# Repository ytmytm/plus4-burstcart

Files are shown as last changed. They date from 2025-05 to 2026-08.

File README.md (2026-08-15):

# BurstCart - Fast serial cartridge for C16/116/Plus4

This Plus/4 cartridge implements both fast serial burst for 1570/1571/1581 drives and a parallel connection for the 1541 drive, enabling high-speed data transfers.

<a href="https://www.youtube.com/watch?v=kfF7x9RVxz8" target="_blank">
 BurstCart and Parobek fastloaders demo
 <p><small>Click for video</small></p>
</a>

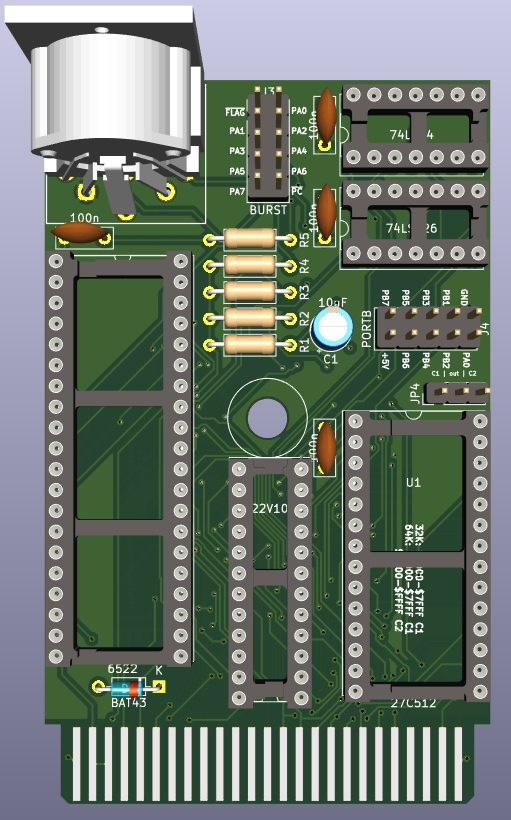
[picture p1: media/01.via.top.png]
BurstCart VIA Version

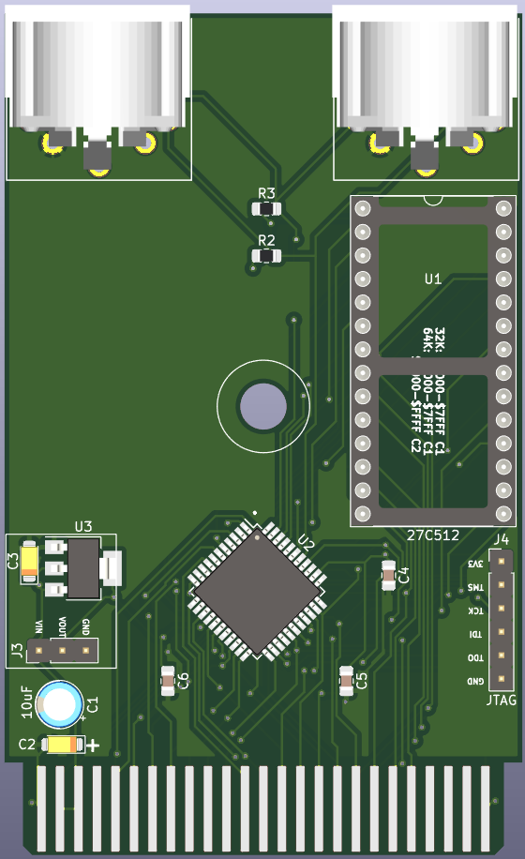
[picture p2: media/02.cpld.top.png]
BurstCart CPLD Version


## About

The project started as a response to a question from **[Plus/4 World Forum](https://plus4world.powweb.com/forum.php?postid=52378)**.

In order to use the Burst (fast serial) protocol as implemented on the C128, we need a bidirectional hardware serial port.

The published version uses VIA 6522 chips, which are still relatively easy to obtain. The additional logic addresses a VIA hardware bug that can lead to framing errors and lost bits when the serial port is externally clocked, as is the case with the fast serial burst protocol.

The single IEC port should be connected to the pass-through serial port on the last disk drive in the chain, looping back to the computer.

VIA Port A and lines CA1/CA2 are also used as a parallel connection for 1541 parallel burst with hardware handshake. The order of signals on the J3 connector for a ribbon cable is compatible with parallel cables known from the C64, particularly DolphinDOS.

VIA Port B is not used, except for bit 0, which controls the direction of the serial port.

Other attempts included in the repository are:

### CPLD

This is an attempt to drop legacy chips altogether.

Due to the limited number of gates, it only implements small parts of the CIA, such as timer A with a fixed rate, the hardware serial port, and the status register. The implementation does only what it necessary to make burst protocol work: to be able to send a byte via burst to enable burst protocol and to receive bytes on serial port with external clock.

### CIA (6526) - abandoned

This seemed obvious as CBM themselves added CIA just for this purpose to 1571. However, the timing differences made it impossible to use the CIA reliably with the screen on.

These chips are also hard to obtain.

The PCB had enough space for two IEC ports as a passthrough.

## Hardware

### VIA

KiCad 6.0 project files are available in the [`burstcart-via/kicad/`](burstcart-via/kicad/) directory.

Schematic is available as [`burstcart-via.pdf`](burstcart-via/kicad/plots/burstcart-via.pdf) in the `burstcart-via/kicad/plots/` directory.

Gerber files for manufacturing are available from [`burstcart-via/kicad/plots/`](burstcart-via/kicad/plots/) directory.

### CPLD

KiCad 6.0 project files are available in the [`burstcart-cpld/kicad/`](burstcart-cpld/kicad/) directory.

Schematic is available as [`burstcart-cpld.pdf`](burstcart-cpld/kicad/plots/burstcart-cpld-44.pdf) in the `burstcart-cpld/kicad/plots/` directory.

Gerber files for manufacturing are available from [`burstcart-cpld/kicad/plots/`](burstcart-cpld/kicad/plots/) directory.

## Firmware 

### VIA

The firmware for the GAL22V10 programmable logic device is provided as a compiled JEDEC file [`BURSTCART-VIA.jed`](burstcart-via/gal/BURSTCART-VIA.jed).

The source code for the GAL logic is written in CUPL and available as [`burstcart-via.pld`](burstcart-via/gal/burstcart-via.pld). This file contains the logic equations that implement the address decoding and serial port direction control.

The GAL firmware fixes VIA's address at `$FDA0-$FDAF` range.

### CPLD

The CPLD firmware is also provided as a compiled JEDEC file [`CIA.jed`](burstcart-cpld/hdl/ciasdr-hdl/cia.jed).

The source code is written in Verilog for XILINX ISE. All the project files are provided in [`ciasdr-hdl`](burstcart-cpld/hdl/ciasdr-hdl).

The firmware fixes CPLD address at `$FD90-$FD9F` range.

## Software

### EPROM

The GAL chip on the VIA version does not have enough space to support 64K ROMs as C1/C2 cartridges, so only 32K is visible to the computer at any given time as C1.

You can use 32K chips; for the 64K version, the 32K banks can be selected using a switch connected to JP4.

The CPLD version can address both C1 and C2 cartridges, so all 64K is available.

The **[Parobek](https://github.com/ytmytm/plus4-parobek)** project provides a ROM that supports various fastloaders for BurstCart:

- autodetected fast serial burst for 1570/1571/1581
- parallel cable loader for 1541
- even faster parallel cable loader for 1541 with [1541-RAMBOard](https://github.com/ytmytm/1541-RAMBOardII) patched ROM
- [tcbm2sd fastloader](https://github.com/ytmytm/plus4-tcbm2sd) for both device numbers
- 1551 fastloader for both device numbers
- DOS wedge
- embedded Directory Browser

Be sure to choose correct ROM version - for VIA or CPLD.

## VIA PCB jumpers

There are three jumpers on the VIA PCB:

- JP1 determines how the `/IRQ` line is connected to the VIA. For W65C22S, it should go through a diode; for all other 6522 versions, it can be connected directly, and `D1` can be omitted.
- JP2 chooses the clock for VIA - `phi0` or `phi2` (default)
- JP3 chooses the clock for GAL - `phi0` (default) or `phi2`
- JP4 controls line A15 for the EPROM and chooses which 32K half of a 64K ROM will appear as cartridge C1

## Theory of operation

### Fast serial

The burst mode protocol were originally developed by Commodore for the C128 and 1571/1581 drives. It uses the hardware serial port available on VIA and CIA chips. The data is transmitted over the IEC data line, with the hardware clock controlled by the sender and routed through the (otherwise unused) SRQ line. Changes in the IEC clock line are used as a handshake signal.

This was not available on the 1541 due to a hardware bug in the 6522 chips.

This project fixes the bug with a 74LS74 latch. Another 74LS126 chip is needed to buffer the input/output and provide the necessary open collector outputs on the external side for both the clock and data lines. The direction of the bus is controlled by port B bit 0 (PB0) pulled high to make it input as a default after reset.

The single IEC port on the VIA cartridge has only the hardware data and clock lines connected, as well as a common GND.

The CPLD cartridge has dual daisy-chained IEC ports, so you can connect the computer's serial port to cartridge and continue from the second port to all other IEC devices.

### Parallel cable

The 1541 drive's VIA#1 port A is unused. On the C64, this is connected to the User Port, along with two hardware handshake lines, providing the fastest possible connection between the VIA and CIA.

Here we connect it to port A as well. Note that on the BurstCart side, the handshake lines are connected to CA1/CA2 corresponding to port A, but to CA2/CB1 on the 1541 side. This is not symmetrical because on the 1541, CA1 from VIA#1 was already used for another purpose.

## Additional Resources

All files necessary for manufacturing, including Gerbers, schematic, GAL firmware, and ROM, can be found in the [GitHub releases section](https://github.com/ytmytm/plus4-burstcart/releases).

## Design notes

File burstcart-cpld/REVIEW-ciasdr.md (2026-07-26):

# Dlaczego burstcart-cpld-44 gubi bajty i przesuwa bity

Analiza z 2026-07-26. Hipoteza z `PROMPT.txt` była trafna w jednym punkcie
(problem jest w firmware CPLD), ale **nietrafna w założeniu, że układ KiCad
odpowiada temu, co robi wersja VIA** — płytki różnią się elektrycznie i to jest
sedno sprawy.

---

## 1. Fakty ustalone z dokumentacji i ROMu (nie domysły)

### Co robi stacja 1581

Z ROMu 1581 (`1581-rom/AAY1581.TXT`), inicjacja w `$AF3A`:

```
AF3A: A9 00     LDA #$00         Timer A fuer FSM auf $0006 stellen
AF3C: 8D 05 40  STA $4005
AF3F: A9 06     LDA #$06
AF41: 8D 04 40  STA $4004
```

Timer A = 6 przy 2 MHz → underflow co 3,5 µs, CNT przełącza się na każdym
underflow, więc:

| parametr | wartość |
|---|---|
| okres bitu | **7 µs** |
| faza CNT wysoka / niska | 3,5 µs / 3,5 µs (50 % duty) |
| bajt (8 bitów) | 56 µs |
| turnaround stacji (ack → pierwszy bit) | ~27 µs |
| kolejność bitów | MSB first |

Nadajnik to sprzętowy SDR w CIA, nigdzie nie ma bit-bangingu SRQ. Blok
fastload (`$B977`) wysyła bajty przez `$01FC → $BA40`, a handshake to
**porównanie poziomu**, nie zbocze: `EOR $76 / AND #$04` — więc ack hosta
może przyjść w dowolnym momencie i nie zginie.

### Które zbocze i gdzie są dane

Datasheet 6526 (`docs/mos_6526_cia_preliminary_nov_1981.pdf`, s. 7), dosłownie:

> „In input mode, data on the SP pin is shifted into the shift register **on the
> rising edge** of the signal applied to the CNT pin."
>
> „Data shifted out becomes valid **on the falling edge of CNT** and remains
> valid until the next falling edge."

To samo u Ojali (`docs/c=hacking19.txt`): *„A bit is valid between clock falling
edges, the data is sampled during rising edges."*

Czyli: dane zmieniają się na zboczu **opadającym**, a zbocze **narastające**
leży dokładnie w środku bitu, z 3,5 µs marginesu z każdej strony. `posedge CNT`
w `ciasdr.v` jest więc semantycznie **poprawne** — i nie ma żadnej inwersji na
ścieżce (SP/CNT są open-drain i idą wprost na magistralę IEC, potwierdzone i w
datasheecie, i w schematach obu płytek). Polaryzacja **nie jest** problemem.

### Czym różni się pracująca płytka VIA — to jest klucz

Ze schematów (`*.kicad_sch` + netlisty z `.kicad_pcb`):

| ścieżka | burstcart-via (działa) | burstcart-cpld-44 (nie działa) |
|---|---|---|
| SRQ → zegar SR | `IEC_SRQ` → **74LS74 (U2A), D=SRQ, CLK=/VIACLK (Phi2)** → 74LS126 (U5B) → CB1 (pin 18) | `IEC_SRQ` → **wprost na pin 43 CPLD** |
| DATA → dane SR | `IEC_DATA` → 74LS126 (U5C) → CB2 (pin 19) | `IEC_DATA` → wprost na pin 38 |
| pull-up | R3/R2 3k3 → VCC | R3/R2 3k3 → VCC (identyczne) |
| inwersje | 0 | 0 |
| złącza IEC | jedno (J1) | **dwa (J1+J2, przelotka)** |

Na płytce VIA jest **przerzutnik 74LS74, który resynchronizuje SRQ do zegara
systemowego, zanim trafi na CB1**. To nie przypadek — `docs/via.txt` mówi
wprost:

> „To remedy it, put the external clock signal into the D input of a 74HC74
> flip-flop, run the flip-flop's Q output to the 6522's CB1 pin, and clock the
> flip-flop with phase 0 or phase 2."

A sam 6522 dodatkowo próbkuje synchronicznie. Datasheet W65C22 §2.12.4 (tryb
011, ten używany w `burst-via.asm`: `lda #%00001100 / sta via_acr`):

> „Note that data is shifted **during the first PHI2 clock cycle following the
> positive going edge of the CB1 shift pulse**. For this reason, data must be
> held stable during the first full cycle following CB1 going high."

I druga, równie ważne zdanie z tego samego akapitu:

> „**Reading or writing the SR resets IFR2 and initializes the counter to count
> another eight pulses.**"

---

## 2. Trzy usterki w `ciasdr.v`

### Usterka 1 (główna): surowa linia IEC SRQ użyta jako zegar sprzętowy

```verilog
always @(posedge CNT or negedge sp_in_reset_n) begin
    ...
    shift_in <= {shift_in[6:0], SP};
```

`CNT` to pin 43, zmapowany przez fitter na **globalną sieć zegarową GCK1**
(`cia.rpt:29`). Czyli rejestr przesuwny jest taktowany bezpośrednio linią
magistrali IEC, która:

* jest open-drain z pull-upem 3k3 do +5 V, obciążonym kablem i **dwoma**
  złączami IEC → zbocze narastające to wolna rampa RC rzędu 0,5–1 µs;
* wchodzi na wejście zegarowe **XC9572XL, które nie ma histerezy** (a to część
  3,3 V, więc próg jest jeszcze niżej względem 5 V rampy).

Każde zakłócenie na tej rampie przekracza próg po raz drugi i **taktuje rejestr
przesuwny ponownie**. Jeden dodatkowy impuls = jeden fantomowy bit = bajt
obrócony, flaga „bajt gotowy" wypada o zbocze za wcześnie, i od tego momentu
cały strumień jest przesunięty. Dokładnie objaw z `PROMPT.txt`.

Żaden z prawdziwych układów tego nie robi: 6522 próbkuje w rytmie PHI2, a
płytka VIA dodaje jeszcze 74LS74. Prawdziwe CIA to NMOS na tej właśnie
magistrali. CPLD z propagacją ~5 ns na rampie 1 µs — nie.

### Usterka 2: licznik bitów nigdy się nie resynchronizuje

Stary licznik `shift_in_counter` był zerowany **tylko** przez RESET albo przez
przełączenie portu na wyjście (`sp_in_reset_n = RESET_n && !sp_output`). W
trakcie całej transmisji software nie pisze do `cpldbase+1`, więc licznik biegnie
swobodnie modulo 8. Pojedyncze zgubione albo dodatkowe zbocze przesuwa **na
zawsze** wszystkie kolejne bajty — nie ma bitu startu, jedynym framingiem jest
ten licznik.

Że to realne ryzyko, wie sam ROM 1581 (`AAY1581.TXT`, blok patchy
„FSM: Schieberegister initialisieren"):

> „Wenn erst der Computer und dann die 1581 eingeschaltet wird, kann es
> vorkommen, dass im Computer irrtuemlich ein paar Bits ‚empfangen' werden.
> **Bei einer Datenuebertragung wuerde der Computer anschliessend alle Bits
> verschoben empfangen.**"

Dlatego stacja przed **każdą** transmisją przełącza kierunek SDR 0→1→0
(`$DBC7`/`$DBE0`), żeby wyzerować swój własny licznik. Dodatkowo stacja wysyła
przed transferem bajt-budzik `$00` (`$AC9D`) i owija bajty statusu w kolejne
przełączenia kierunku — na drucie jest więc więcej ruchu, niż widzi pętla
loadera.

6522 jest odporny, bo zeruje licznik przy każdym czytaniu SR — i to jest powód,
dla którego wersja VIA sama się leczy.

### Usterka 3: flaga statusu próbkowała magistralę na złym zboczu

```verilog
always @(posedge E_CLK or negedge RESET_n) begin        // <-- posedge
    ...
    else if (seladdr && RW && A[0] == REG_SDR)
        shift_complete_latched <= 1'b0;
```

Na Plus/4 przy narastającym zboczu PHI0 magistrala adresowa **jeszcze nie
trzyma adresu CPU**. Wszystkie zapisy rejestrów w tym samym pliku używają
`negedge E_CLK` — i one działają (potwierdzone: rejestry dają się zapisywać, a
Twoje notatki w `docs/burstc64.txt` zapisują regułę Plus/4:
*„drivedatain: adres+<WRITE>+negedge pla[6] (zapis do rejestru)"*). Czyli
„skasuj flagę przy odczycie rejestru danych" wypadało w złym momencie albo
wcale.

To jest **regresja wprowadzona później**: w raporcie fittera z 2026-03-07
(`cia.rpt`) ten sam przerzutnik jest jeszcze na `NOT E_CLK`, czyli na zboczu
opadającym. Ta sama wersja miała też dwustopniowy synchronizator
`req_sync1`/`req_sync2` na przejściu domen, którego w obecnym `ciasdr.v` już nie
ma.

### Uwaga na marginesie: plik JED nie odpowiada żadnemu źródłu

```
cia.jed             Date Extracted: Thu May 29 23:38:38 2025
cia — kopia.jed     Date Extracted: Thu May 29 00:23:47 2025
cia.jed-20250608    Date Extracted: Thu May 29 23:38:38 2025
```

Wszystkie trzy pliki programujące są z **28–29 maja 2025**, mimo że mtime
`cia.jed` to 2026-03-07. Raport fittera i `cia.vm6` są z 2026-03-07 12:55 i
zawierają `req_sync1`/`req_sync2`, których nie ma w żadnym `.v` na dysku, a samo
`ciasdr.v` było edytowane jeszcze później (22:16). Czyli **układ na płytce
zawiera logikę z 29 maja 2025, nie tę, którą debugujemy.** Warto to
uporządkować, zanim wyciągnie się wnioski z kolejnego testu na sprzęcie.

---

## 3. Symulacja

`sim/burstsim.py` i `sim/verify_new.py` modelują nadajnik 1581 (7 µs/bit, dane
na zboczu opadającym, handshake per bajt), pętlę `GetByte`/`GetAndStore` z
`parobek/burst-cpld.asm` z prawdziwymi liczbami cykli 6502, oraz trzy odbiorniki:
stary `ciasdr.v`, nowy `ciasdr.v` i układ z płytki VIA (74LS74 + 6522 tryb 011).

`verify_new.py` to model **cyklicznie dokładny** — po przepisaniu całego
projektu na jedną domenę (`negedge E_CLK`) jedna ewaluacja na okres PHI0
odtwarza RTL dokładnie.

```
PHI0 = 0.887 MHz (1128 ns), 1581 bit period 7.0 us (3.10 PHI0 cycles per CNT phase)

1. wake-up handshake (CRA=$40, SDR=$08, poll bit 3): flag raised after 30 PHI0
   cycles, 8 CNT pulses generated

2. clean 1581 stream
   new ciasdr.v          recv=24/24 correct=24 wrong_at=[]                 -> PASS
   old ciasdr.v          recv=24/24 correct=24 wrong_at=[]                 -> PASS

3. 200 ns threshold re-crossing on every SRQ rising edge
   new ciasdr.v          recv=24/24 correct=24 wrong_at=[]                 -> PASS
   old ciasdr.v          recv=24/24 correct= 0 wrong_at=[0,1,2,3,4,5]      -> FAIL

4. one stray SRQ pulse after byte 5 (recovery behaviour)
   new ciasdr.v          recv=24/24 correct=24 wrong_at=[]                 -> PASS
   old ciasdr.v          recv=24/24 correct= 6 wrong_at=[6,7,8,9,10,11]    -> FAIL
```

Test 3 to usterka 1: **jedno przekroczenie progu o szerokości 200 ns na każdym
zboczu narastającym psuje wszystkie bajty**, a dla wersji synchronicznej jest
całkowicie niewidoczne. Test 4 to usterka 2: jeden zabłąkany impuls psuje stary
projekt **od tego bajtu do końca**, nowy odzyskuje synchronizację natychmiast.

Zamiatanie szerokości zakłócenia (`burstsim.py`, sekcja sweep) pokazuje granice:

```
  glitch      PHI0 |   cpld_old          cpld_new           via_ref
    50ns  0.887MHz |       PASS              PASS              PASS
   100ns  0.887MHz |       FAIL              PASS              PASS
   200ns  0.887MHz |       FAIL              PASS              PASS
   400ns  0.887MHz |       FAIL              FAIL              FAIL
```

Nowa wersja ma **dokładnie taką samą odporność jak płytka, która działa** —
i to był cel, nie „lepiej niż VIA". Przy zakłóceniach ≳1/3 okresu PHI0 obie
padają jednakowo; to obszar, w którym pomoże już tylko sprzęt.

Osobny test w `burstsim.py` (przypadek E) pokazuje usterkę 3 w izolacji: przy
czystym sygnale, ale próbkowaniu magistrali w złym momencie, stary projekt
odbiera **0 bajtów** — czyli zawisa, tak jak w notatce z 20250530.

---

## 4. Co zostało zmienione w `ciasdr.v`

Cały projekt jest teraz w **jednej domenie zegarowej: `negedge E_CLK` (PHI0)**.

1. `CNT` i `SP` są synchronizowane do PHI0 (`cnt_s1/s2/s3`, `sp_s1/s2`) i zbocze
   narastające jest detekowane w tej domenie. `sp_s2` jest próbkowane w tym samym
   cyklu, w którym `cnt_s2` pierwszy raz zobaczył CNT wysoko — czyli w granicach
   1,2 µs od zbocza, przy 3,5 µs ważności danych z każdej strony.
   Budżet: faza CNT = 3,5 µs = **3,10 cyklu PHI0** przy 0,886 MHz i 6,2 przy
   1,77 MHz — sprawdzone symulacją na obu prędkościach (ekran włączony/wyłączony).
2. `shift_in_counter` jest zerowany przy **każdym dostępie do rejestru danych**
   (`acc_sdr`), czyli framing resynchronizuje się raz na bajt — zachowanie 6522.
   Nadal zerowany też przy przełączeniu na wyjście (zachowanie prawdziwego CIA,
   na którym opiera się ROM 1581).
3. `shift_complete_latched` jest na `negedge E_CLK`, tak samo jak zapisy
   rejestrów, które działają.
4. Efekt uboczny: `CNT` przestaje być zegarem, więc zwalnia globalną sieć GCK1.
   Ścieżka nadawania straciła niepotrzebny bufor drugiego bajtu
   (`sdr_out_new_data`) — software wysyła tylko jeden bajt-budzik, którego
   zawartość nie ma znaczenia. Liczba przerzutników bez zmian (47), liczba
   termów iloczynowych spada, więc powinno zmieścić się swobodniej niż
   poprzednie 66/72 makrokomórek.

Poprzednia wersja jest w `ciasdr-orig-backup.v`.

## 5. Czego nie sprawdziłem / co zrobić dalej

* **Nie przesyntetyzowałem projektu** — na tej maszynie nie ma ISE. Trzeba
  przepuścić przez XST + cpldfit i sprawdzić, czy mieści się w 72 makrokomórkach
  (przewiduję tak, ale FB1/FB2/FB4 były wyczerpane przy 18/18).
* **Zaprogramować świeży JED** — obecny jest z maja 2025 i nie odpowiada
  żadnemu źródłu w projekcie.
* Jeśli po tym nadal będą błędy: dodać na płytce to, co ma wersja VIA, czyli
  przerzutnik resynchronizujący SRQ (74HC74 taktowany PHI0) albo bufor z
  histerezą (74HCT14 / 74LVC1G17) na SRQ i DATA przed CPLD. Firmware tego już
  nie potrzebuje, ale przy zakłóceniach >400 ns nic innego nie pomoże.
* Rozważyć dołożenie `!MUX` do dekodera zapisu i kasowania flagi. **Nie zrobiłem
  tego celowo** — zapisy rejestrów bez `!MUX` demonstracyjnie działają, więc
  dokładanie tam warunku to ryzyko regresji. Warto spróbować tylko jeśli po
  powyższych zmianach zostaną sporadyczne błędy.

---

## 6. Zgodność z `parobek/burst-cpld.asm` — kod 6502 bez zmian

Mapa rejestrów, semantyka flagi i bitu kierunku są nietknięte:

| adres | R | W |
|---|---|---|
| `$FD90` (`cpldbase`) | dane odebrane (`sdr_in`); kasuje flagę **i resynchronizuje licznik bitów** | dane do wysłania, start nadawania |
| `$FD91` (`cpldbase+1`) | bit 6 = kierunek, bit 3 = shift complete; **nie** kasuje flagi | bit 6 = kierunek; kasuje flagę |

Jedyna zmiana widoczna dla software'u to zerowanie licznika bitów przy dostępie
do `$FD90` — a to jest dokładnie to, co loader i tak robi raz na bajt
(`ldy cpldbase` w `GetByte`), więc wychodzi „za darmo". Dodatkowo `lda cpldbase`
przed `jsr ToggleClk` na starcie transferu ustawia framing tuż przed pierwszym
bajtem.

`sim/test_init.py` odtwarza dosłownie sekwencję `InitBurst` + detekcję CPLD z
`burst-cpld.asm` (z prawdziwymi liczbami cykli) na modelu nowego RTL:

```
InitBurst:
   [ok ] sta $FD91,#$00  -> sp_output = 0 (serial IN)
   [ok ]                 -> flag cleared
LoadBurst, CPLD presence detection:
   [ok ] lda $FD91 / cmp $FD91  -> $00 == $00 (branch not taken)
   [ok ] sta $FD91,#$40 / cmp $FD91 -> $40 == $40
   [ok ] sta $FD90,#$08 -> transmit started
   [ok ] wait loop  -> flag raised at Y=5 (timeout is Y=128)
   [ok ] sta $FD91,#$00 -> back to serial IN
   [ok ]                -> flag cleared, ready to receive
   [ok ]                -> receive bit counter aligned at 0

RESULT: burst-cpld.asm needs NO change
```

Czyli: **wystarczy nowy JED.** Zmiana ROMu parobka nie jest potrzebna.

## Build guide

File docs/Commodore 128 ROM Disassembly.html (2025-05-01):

# Commodore 128 ROM Disassembly

done for The IDE64 Project by Soci/Singular (Kajtár Zsolt)
Version 4 (Jan 2002) Still preview!
Modified and with extended comments by Johann Klasek

Used firmware:

$4000-$7FFF: 318018-04

$8000-$BFFF: 318019-04

$C000-$FFFF: 318077-01

Send bugreports for the original version to <soci at c64.rulez.org>
Send bugreports to this version to <j+c64 at klasek DOT at>

See also C128 zero page (german) (https://www.c64-wiki.de/wiki/C128-Zeropagebelegung)

               * = $4000

; Cold Entry

4000: 4C 23 40	JMP $4023	; Basic Cold Start

; Warm Entry

4003: 4C 09 40	JMP $4009	; Basic Restart

; IRQ Entry

4006: 4C 4D A8	JMP $A84D	; IRQ Work

; Basic Restart

4009: 20 CC FF	JSR $FFCC	; (iclrch)      Restore I/O Vector [F226]
400C: 20 7A 41	JSR $417A	; Set Preconfig Registers
400F: 20 8D 41	JSR $418D	; Init Sprite Movement Tabs
4012: 20 12 41	JSR $4112	; Chime
4015: 20 38 52	JSR $5238	; Clear Stack & Work Area
4018: A9 00	LDA #$00
401A: 85 15	STA $15 	; Current I/O prompt flag

401C: 58	CLI
401D: 4C 37 4D	JMP $4D37	; Error or Ready

; Unused

4020: 00 FF FF               	; '{0}..'

; Basic Cold Start

4023: 20 7A 41	JSR $417A	; Set Preconfig Registers
4026: 20 51 42	JSR $4251	; Set Basic Links
4029: 20 45 40	JSR $4045	; Set-Up Basic Constants
402C: 20 9B 41	JSR $419B	; Print Startup Message
402F: AD 04 0A	LDA $0A04
4032: 09 01	ORA #$01
4034: 8D 04 0A	STA $0A04
4037: A2 03	LDX #$03
4039: 8E 00 0A	STX $0A00	; Restart System (BASIC Warm) [4000]
403C: A2 FB	LDX #$FB
403E: 9A	TXS
403F: 20 56 FF	JSR $FF56	; foenix
4042: 4C 1C 40	JMP $401C

; Set-Up Basic Constants

4045: A9 4C	LDA #$4C
4047: 85 56	STA $56
4049: 8D 18 12	STA $1218	; USR Program Jump [7D28]
404C: A9 28	LDA #$28
404E: A0 7D	LDY #$7D
4050: 8D 19 12	STA $1219
4053: 8C 1A 12	STY $121A
4056: A9 9F	LDA #$9F
4058: A0 84	LDY #$84
405A: 8D 7A 11	STA $117A	; Float-fixed Vector [849F]
405D: 8C 7B 11	STY $117B
4060: A9 3C	LDA #$3C
4062: A0 79	LDY #$79
4064: 8D 7C 11	STA $117C	; Fixed-float Vector [793C]
4067: 8C 7D 11	STY $117D
406A: A2 55	LDX #$55

406C: BD 78 42	LDA $4278,X
406F: 9D 7F 03	STA $037F,X
4072: CA	DEX
4073: D0 F7	BNE $406C
4075: 8E DF 03	STX $03DF	; FAC#1 Overflow
4078: 86 15	STX $15 	; Current I/O prompt flag
407A: 86 1A	STX $1A
407C: 8E 6F 11	STX $116F	; Trace Mode: FF = on
407F: 8E 00 1C	STX $1C00
4082: 86 76	STX $76 	; Graphics flag: FF = Graphics allocated
4084: 86 74	STX $74 	; Auto line number increment
4086: 86 75	STX $75
4088: 8E 6B 11	STX $116B	; Double Width Flag
408B: 8E 6A 11	STX $116A	; SCALE Mode Flag
408E: 8E 6C 11	STX $116C	; Box Fill Flag
4091: 8E 1B 12	STX $121B
4094: 8E 1C 01	STX $011C
4097: 8E 76 12	STX $1276	; Collision IRQ Task Table
409A: 8E 77 12	STX $1277
409D: 8E 78 12	STX $1278
40A0: 8E 7F 12	STX $127F	; Collision Mask
40A3: A0 58	LDY #$58

40A5: 99 7E 11	STA $117E,Y	; Sprite Motion Tables (8 x 11 bytes)
40A8: 88	DEY
40A9: 10 FA	BPL $40A5
40AB: E8	INX
40AC: 8E FD 01	STX $01FD
40AF: 8E FC 01	STX $01FC
40B2: A2 0F	LDX #$0F
40B4: 8E D5 03	STX $03D5	; Current Bank For SYS, POKE, PEEK
40B7: A2 0D	LDX #$0D
40B9: 86 86	STX $86 	; Graphic foreground color (13)
40BB: A2 01	LDX #$01
40BD: 86 84	STX $84 	; Multicolor 1 (1)
40BF: A2 02	LDX #$02
40C1: 86 85	STX $85 	; Multicolor 2 (2)
40C3: 20 5C 6A	JSR $6A5C	; Log Current Colors
40C6: A2 1B	LDX #$1B
40C8: 86 18	STX $18
40CA: A2 01	LDX #$01
40CC: A0 1C	LDY #$1C
40CE: 86 2D	STX $2D 	; Pointer: Start-of-BASIC (bank 0)
40D0: 84 2E	STY $2E
40D2: A9 00	LDA #$00
40D4: A0 04	LDY #$04
40D6: 85 2F	STA $2F 	; Pointer: Start-of-variables (bank 1)
40D8: 84 30	STY $30
40DA: A9 00	LDA #$00
40DC: A0 FF	LDY #$FF
40DE: 8D 12 12	STA $1212	; Basic Program Limit [FF00]
40E1: 8C 13 12	STY $1213
40E4: A9 00	LDA #$00
40E6: A0 FF	LDY #$FF
40E8: 85 39	STA $39 	; Pointer: Limit-of-memory (bank 1)
40EA: 84 3A	STY $3A
40EC: A2 3F	LDX #$3F
40EE: A0 07	LDY #$07

40F0: 8A	TXA
40F1: 99 F8 07	STA $07F8,Y
40F4: CA	DEX
40F5: 88	DEY
40F6: 10 F8	BPL $40F0
40F8: A9 00	LDA #$00
40FA: A2 6C	LDX #$6C

40FC: 9D 7E 11	STA $117E,X	; Sprite Motion Tables (8 x 11 bytes)
40FF: CA	DEX
4100: 10 FA	BPL $40FC
4102: 20 12 41	JSR $4112	; Chime
4105: A9 D0	LDA #$D0
4107: 8D EC 11	STA $11EC	; CHRGEN ROM Page, Graphics Mode [D0]
410A: A9 D8	LDA #$D8
410C: 8D EB 11	STA $11EB	; CHRGEN ROM Page, Text Mode [D8]
410F: 4C D9 51	JMP $51D9

; Chime

4112: A9 20	LDA #$20
4114: A0 01	LDY #$01
4116: 8D 29 12	STA $1229
4119: 8C 2A 12	STY $122A
411C: A9 04	LDA #$04
411E: 8D 2B 12	STA $122B
4121: A9 10	LDA #$10
4123: 8D 22 12	STA $1222
4126: A9 00	LDA #$00
4128: 8D 04 D4	STA $D404
412B: 8D 0B D4	STA $D40B
412E: 8D 12 D4	STA $D412
4131: 8D FD 12	STA $12FD
4134: A9 0F	LDA #$0F
4136: 8D 74 12	STA $1274
4139: 8D 75 12	STA $1275
413C: 8D 18 D4	STA $D418
413F: A0 1D	LDY #$1D

4141: B9 11 70	LDA $7011,Y	; Envelope A/D Patterns
4144: 99 3F 12	STA $123F,Y
4147: 88	DEY
4148: 10 F7	BPL $4141
414A: A2 09	LDX #$09

414C: BD 2F 70	LDA $702F,X	; Chime Seq
414F: 9D 67 12	STA $1267,X
4152: CA	DEX
4153: 10 F7	BPL $414C
4155: 8E 85 12	STX $1285
4158: 8E 86 12	STX $1286
415B: 8E 87 12	STX $1287
415E: 8E 24 12	STX $1224
4161: 8E 26 12	STX $1226
4164: 8E 28 12	STX $1228
4167: A0 02	LDY #$02
4169: 8C 2F 12	STY $122F

416C: A2 00	LDX #$00
416E: 20 B2 6E	JSR $6EB2	; Set SID Sound
4171: CE 2F 12	DEC $122F
4174: 10 F6	BPL $416C
4176: EE 2F 12	INC $122F
4179: 60	RTS

; Set Preconfig Registers

417A: 20 45 A8	JSR $A845	; Set Bank 15
417D: A2 03	LDX #$03

417F: BD 89 41	LDA $4189,X	; Registers For $D501
4182: 9D 01 D5	STA $D501,X
4185: CA	DEX
4186: 10 F7	BPL $417F
4188: 60	RTS

; Registers For $D501

4189: 3F 7F 01 41            	; '?..a'

; Init Sprite Movement Tabs

418D: A9 00	LDA #$00
418F: A0 07	LDY #$07

4191: BE D9 6D	LDX $6DD9,Y	; Sprite Motion Table Offsets
4194: 9D 7E 11	STA $117E,X	; Sprite Motion Tables (8 x 11 bytes)
4197: 88	DEY
4198: 10 F7	BPL $4191
419A: 60	RTS

; Print Startup Message

419B: A0 00	LDY #$00

419D: B9 BB 41	LDA $41BB,Y	; Startup Message
41A0: C9 40	CMP #$40
41A2: D0 0E	BNE $41B2
41A4: 24 D7	BIT $D7 	; 40 / 80 columns:  0 = 40, 128 = 80
41A6: 10 0D	BPL $41B5
41A8: A2 13	LDX #$13

41AA: A9 20	LDA #$20
41AC: 20 69 92	JSR $9269	; Call 'chrout'
41AF: CA	DEX
41B0: D0 F8	BNE $41AA

41B2: 20 69 92	JSR $9269	; Call 'chrout'

41B5: C8	INY
41B6: C0 96	CPY #$96
41B8: D0 E3	BNE $419D
41BA: 60	RTS

; Startup Message

41BB: 93 0D 40 20 43 4F 4D 4D	; '{CLR}{CR}@ comm'
41C3: 4F 44 4F 52 45 20 42 41	; 'odore ba'
41CB: 53 49 43 20 56 37 2E 30	; 'sic v7.0'
41D3: 20 31 32 32 33 36 35 20	; ' 122365 '
41DB: 42 59 54 45 53 20 46 52	; 'bytes fr'
41E3: 45 45 0D 40 20 20 20 28	; 'ee{CR}@   ('
41EB: 43 29 31 39 38 36 20 43	; 'c)1986 c'
41F3: 4F 4D 4D 4F 44 4F 52 45	; 'ommodore'
41FB: 20 45 4C 45 43 54 52 4F	; ' electro'
4203: 4E 49 43 53 2C 20 4C 54	; 'nics, lt'
420B: 44 2E 0D 40 20 20 20 20	; 'd.{CR}@    '
4213: 20 20 20 20 20 28 43 29	; '     (c)'
421B: 31 39 37 37 20 4D 49 43	; '1977 mic'
4223: 52 4F 53 4F 46 54 20 43	; 'rosoft c'
422B: 4F 52 50 2E 0D 40 20 20	; 'orp.{CR}@  '
4233: 20 20 20 20 20 20 20 20	; '        '
423B: 20 41 4C 4C 20 52 49 47	; ' all rig'
4243: 48 54 53 20 52 45 53 45	; 'hts rese'
424B: 52 56 45 44 0D 00      	; 'rved{CR}{0}'

; Set Basic Links

4251: A2 11	LDX #$11

4253: BD 67 42	LDA $4267,X	; Basic Links for $0300
4256: 9D 00 03	STA $0300,X	; Error Message Link [4D3F]
4259: CA	DEX
425A: 10 F7	BPL $4253
425C: A9 78	LDA #$78
425E: 8D FC 02	STA $02FC	; Function Execute Hook [4C78]
4261: A9 4C	LDA #$4C
4263: 8D FD 02	STA $02FD
4266: 60	RTS

; Basic Links for $0300

4267: 3F 4D	.WORD $4D3F	; Error Message
4269: C6 4D	.WORD $4DC6	; BASIC Warm Start
426B: 0D 43	.WORD $430D	; Crunch BASIC Tokens
426D: 51 51	.WORD $5151	; Print Tokens
426F: A2 4A	.WORD $4AA2	; Start New BASIC Code
4271: DA 78	.WORD $78DA	; Get Arithmetic Element
4273: 21 43	.WORD $4321	; Crunch FE
4275: CD 51	.WORD $51CD	; List FE
4277: A9 4B	.WORD $4BA9	; Execute FE

; Chrget for $0380

4279: E6 3D	INC $3D 	; Textpointer: BASIC work point (chrget)
427B: D0 02	BNE $427F
427D: E6 3E	INC $3E

427F: 8D 01 FF	STA $FF01
4282: A0 00	LDY #$00
4284: B1 3D	LDA ($3D),Y	; Textpointer: BASIC work point (chrget)
4286: 8D 03 FF	STA $FF03
4289: C9 3A	CMP #$3A
428B: B0 0A	BCS $4297
428D: C9 20	CMP #$20
428F: F0 E8	BEQ $4279	; Chrget for $0380
4291: 38	SEC
4292: E9 30	SBC #$30
4294: 38	SEC
4295: E9 D0	SBC #$D0

4297: 60	RTS

; Fetch From RAM Bank 0 for $039F

4298: 8D A6 03	STA $03A6
429B: 8D 01 FF	STA $FF01
429E: B1 00	LDA ($00),Y
42A0: 8D 03 FF	STA $FF03
42A3: 60	RTS

; Fetch From RAM Bank 1 for $03AB

42A4: 8D B2 03	STA $03B2
42A7: 8D 02 FF	STA $FF02
42AA: B1 00	LDA ($00),Y
42AC: 8D 04 FF	STA $FF04
42AF: 60	RTS

; Index1 Indirect Fetch From RAM Bank 1 for $03B7

42B0: 8D 02 FF	STA $FF02
42B3: B1 24	LDA ($24),Y
42B5: 8D 04 FF	STA $FF04
42B8: 60	RTS

; Index2 Indirect Fetch From RAM Bank 0 for $03C0

42B9: 8D 01 FF	STA $FF01
42BC: B1 26	LDA ($26),Y
42BE: 8D 03 FF	STA $FF03
42C1: 60	RTS

; Txtptr Fetch From RAM Bank 0 for $03C9

42C2: 8D 01 FF	STA $FF01
42C5: B1 3D	LDA ($3D),Y	; Textpointer: BASIC work point (chrget)
42C7: 8D 03 FF	STA $FF03
42CA: 60	RTS

; Fills $03D2-$03D4 with $00 (Numeric Constant For BASIC?)

42CB: 00 00 00               	; '{0}{0}{0}'

; Get From ($50) Bank1

42CE: A9 50	LDA #$50
42D0: 4C AB 03	JMP $03AB	; Fetch From RAM Bank 1

; Get From ($3f) Bank1

42D3: A9 3F	LDA #$3F
42D5: 4C AB 03	JMP $03AB	; Fetch From RAM Bank 1

; Get From ($52) Bank1

42D8: A9 52	LDA #$52
42DA: 4C AB 03	JMP $03AB	; Fetch From RAM Bank 1

; Get From ($5c) Bank0

42DD: A9 5C	LDA #$5C
42DF: 4C 9F 03	JMP $039F	; Fetch From RAM Bank 0

; Get From ($5c) Bank1

42E2: A9 5C	LDA #$5C
42E4: 4C AB 03	JMP $03AB	; Fetch From RAM Bank 1

; Get From ($66) Bank1

42E7: A9 66	LDA #$66
42E9: 4C AB 03	JMP $03AB	; Fetch From RAM Bank 1

; Get From ($61) Bank0

42EC: A9 61	LDA #$61
42EE: 4C 9F 03	JMP $039F	; Fetch From RAM Bank 0

; Get From ($70) Bank0

42F1: A9 70	LDA #$70
42F3: 4C 9F 03	JMP $039F	; Fetch From RAM Bank 0

; Get From ($70) Bank1

42F6: A9 70	LDA #$70
42F8: 4C AB 03	JMP $03AB	; Fetch From RAM Bank 1

; Get From ($50) Bank1

42FB: A9 50	LDA #$50
42FD: 4C AB 03	JMP $03AB	; Fetch From RAM Bank 1

; Get From ($61) Bank1

4300: A9 61	LDA #$61
4302: 4C AB 03	JMP $03AB	; Fetch From RAM Bank 1

; Get From ($24) Bank0

4305: A9 24	LDA #$24
4307: 4C 9F 03	JMP $039F	; Fetch From RAM Bank 0

; Crunch Tokens

430A: 6C 04 03	JMP ($0304)	; Crunch BASIC Tokens Link [430D]

; Crunch BASIC Tokens

430D: A5 3D	LDA $3D 	; Textpointer: BASIC work point (chrget)
430F: 48	PHA
4310: A5 3E	LDA $3E
4312: 48	PHA

4313: 20 86 03	JSR $0386	; CHRGOT entry
4316: 4C 1C 43	JMP $431C

4319: 20 80 03	JSR $0380	; CHRGET

431C: 90 FB	BCC $4319
431E: 6C 0C 03	JMP ($030C)	; Crunch FE Hook [4321]

; Crunch FE

4321: B0 03	BCS $4326
4323: 4C B2 43	JMP $43B2

4326: C9 00	CMP #$00
4328: F0 77	BEQ $43A1
432A: C9 3A	CMP #$3A
432C: F0 EB	BEQ $4319
432E: C9 3F	CMP #$3F
4330: D0 04	BNE $4336
4332: A9 99	LDA #$99
4334: D0 50	BNE $4386

4336: C9 80	CMP #$80
4338: 90 0B	BCC $4345
433A: C9 FF	CMP #$FF
433C: F0 DB	BEQ $4319
433E: A0 01	LDY #$01
4340: 20 CC 43	JSR $43CC	; Move Down Input Buffer
4343: F0 CE	BEQ $4313

4345: C9 22	CMP #$22
4347: D0 0D	BNE $4356

4349: 20 80 03	JSR $0380	; CHRGET
434C: C9 00	CMP #$00
434E: F0 51	BEQ $43A1
4350: C9 22	CMP #$22
4352: F0 C5	BEQ $4319
4354: D0 F3	BNE $4349

4356: A9 46	LDA #$46
4358: A0 09	LDY #$09
435A: 20 E2 43	JSR $43E2	; Check Keyword Match
435D: 90 06	BCC $4365
435F: A9 81	LDA #$81
4361: A2 00	LDX #$00
4363: F0 4B	BEQ $43B0

4365: A9 46	LDA #$46
4367: A0 C9	LDY #$C9
4369: 20 E2 43	JSR $43E2	; Check Keyword Match
436C: 90 06	BCC $4374
436E: A9 81	LDA #$81
4370: A2 FF	LDX #$FF
4372: D0 3C	BNE $43B0

4374: A9 44	LDA #$44
4376: A0 17	LDY #$17
4378: 20 E2 43	JSR $43E2	; Check Keyword Match
437B: 90 9C	BCC $4319
437D: C0 00	CPY #$00
437F: F0 03	BEQ $4384
4381: 20 CC 43	JSR $43CC	; Move Down Input Buffer

4384: A5 0D	LDA $0D

4386: A0 00	LDY #$00
4388: 91 3D	STA ($3D),Y	; Textpointer: BASIC work point (chrget)
438A: C9 8F	CMP #$8F
438C: F0 0D	BEQ $439B
438E: C9 83	CMP #$83
4390: D0 87	BNE $4319
4392: 20 80 03	JSR $0380	; CHRGET
4395: 20 8F 52	JSR $528F	; Perform [data/bend]
4398: 4C 13 43	JMP $4313

439B: 20 80 03	JSR $0380	; CHRGET
439E: 20 9D 52	JSR $529D	; Perform [rem]

43A1: A6 3D	LDX $3D 	; Textpointer: BASIC work point (chrget)
43A3: 68	PLA
43A4: 85 3E	STA $3E
43A6: 68	PLA
43A7: 85 3D	STA $3D 	; Textpointer: BASIC work point (chrget)
43A9: 38	SEC
43AA: 8A	TXA
43AB: E5 3D	SBC $3D 	; Textpointer: BASIC work point (chrget)
43AD: A8	TAY
43AE: C8	INY
43AF: 60	RTS

43B0: 65 0D	ADC $0D

43B2: 48	PHA
43B3: 88	DEY
43B4: 20 CC 43	JSR $43CC	; Move Down Input Buffer
43B7: A9 FE	LDA #$FE
43B9: E8	INX
43BA: D0 02	BNE $43BE
43BC: A9 CE	LDA #$CE

43BE: A0 00	LDY #$00
43C0: 91 3D	STA ($3D),Y	; Textpointer: BASIC work point (chrget)
43C2: C8	INY
43C3: 68	PLA
43C4: 91 3D	STA ($3D),Y	; Textpointer: BASIC work point (chrget)
43C6: 20 80 03	JSR $0380	; CHRGET
43C9: 4C 19 43	JMP $4319

; Move Down Input Buffer

43CC: 18	CLC
43CD: 98	TYA
43CE: 65 3D	ADC $3D 	; Textpointer: BASIC work point (chrget)
43D0: 85 24	STA $24
43D2: A5 3E	LDA $3E
43D4: 69 00	ADC #$00
43D6: 85 25	STA $25
43D8: A0 FF	LDY #$FF

43DA: C8	INY
43DB: B1 24	LDA ($24),Y
43DD: 91 3D	STA ($3D),Y	; Textpointer: BASIC work point (chrget)
43DF: D0 F9	BNE $43DA
43E1: 60	RTS

; Check Keyword Match

43E2: 85 25	STA $25
43E4: 84 24	STY $24
43E6: A0 00	LDY #$00
43E8: 84 0D	STY $0D
43EA: 88	DEY

43EB: C8	INY

43EC: B1 3D	LDA ($3D),Y	; Textpointer: BASIC work point (chrget)
43EE: 38	SEC
43EF: F1 24	SBC ($24),Y
43F1: F0 F8	BEQ $43EB
43F3: C9 80	CMP #$80
43F5: F0 1B	BEQ $4412

43F7: B1 24	LDA ($24),Y
43F9: 30 03	BMI $43FE
43FB: C8	INY
43FC: D0 F9	BNE $43F7

43FE: C8	INY
43FF: E6 0D	INC $0D
4401: 18	CLC
4402: 98	TYA
4403: 65 24	ADC $24
4405: 85 24	STA $24
4407: 90 02	BCC $440B
4409: E6 25	INC $25

440B: 18	CLC
440C: A0 00	LDY #$00
440E: B1 24	LDA ($24),Y
4410: D0 DA	BNE $43EC

4412: 05 0D	ORA $0D
4414: 85 0D	STA $0D
4416: 60	RTS

; Keywords - Non prefixed

4417: 45 4E C4 46 4F D2 4E 45	; 'enDfoRne'
441F: 58 D4 44 41 54 C1 49 4E	; 'xTdatAin'
4427: 50 55 54 A3 49 4E 50 55	; 'put.inpu'
442F: D4 44 49 CD 52 45 41 C4	; 'TdiMreaD'
4437: 4C 45 D4 47 4F 54 CF 52	; 'leTgotOr'
443F: 55 CE 49 C6 52 45 53 54	; 'uNiFrest'
4447: 4F 52 C5 47 4F 53 55 C2	; 'orEgosuB'
444F: 52 45 54 55 52 CE 52 45	; 'returNre'
4457: CD 53 54 4F D0 4F CE 57	; 'MstoPoNw'
445F: 41 49 D4 4C 4F 41 C4 53	; 'aiTloaDs'
4467: 41 56 C5 56 45 52 49 46	; 'avEverif'
446F: D9 44 45 C6 50 4F 4B C5	; 'YdeFpokE'
4477: 50 52 49 4E 54 A3 50 52	; 'print.pr'
447F: 49 4E D4 43 4F 4E D4 4C	; 'inTconTl'
4487: 49 53 D4 43 4C D2 43 4D	; 'isTclRcm'
448F: C4 53 59 D3 4F 50 45 CE	; 'DsySopeN'
4497: 43 4C 4F 53 C5 47 45 D4	; 'closEgeT'
449F: 4E 45 D7 54 41 42 A8 54	; 'neWtab.t'
44A7: CF 46 CE 53 50 43 A8 54	; 'OfNspc.t'
44AF: 48 45 CE 4E 4F D4 53 54	; 'heNnoTst'
44B7: 45 D0 AB AD AA AF DE 41	; 'eP.....a'
44BF: 4E C4 4F D2 BE BD BC 53	; 'nDoR...s'
44C7: 47 CE 49 4E D4 41 42 D3	; 'gNinTabS'
44CF: 55 53 D2 46 52 C5 50 4F	; 'usRfrEpo'
44D7: D3 53 51 D2 52 4E C4 4C	; 'SsqRrnDl'
44DF: 4F C7 45 58 D0 43 4F D3	; 'oGexPcoS'
44E7: 53 49 CE 54 41 CE 41 54	; 'siNtaNat'
44EF: CE 50 45 45 CB 4C 45 CE	; 'NpeeKleN'
44F7: 53 54 52 A4 56 41 CC 41	; 'str.vaLa'
44FF: 53 C3 43 48 52 A4 4C 45	; 'sCchr.le'
4507: 46 54 A4 52 49 47 48 54	; 'ft.right'
450F: A4 4D 49 44 A4 47 CF 52	; '.mid.gOr'
4517: 47 D2 52 43 4C D2 80 4A	; 'gRrclR.j'
451F: 4F D9 52 44 4F D4 44 45	; 'oYrdoTde'
4527: C3 48 45 58 A4 45 52 52	; 'Chex.err'
452F: A4 49 4E 53 54 D2 45 4C	; '.instRel'
4537: 53 C5 52 45 53 55 4D C5	; 'sEresumE'
453F: 54 52 41 D0 54 52 4F CE	; 'traPtroN'
4547: 54 52 4F 46 C6 53 4F 55	; 'trofFsou'
454F: 4E C4 56 4F CC 41 55 54	; 'nDvoLaut'
4557: CF 50 55 44 45 C6 47 52	; 'OpudeFgr'
455F: 41 50 48 49 C3 50 41 49	; 'aphiCpai'
4567: 4E D4 43 48 41 D2 42 4F	; 'nTchaRbo'
456F: D8 43 49 52 43 4C C5 47	; 'XcirclEg'
4577: 53 48 41 50 C5 53 53 48	; 'shapEssh'
457F: 41 50 C5 44 52 41 D7 4C	; 'apEdraWl'
4587: 4F 43 41 54 C5 43 4F 4C	; 'ocatEcol'
458F: 4F D2 53 43 4E 43 4C D2	; 'oRscnclR'
4597: 53 43 41 4C C5 48 45 4C	; 'scalEhel'
459F: D0 44 CF 4C 4F 4F D0 45	; 'PdOlooPe'
45A7: 58 49 D4 44 49 52 45 43	; 'xiTdirec'
45AF: 54 4F 52 D9 44 53 41 56	; 'torYdsav'
45B7: C5 44 4C 4F 41 C4 48 45	; 'EdloaDhe'
45BF: 41 44 45 D2 53 43 52 41	; 'adeRscra'
45C7: 54 43 C8 43 4F 4C 4C 45	; 'tcHcolle'
45CF: 43 D4 43 4F 50 D9 52 45	; 'cTcopYre'
45D7: 4E 41 4D C5 42 41 43 4B	; 'namEback'
45DF: 55 D0 44 45 4C 45 54 C5	; 'uPdeletE'
45E7: 52 45 4E 55 4D 42 45 D2	; 'renumbeR'
45EF: 4B 45 D9 4D 4F 4E 49 54	; 'keYmonit'
45F7: 4F D2 55 53 49 4E C7 55	; 'oRusinGu'
45FF: 4E 54 49 CC 57 48 49 4C	; 'ntiLwhil'
4607: C5 00                  	; 'E{0}'

; Keywords - Prefix FE

4609: 42 41 4E CB 46 49 4C 54	; 'banKfilt'
4611: 45 D2 50 4C 41 D9 54 45	; 'eRplaYte'
4619: 4D 50 CF 4D 4F 56 53 50	; 'mpOmovsp'
4621: D2 53 50 52 49 54 C5 53	; 'RspritEs'
4629: 50 52 43 4F 4C 4F D2 52	; 'prcoloRr'
4631: 52 45 C7 45 4E 56 45 4C	; 'reGenvel'
4639: 4F 50 C5 53 4C 45 45 D0	; 'opEsleeP'
4641: 43 41 54 41 4C 4F C7 44	; 'cataloGd'
4649: 4F 50 45 CE 41 50 50 45	; 'opeNappe'
4651: 4E C4 44 43 4C 4F 53 C5	; 'nDdclosE'
4659: 42 53 41 56 C5 42 4C 4F	; 'bsavEblo'
4661: 41 C4 52 45 43 4F 52 C4	; 'aDrecorD'
4669: 43 4F 4E 43 41 D4 44 56	; 'concaTdv'
4671: 45 52 49 46 D9 44 43 4C	; 'erifYdcl'
4679: 45 41 D2 53 50 52 53 41	; 'eaRsprsa'
4681: D6 43 4F 4C 4C 49 53 49	; 'Vcollisi'
4689: 4F CE 42 45 47 49 CE 42	; 'oNbegiNb'
4691: 45 4E C4 57 49 4E 44 4F	; 'enDwindo'
4699: D7 42 4F 4F D4 57 49 44	; 'WbooTwid'
46A1: 54 C8 53 50 52 44 45 C6	; 'tHsprdeF'
46A9: 51 55 49 D4 53 54 41 53	; 'quiTstas'
46B1: C8 A0 46 45 54 43 C8 A0	; 'H.fetcH.'
46B9: 53 57 41 D0 4F 46 C6 46	; 'swaPofFf'
46C1: 41 53 D4 53 4C 4F D7 00	; 'asTsloW{0}'

; Keywords - Prefix CE

46C9: 50 4F D4 42 55 4D D0 50	; 'poTbumPp'
46D1: 45 CE 52 53 50 50 4F D3	; 'eNrsppoS'
46D9: 52 53 50 52 49 54 C5 52	; 'rspritEr'
46E1: 53 50 43 4F 4C 4F D2 58	; 'spcoloRx'
46E9: 4F D2 52 57 49 4E 44 4F	; 'oRrwindo'
46F1: D7 50 4F 49 4E 54 45 D2	; 'WpointeR'
46F9: 00                     	; '{0}'

; Unused

46FA: 00 00                  	; '{0}{0}'

; Action Vectors

46FC: CC 4B	.WORD $4BCD-1	; Perform [end]
46FE: F8 5D	.WORD $5DF9-1	; Perform [for]
4700: F3 57	.WORD $57F4-1	; Perform [next]
4702: 8E 52	.WORD $528F-1	; Perform [data/bend]
4704: 47 56	.WORD $5648-1	; Perform [input#]
4706: 61 56	.WORD $5662-1	; Perform [input]
4708: 7A 58	.WORD $587B-1	; Perform [dim]
470A: A8 56	.WORD $56A9-1	; Perform [read]
470C: C5 53	.WORD $53C6-1	; Perform [let]
470E: DA 59	.WORD $59DB-1	; Perform [goto]
4710: 9A 5A	.WORD $5A9B-1	; Perform [run]
4712: C4 52	.WORD $52C5-1	; Perform [if]
4714: C9 5A	.WORD $5ACA-1	; Perform [restore]
4716: CE 59	.WORD $59CF-1	; Perform [gosub]
4718: 61 52	.WORD $5262-1	; Perform [return]
471A: 9C 52	.WORD $529D-1	; Perform [rem]
471C: CA 4B	.WORD $4BCB-1	; Perform [stop]
471E: A2 53	.WORD $53A3-1	; Perform [on]
4720: 2C 6C	.WORD $6C2D-1	; Perform [wait]
4722: 2B 91	.WORD $912C-1	; Perform [load]
4724: 11 91	.WORD $9112-1	; Perform [save]
4726: 28 91	.WORD $9129-1	; Perform [verify]
4728: F9 84	.WORD $84FA-1	; Perform [def]
472A: E4 80	.WORD $80E5-1	; Perform [poke]
472C: 39 55	.WORD $553A-1	; Perform [print#]
472E: 59 55	.WORD $555A-1	; Perform [print]
4730: 5F 5A	.WORD $5A60-1	; Perform [cont]
4732: E1 50	.WORD $50E2-1	; Perform [list]
4734: F7 51	.WORD $51F8-1	; Perform [clr]
4736: 3F 55	.WORD $5540-1	; Perform [cmd]
4738: 84 58	.WORD $5885-1	; Perform [sys]
473A: 8C 91	.WORD $918D-1	; Perform [open]
473C: 99 91	.WORD $919A-1	; Perform [close]
473E: 11 56	.WORD $5612-1	; Perform [get]
4740: D5 51	.WORD $51D6-1	; Perform [new]
4742: 90 53	.WORD $5391-1	; Perform [else]
4744: 61 5F	.WORD $5F62-1	; Perform [resume]
4746: 4C 5F	.WORD $5F4D-1	; Perform [trap]
4748: B3 58	.WORD $58B4-1	; Perform [tron]
474A: B6 58	.WORD $58B7-1	; Perform [troff]
474C: EB 71	.WORD $71EC-1	; Perform [sound]
474E: C4 71	.WORD $71C5-1	; Perform [vol]
4750: 74 59	.WORD $5975-1	; Perform [auto]
4752: 33 5F	.WORD $5F34-1	; Perform [pudef]
4754: 59 6B	.WORD $6B5A-1	; Perform [graphic]
4756: A7 61	.WORD $61A8-1	; Perform [paint]
4758: D6 67	.WORD $67D7-1	; Perform [char]
475A: B6 62	.WORD $62B7-1	; Perform [box]
475C: 8D 66	.WORD $668E-1	; Perform [circle]
475E: 8C 65	.WORD $658D-1	; Perform [gshape]
4760: 2A 64	.WORD $642B-1	; Perform [sshape]
4762: 96 67	.WORD $6797-1	; Perform [draw]
4764: 54 69	.WORD $6955-1	; Perform [locate]
4766: E1 69	.WORD $69E2-1	; Perform [color]
4768: 78 6A	.WORD $6A79-1	; Perform [scnclr]
476A: 5F 69	.WORD $6960-1	; Perform [scale]
476C: 85 59	.WORD $5986-1	; Perform [help]
476E: DF 5F	.WORD $5FE0-1	; Perform [do]
4770: 89 60	.WORD $608A-1	; Perform [loop]
4772: 38 60	.WORD $6039-1	; Perform [exit]
4774: 7D A0	.WORD $A07E-1	; Perform [catalog/directory]
4776: 8B A1	.WORD $A18C-1	; Perform [dsave]
4778: A6 A1	.WORD $A1A7-1	; Perform [dload]
477A: 66 A2	.WORD $A267-1	; Perform [header]
477C: A0 A2	.WORD $A2A1-1	; Perform [scratch]
477E: 2E A3	.WORD $A32F-1	; Perform [collect]
4780: 45 A3	.WORD $A346-1	; Perform [copy]
4782: 6D A3	.WORD $A36E-1	; Perform [rename]
4784: 7B A3	.WORD $A37C-1	; Perform [backup]
4786: 86 5E	.WORD $5E87-1	; Perform [delete]
4788: F7 5A	.WORD $5AF8-1	; Perform [renumber]
478A: 09 61	.WORD $610A-1	; Perform [key]
478C: FF AF	.WORD $B000-1	; Perform [monitor]
478E: C8 6B	.WORD $6BC9-1	; Perform [bank]
4790: 45 70	.WORD $7046-1	; Perform [filter]
4792: E0 6D	.WORD $6DE1-1	; Perform [play]
4794: D6 6F	.WORD $6FD7-1	; Perform [tempo]
4796: C5 6C	.WORD $6CC6-1	; Perform [movspr]
4798: 4E 6C	.WORD $6C4F-1	; Perform [sprite]
479A: 8F 71	.WORD $7190-1	; Perform [sprcolor]
479C: BC 58	.WORD $58BD-1	; Perform [rreg]
479E: C0 70	.WORD $70C1-1	; Perform [envelope]
47A0: D6 6B	.WORD $6BD7-1	; Perform [sleep]
47A2: 7D A0	.WORD $A07E-1	; Perform [catalog/directory]
47A4: 1C A1	.WORD $A11D-1	; Perform [dopen]
47A6: 33 A1	.WORD $A134-1	; Perform [append]
47A8: 6E A1	.WORD $A16F-1	; Perform [dclose]
47AA: C7 A1	.WORD $A1C8-1	; Perform [bsave]
47AC: 17 A2	.WORD $A218-1	; Perform [bload]
47AE: D6 A2	.WORD $A2D7-1	; Perform [record]
47B0: 61 A3	.WORD $A362-1	; Perform [concat]
47B2: A3 A1	.WORD $A1A4-1	; Perform [dverify]
47B4: 21 A3	.WORD $A322-1	; Perform [dclear]
47B6: EB 76	.WORD $76EC-1	; Perform [sprsav]
47B8: 63 71	.WORD $7164-1	; Perform [collision]
47BA: 6B 79	.WORD $796C-1	; Syntax Error
47BC: 8E 52	.WORD $528F-1	; Perform [data/bend]
47BE: CB 72	.WORD $72CC-1	; Perform [window]
47C0: 34 73	.WORD $7335-1	; Perform [boot]
47C2: B5 71	.WORD $71B6-1	; Perform [width]
47C4: 71 73	.WORD $7372-1	; Perform [sprdef]
47C6: 45 48	.WORD $4846-1	; Unimplemented Commands
47C8: 1E AA	.WORD $AA1F-1	; Perform [stash]
47CA: 00 00	.WORD $0000	; Unused
47CC: 23 AA	.WORD $AA24-1	; Perform [fetch]
47CE: 00 00	.WORD $0000	; Unused
47D0: 28 AA	.WORD $AA29-1	; Perform [swap]
47D2: 45 48	.WORD $4846-1	; Unimplemented Commands
47D4: B2 77	.WORD $77B3-1	; Perform [fast]
47D6: C3 77	.WORD $77C4-1	; Perform [slow]

; Function Vectors

47D8: 65 8C	.WORD $8C65	; Evaluate <sgn>
47DA: FB 8C	.WORD $8CFB	; Evaluate <int>
47DC: 84 8C	.WORD $8C84	; Evaluate <abs>
47DE: 18 12	.WORD $1218	; USR Program Jump [7D28]
47E0: 00 80	.WORD $8000	; Evaluate <fre>
47E2: D0 84	.WORD $84D0	; Evaluate <pos>
47E4: B7 8F	.WORD $8FB7	; Evaluate <sqr>
47E6: 34 84	.WORD $8434	; Evaluate <rnd>
47E8: CA 89	.WORD $89CA	; Evaluate <log>
47EA: 33 90	.WORD $9033	; Evaluate <exp>
47EC: 09 94	.WORD $9409	; Evaluate <cos>
47EE: 10 94	.WORD $9410	; Evaluate <sin>
47F0: 59 94	.WORD $9459	; Evaluate <tan>
47F2: B3 94	.WORD $94B3	; Evaluate <atn>
47F4: C5 80	.WORD $80C5	; Evaluate <peek>
47F6: 68 86	.WORD $8668	; Evaluate <len>
47F8: AE 85	.WORD $85AE	; Evaluate <str$>
47FA: 4A 80	.WORD $804A	; Evaluate <val>
47FC: 77 86	.WORD $8677	; Evaluate <asc>
47FE: BF 85	.WORD $85BF	; Evaluate <chr$>
4800: D6 85	.WORD $85D6	; Evaluate <left$>
4802: 0A 86	.WORD $860A	; Evaluate <right$>
4804: 1C 86	.WORD $861C	; Evaluate <mid$>
4806: 82 81	.WORD $8182	; Evaluate <rgr>
4808: 9B 81	.WORD $819B	; Evaluate <rclr>
480A: 00 00	.WORD $0000	; $CE prefix
480C: 03 82	.WORD $8203	; Evaluate <joy>
480E: 0C 9B	.WORD $9B0C	; Evaluate <rdot>
4810: 76 80	.WORD $8076	; Evaluate <dec>
4812: 42 81	.WORD $8142	; Evaluate <hex$>
4814: F6 80	.WORD $80F6	; Evaluate <err$>
4816: 4D 82	.WORD $824D	; Evaluate <pot>
4818: 7C 83	.WORD $837C	; Evaluate <bump>
481A: AE 82	.WORD $82AE	; Evaluate <pen>
481C: 97 83	.WORD $8397	; Evaluate <rspos>
481E: 1E 83	.WORD $831E	; Evaluate <rsprite>
4820: 61 83	.WORD $8361	; Evaluate <rspcolor>
4822: E1 83	.WORD $83E1	; Evaluate <xor>
4824: 07 84	.WORD $8407	; Evaluate <rwindow>
4826: FA 82	.WORD $82FA	; Evaluate <pointer>

; Defunct Vectors

4828: 79 47 88	.BYTE $79,<($8848-1),>($8848-1)	; Evaluate <add>
482B: 79 30 88	.BYTE $79,<($8831-1),>($8831-1)	; Evaluate <subtract>
482E: 7B 26 8A	.BYTE $7B,<($8A27-1),>($8A27-1)	; Evaluate <multiply>
4831: 7B 4B 8B	.BYTE $7B,<($8B4C-1),>($8B4C-1)	; Evaluate <divide>
4834: 7F C0 8F	.BYTE $7F,<($8FC1-1),>($8FC1-1)	; Evaluate <power>
4837: 50 88 4C	.BYTE $50,<($4C89-1),>($4C89-1)	; Evaluate <and>
483A: 46 85 4C	.BYTE $46,<($4C86-1),>($4C86-1)	; Evaluate <or>
483D: 7D F9 8F	.BYTE $7D,<($8FFA-1),>($8FFA-1)	; Evaluate <negate>
4840: 5A 2F 79	.BYTE $5A,<($7930-1),>($7930-1)	; Evaluate <equal>
4843: 64 B5 4C	.BYTE $64,<($4CB6-1),>($4CB6-1)	; Evaluate <compare>

; Unimplemented Commands

4846: A2 28	LDX #$28
4848: 4C 3C 4D	JMP $4D3C	; Error

; Error Messages

484B: 54 4F 4F 20 4D 41 4E 59	; 'too many'	; 0: too many files
4853: 20 46 49 4C 45 D3 46 49	; ' fileSfi'	; 1: file open
485B: 4C 45 20 4F 50 45 CE 46	; 'le opeNf'	; 2: file not open
4863: 49 4C 45 20 4E 4F 54 20	; 'ile not '
486B: 4F 50 45 CE 46 49 4C 45	; 'opeNfile'	; 3: file not found
4873: 20 4E 4F 54 20 46 4F 55	; ' not fou'
487B: 4E C4 44 45 56 49 43 45	; 'nDdevice'	; 4: device not present
4883: 20 4E 4F 54 20 50 52 45	; ' not pre'
488B: 53 45 4E D4 4E 4F 54 20	; 'senTnot '	; 5: not input file
4893: 49 4E 50 55 54 20 46 49	; 'input fi'
489B: 4C C5 4E 4F 54 20 4F 55	; 'lEnot ou'	; 6: not output file
48A3: 54 50 55 54 20 46 49 4C	; 'tput fil'
48AB: C5 4D 49 53 53 49 4E 47	; 'Emissing'	; 7: missing filename
48B3: 20 46 49 4C 45 20 4E 41	; ' file na'
48BB: 4D C5 49 4C 4C 45 47 41	; 'mEillega'	; 8: illegal device
48C3: 4C 20 44 45 56 49 43 45	; 'l device'
48CB: 20 4E 55 4D 42 45 D2 4E	; ' numbeRn'	; 9: next without for
48D3: 45 58 54 20 57 49 54 48	; 'ext with'
48DB: 4F 55 54 20 46 4F D2 53	; 'out foRs'	; 0A: syntax
48E3: 59 4E 54 41 D8 52 45 54	; 'yntaXret'	; 0B: return without gosub
48EB: 55 52 4E 20 57 49 54 48	; 'urn with'
48F3: 4F 55 54 20 47 4F 53 55	; 'out gosu'
48FB: C2 4F 55 54 20 4F 46 20	; 'Bout of '	; 0C: out of data
4903: 44 41 54 C1 49 4C 4C 45	; 'datAille'	; 0D: illegal quantity
490B: 47 41 4C 20 51 55 41 4E	; 'gal quan'
4913: 54 49 54 D9 4F 56 45 52	; 'titYover'	; 0E overflow
491B: 46 4C 4F D7 4F 55 54 20	; 'floWout '	; 0F out of memory
4923: 4F 46 20 4D 45 4D 4F 52	; 'of memor'
492B: D9 55 4E 44 45 46 27 44	; 'Yundef'd'	; 10 undef'd statement
4933: 20 53 54 41 54 45 4D 45	; ' stateme'
493B: 4E D4 42 41 44 20 53 55	; 'nTbad su'	; 11 bad subscript
4943: 42 53 43 52 49 50 D4 52	; 'bscripTr'	; 12 redim'd array
494B: 45 44 49 4D 27 44 20 41	; 'edim'd a'
4953: 52 52 41 D9 44 49 56 49	; 'rraYdivi'	; 13 division by zero
495B: 53 49 4F 4E 20 42 59 20	; 'sion by '
4963: 5A 45 52 CF 49 4C 4C 45	; 'zerOille'	; 14 illegal direct
496B: 47 41 4C 20 44 49 52 45	; 'gal dire'
4973: 43 D4 54 59 50 45 20 4D	; 'cTtype m'	; 15 type mismatch
497B: 49 53 4D 41 54 43 C8 53	; 'ismatcHs'	; 16  string to long
4983: 54 52 49 4E 47 20 54 4F	; 'tring to'
498B: 4F 20 4C 4F 4E C7 46 49	; 'o lonGfi'	; 17 file data
4993: 4C 45 20 44 41 54 C1 46	; 'le datAf'	; 18 formula to complex
499B: 4F 52 4D 55 4C 41 20 54	; 'ormula t'
49A3: 4F 4F 20 43 4F 4D 50 4C	; 'oo compl'
49AB: 45 D8 43 41 4E 27 54 20	; 'eXcan't '	; 1A can't continue
49B3: 43 4F 4E 54 49 4E 55 C5	; 'continuE'
49BB: 55 4E 44 45 46 27 44 20	; 'undef'd '	; 1B undef'd function
49C3: 46 55 4E 43 54 49 4F CE	; 'functioN'
49CB: 56 45 52 49 46 D9 4C 4F	; 'verifYlo'	; 1C verify
49D3: 41 C4 42 52 45 41 4B 00	; 'aDbreak{0}'	; 1D load
49DB: A0 43 41 4E 27 54 20 52	; '.can't r'	; 1E break
49E3: 45 53 55 4D C5 4C 4F 4F	; 'esumEloo'	; 1F cant't resume
49EB: 50 20 4E 4F 54 20 46 4F	; 'p not fo'	; 20 loop not found
49F3: 55 4E C4 4C 4F 4F 50 20	; 'unDloop '	; 21 loop without do
49FB: 57 49 54 48 4F 55 54 20	; 'without '
4A03: 44 CF 44 49 52 45 43 54	; 'dOdirect'	; 22 direct mode only
4A0B: 20 4D 4F 44 45 20 4F 4E	; ' mode on'
4A13: 4C D9 4E 4F 20 47 52 41	; 'lYno gra'	; 23 no graphics area
4A1B: 50 48 49 43 53 20 41 52	; 'phics ar'
4A23: 45 C1 42 41 44 20 44 49	; 'eAbad di'	; 24 bad disk
4A2B: 53 CB 42 45 4E 44 20 4E	; 'sKbend n'	; 25 bend not found
4A33: 4F 54 20 46 4F 55 4E C4	; 'ot founD'
4A3B: 4C 49 4E 45 20 4E 55 4D	; 'line num'	; 26 line number too large
4A43: 42 45 52 20 54 4F 4F 20	; 'ber too '
4A4B: 4C 41 52 47 C5 55 4E 52	; 'largEunr'	; 27 unresolved reference
4A53: 45 53 4F 4C 56 45 44 20	; 'esolved '
4A5B: 52 45 46 45 52 45 4E 43	; 'referenc'
4A63: C5 55 4E 49 4D 50 4C 45	; 'Eunimple'	; 28 unimplemented command
4A6B: 4D 45 4E 54 45 44 20 43	; 'mented c'
4A73: 4F 4D 4D 41 4E C4 46 49	; 'ommanDfi'	; 29 file read
4A7B: 4C 45 20 52 45 41 C4   	; 'le reaD'

; Find Message

4A82: AA	TAX
4A83: A0 00	LDY #$00
4A85: A9 4B	LDA #$4B
4A87: 85 26	STA $26
4A89: A9 48	LDA #$48
4A8B: 85 27	STA $27

4A8D: CA	DEX
4A8E: 30 0E	BMI $4A9E

4A90: B1 26	LDA ($26),Y
4A92: 48	PHA
4A93: E6 26	INC $26
4A95: D0 02	BNE $4A99
4A97: E6 27	INC $27

4A99: 68	PLA
4A9A: 10 F4	BPL $4A90
4A9C: 30 EF	BMI $4A8D

4A9E: 60	RTS

; Start New Basic Code

4A9F: 6C 08 03	JMP ($0308)	; Start New BASIC Code Link [4AA2]

; Start New BASIC Code

4AA2: 24 7F	BIT $7F
4AA4: 10 4A	BPL $4AF0
4AA6: AD 7F 12	LDA $127F	; Collision Mask
4AA9: 30 45	BMI $4AF0
4AAB: A2 02	LDX #$02

4AAD: BD 76 12	LDA $1276,X	; Collision IRQ Task Table
4AB0: F0 3B	BEQ $4AED
4AB2: A9 00	LDA #$00
4AB4: 9D 76 12	STA $1276,X	; Collision IRQ Task Table
4AB7: BD 79 12	LDA $1279,X	; Collision IRQ Address Tables
4ABA: 85 16	STA $16
4ABC: BD 7C 12	LDA $127C,X
4ABF: 85 17	STA $17
4AC1: 8A	TXA
4AC2: 48	PHA
4AC3: A5 3D	LDA $3D 	; Textpointer: BASIC work point (chrget)
4AC5: 48	PHA
4AC6: A5 3E	LDA $3E
4AC8: 48	PHA
4AC9: AD 7F 12	LDA $127F	; Collision Mask
4ACC: 09 80	ORA #$80
4ACE: 8D 7F 12	STA $127F	; Collision Mask
4AD1: 20 80 03	JSR $0380	; CHRGET
4AD4: 20 1D 5A	JSR $5A1D	; Put Sub To B-Stack
4AD7: 20 E2 59	JSR $59E2
4ADA: 20 F6 4A	JSR $4AF6
4ADD: AD 7F 12	LDA $127F	; Collision Mask
4AE0: 29 7F	AND #$7F
4AE2: 8D 7F 12	STA $127F	; Collision Mask
4AE5: 68	PLA
4AE6: 85 3E	STA $3E
4AE8: 68	PLA
4AE9: 85 3D	STA $3D 	; Textpointer: BASIC work point (chrget)
4AEB: 68	PLA
4AEC: AA	TAX

4AED: CA	DEX
4AEE: 10 BD	BPL $4AAD

4AF0: 20 80 03	JSR $0380	; CHRGET

4AF3: 20 3F 4B	JSR $4B3F	; Execute/Trace Statement

4AF6: 20 B5 4B	JSR $4BB5	; ?
4AF9: 24 7F	BIT $7F
4AFB: 10 06	BPL $4B03
4AFD: 20 34 4B	JSR $4B34	; Update Continue Pointer
4B00: BA	TSX
4B01: 86 82	STX $82

4B03: A0 00	LDY #$00
4B05: 20 C9 03	JSR $03C9	; Txtptr Fetch From RAM Bank 0
4B08: F0 03	BEQ $4B0D
4B0A: 4C AE 4B	JMP $4BAE

4B0D: 24 7F	BIT $7F
4B0F: 10 20	BPL $4B31
4B11: A0 02	LDY #$02
4B13: 20 C9 03	JSR $03C9	; Txtptr Fetch From RAM Bank 0
4B16: F0 19	BEQ $4B31
4B18: C8	INY
4B19: 20 C9 03	JSR $03C9	; Txtptr Fetch From RAM Bank 0
4B1C: 85 3B	STA $3B
4B1E: C8	INY
4B1F: 20 C9 03	JSR $03C9	; Txtptr Fetch From RAM Bank 0
4B22: 85 3C	STA $3C
4B24: 98	TYA
4B25: 18	CLC
4B26: 65 3D	ADC $3D 	; Textpointer: BASIC work point (chrget)
4B28: 85 3D	STA $3D 	; Textpointer: BASIC work point (chrget)
4B2A: 90 02	BCC $4B2E
4B2C: E6 3E	INC $3E

4B2E: 4C 9F 4A	JMP $4A9F	; Start New Basic Code

4B31: 4C 37 4D	JMP $4D37	; Error or Ready

; Update Continue Pointer

4B34: A5 3D	LDA $3D 	; Textpointer: BASIC work point (chrget)
4B36: A4 3E	LDY $3E
4B38: 8D 02 12	STA $1202
4B3B: 8C 03 12	STY $1203

4B3E: 60	RTS

; Execute/Trace Statement

4B3F: F0 FD	BEQ $4B3E
4B41: 2C 6F 11	BIT $116F	; Trace Mode: FF = on
4B44: 10 13	BPL $4B59
4B46: 24 7F	BIT $7F
4B48: 10 0F	BPL $4B59
4B4A: 48	PHA
4B4B: A9 5B	LDA #$5B
4B4D: 20 0C 56	JSR $560C
4B50: 20 2E 8E	JSR $8E2E
4B53: A9 5D	LDA #$5D
4B55: 20 0C 56	JSR $560C
4B58: 68	PLA

4B59: C9 FE	CMP #$FE
4B5B: F0 37	BEQ $4B94
4B5D: C9 CB	CMP #$CB
4B5F: D0 03	BNE $4B64
4B61: 4C 3D 5A	JMP $5A3D	; Perform [go]

4B64: C9 CA	CMP #$CA
4B66: F0 23	BEQ $4B8B
4B68: C9 FB	CMP #$FB
4B6A: B0 3F	BCS $4BAB
4B6C: C9 A3	CMP #$A3
4B6E: 90 06	BCC $4B76
4B70: C9 D5	CMP #$D5
4B72: 90 37	BCC $4BAB
4B74: E9 32	SBC #$32

4B76: 38	SEC
4B77: E9 80	SBC #$80
4B79: B0 03	BCS $4B7E
4B7B: 4C C6 53	JMP $53C6	; Perform [let]

4B7E: 0A	ASL A
4B7F: A8	TAY
4B80: B9 FD 46	LDA $46FD,Y
4B83: 48	PHA
4B84: B9 FC 46	LDA $46FC,Y	; Action Vectors
4B87: 48	PHA
4B88: 4C 80 03	JMP $0380	; CHRGET

4B8B: A9 59	LDA #$59
4B8D: 48	PHA
4B8E: A9 00	LDA #$00
4B90: 48	PHA

4B91: 4C 80 03	JMP $0380	; CHRGET

4B94: 20 80 03	JSR $0380	; CHRGET
4B97: F0 12	BEQ $4BAB
4B99: C9 02	CMP #$02
4B9B: 90 08	BCC $4BA5
4B9D: C9 27	CMP #$27
4B9F: B0 04	BCS $4BA5
4BA1: 69 47	ADC #$47
4BA3: D0 D9	BNE $4B7E

4BA5: 38	SEC
4BA6: 6C 10 03	JMP ($0310)	; Execute FE Hook [4BA9]

; Execute FE

4BA9: 90 E6	BCC $4B91

4BAB: 4C 6C 79	JMP $796C	; Syntax Error

4BAE: C9 3A	CMP #$3A
4BB0: D0 F9	BNE $4BAB
4BB2: 4C 9F 4A	JMP $4A9F	; Start New Basic Code

; ?

4BB5: 20 93 92	JSR $9293	; Call 'test stop'
4BB8: F0 01	BEQ $4BBB
4BBA: 60	RTS

4BBB: AC 0C 12	LDY $120C
4BBE: C8	INY
4BBF: F0 0F	BEQ $4BD0

4BC1: 20 93 92	JSR $9293	; Call 'test stop'
4BC4: F0 FB	BEQ $4BC1
4BC6: A2 1E	LDX #$1E
4BC8: 4C 3C 4D	JMP $4D3C	; Error

; Perform [stop]

4BCB: B0 01	BCS $4BCE

; Perform [end]

4BCD: 18	CLC

4BCE: D0 26	BNE $4BF6

4BD0: 24 7F	BIT $7F
4BD2: 10 0D	BPL $4BE1
4BD4: 20 34 4B	JSR $4B34	; Update Continue Pointer
4BD7: A5 3B	LDA $3B
4BD9: A4 3C	LDY $3C
4BDB: 8D 00 12	STA $1200
4BDE: 8C 01 12	STY $1201

4BE1: 68	PLA
4BE2: 68	PLA
4BE3: 90 0E	BCC $4BF3
4BE5: 20 81 92	JSR $9281	; Print Following Text
4BE8: 0D 0A 42 52 45 41 4B 00	; '{CR}{LF}break{0}'
4BF0: 4C AF 4D	JMP $4DAF	; Break Entry

4BF3: 4C 37 4D	JMP $4D37	; Error or Ready

4BF6: 60	RTS

; Setup FN Reference

4BF7: C9 CE	CMP #$CE
4BF9: F0 59	BEQ $4C54
4BFB: C9 D5	CMP #$D5
4BFD: B0 AC	BCS $4BAB
4BFF: C9 CB	CMP #$CB
4C01: 90 02	BCC $4C05
4C03: E9 01	SBC #$01

4C05: 48	PHA
4C06: AA	TAX
4C07: 20 80 03	JSR $0380	; CHRGET
4C0A: E0 D3	CPX #$D3
4C0C: F0 08	BEQ $4C16
4C0E: E0 CB	CPX #$CB
4C10: B0 29	BCS $4C3B
4C12: E0 C8	CPX #$C8
4C14: 90 25	BCC $4C3B

4C16: 20 59 79	JSR $7959	; -Check Left Parenthesis
4C19: 20 EF 77	JSR $77EF	; Evaluate Expression
4C1C: 20 5C 79	JSR $795C	; -Check Comma
4C1F: 20 DD 77	JSR $77DD	; Confirm String
4C22: 68	PLA
4C23: C9 D3	CMP #$D3
4C25: F0 59	BEQ $4C80
4C27: AA	TAX
4C28: A5 67	LDA $67
4C2A: 48	PHA
4C2B: A5 66	LDA $66
4C2D: 48	PHA
4C2E: 8A	TXA
4C2F: 48	PHA
4C30: 20 F4 87	JSR $87F4	; -Eval Byte Parameter
4C33: 68	PLA
4C34: A8	TAY
4C35: 8A	TXA
4C36: 48	PHA
4C37: 98	TYA
4C38: 4C 3F 4C	JMP $4C3F

4C3B: 20 50 79	JSR $7950	; Eval Within Parens
4C3E: 68	PLA

4C3F: 38	SEC
4C40: E9 B4	SBC #$B4
4C42: 0A	ASL A
4C43: A8	TAY
4C44: B9 D9 47	LDA $47D9,Y
4C47: 85 58	STA $58
4C49: B9 D8 47	LDA $47D8,Y	; Function Vectors
4C4C: 85 57	STA $57
4C4E: 20 56 00	JSR $56
4C51: 4C DA 77	JMP $77DA	; Confirm Numeric

4C54: 20 80 03	JSR $0380	; CHRGET
4C57: F0 2A	BEQ $4C83
4C59: C9 0A	CMP #$0A
4C5B: F0 0B	BEQ $4C68
4C5D: 48	PHA
4C5E: 20 80 03	JSR $0380	; CHRGET
4C61: 20 59 79	JSR $7959	; -Check Left Parenthesis
4C64: 20 EF 77	JSR $77EF	; Evaluate Expression
4C67: 68	PLA

4C68: C9 02	CMP #$02
4C6A: 90 08	BCC $4C74
4C6C: C9 0B	CMP #$0B
4C6E: B0 04	BCS $4C74
4C70: 69 D1	ADC #$D1
4C72: D0 CB	BNE $4C3F

4C74: 38	SEC
4C75: 20 7D 4C	JSR $4C7D

4C78: B0 09	BCS $4C83
4C7A: 4C DA 77	JMP $77DA	; Confirm Numeric

4C7D: 6C FC 02	JMP ($02FC)	; Function Execute Hook [4C78]

4C80: 4C C1 99	JMP $99C1	; Evaluate <instr>

4C83: 4C 6C 79	JMP $796C	; Syntax Error

; Evaluate <or>

4C86: A0 FF	LDY #$FF
4C88: 2C	.BYTE $2C

; Evaluate <and>

4C89: A0 00	LDY #$00
4C8B: 84 0D	STY $0D
4C8D: 20 B4 84	JSR $84B4
4C90: A5 66	LDA $66
4C92: 45 0D	EOR $0D
4C94: 85 09	STA $09 	; SYS and MLM register save (SP)
4C96: A5 67	LDA $67
4C98: 45 0D	EOR $0D
4C9A: 85 0A	STA $0A
4C9C: 20 28 8C	JSR $8C28	; FAC#2 to FAC#1
4C9F: 20 B4 84	JSR $84B4
4CA2: A5 67	LDA $67
4CA4: 45 0D	EOR $0D
4CA6: 25 0A	AND $0A
4CA8: 45 0D	EOR $0D
4CAA: A8	TAY
4CAB: A5 66	LDA $66
4CAD: 45 0D	EOR $0D
4CAF: 25 09	AND $09 	; SYS and MLM register save (SP)
4CB1: 45 0D	EOR $0D
4CB3: 4C 3C 79	JMP $793C	; Fixed-Float

; Evaluate <compare>

4CB6: 20 DE 77	JSR $77DE
4CB9: B0 13	BCS $4CCE
4CBB: A5 6F	LDA $6F
4CBD: 09 7F	ORA #$7F
4CBF: 25 6B	AND $6B
4CC1: 85 6B	STA $6B
4CC3: A9 6A	LDA #$6A
4CC5: A0 00	LDY #$00
4CC7: 20 87 8C	JSR $8C87	; Compare FAC#1 to Memory
4CCA: AA	TAX
4CCB: 4C 01 4D	JMP $4D01

4CCE: A9 00	LDA #$00
4CD0: 85 0F	STA $0F
4CD2: C6 4F	DEC $4F
4CD4: 20 81 87	JSR $8781
4CD7: 85 63	STA $63
4CD9: 86 64	STX $64
4CDB: 84 65	STY $65
4CDD: A5 6D	LDA $6D
4CDF: A4 6E	LDY $6E
4CE1: 20 85 87	JSR $8785
4CE4: 86 6D	STX $6D
4CE6: 84 6E	STY $6E
4CE8: AA	TAX
4CE9: 38	SEC
4CEA: E5 63	SBC $63
4CEC: F0 08	BEQ $4CF6
4CEE: A9 01	LDA #$01
4CF0: 90 04	BCC $4CF6
4CF2: A6 63	LDX $63
4CF4: A9 FF	LDA #$FF

4CF6: 85 68	STA $68
4CF8: A0 FF	LDY #$FF
4CFA: E8	INX

4CFB: C8	INY
4CFC: CA	DEX
4CFD: D0 07	BNE $4D06
4CFF: A6 68	LDX $68

4D01: 30 1B	BMI $4D1E
4D03: 18	CLC
4D04: 90 18	BCC $4D1E

4D06: A9 6D	LDA #$6D
4D08: 20 AB 03	JSR $03AB	; Fetch From RAM Bank 1
4D0B: 48	PHA
4D0C: A9 64	LDA #$64
4D0E: 20 AB 03	JSR $03AB	; Fetch From RAM Bank 1
4D11: 85 79	STA $79
4D13: 68	PLA
4D14: C5 79	CMP $79
4D16: F0 E3	BEQ $4CFB
4D18: A2 FF	LDX #$FF
4D1A: B0 02	BCS $4D1E
4D1C: A2 01	LDX #$01

4D1E: E8	INX
4D1F: 8A	TXA
4D20: 2A	ROL A
4D21: 25 14	AND $14
4D23: F0 02	BEQ $4D27
4D25: A9 FF	LDA #$FF

4D27: 4C 68 8C	JMP $8C68	; Byte Fixed-Float

; Print 'ready'

4D2A: 20 81 92	JSR $9281	; Print Following Text
4D2D: 0D 52 45 41 44 59 2E 0D	; '{CR}ready.{CR}'
4D35: 00 60                  	; '{0}`'

; Error or Ready

4D37: A2 80	LDX #$80
4D39: 2C	.BYTE $2C

; Print 'out of memory'

4D3A: A2 10	LDX #$10

; Error

4D3C: 6C 00 03	JMP ($0300)	; Error Message Link [4D3F]

; Error Message

4D3F: 8D 03 FF	STA $FF03
4D42: 8A	TXA
4D43: 30 72	BMI $4DB7
4D45: 8E 08 12	STX $1208
4D48: 24 7F	BIT $7F
4D4A: 10 30	BPL $4D7C
4D4C: A0 01	LDY #$01

4D4E: B9 3B 00	LDA $3B,Y
4D51: 99 09 12	STA $1209,Y
4D54: B9 02 12	LDA $1202,Y
4D57: 99 0E 12	STA $120E,Y
4D5A: 88	DEY
4D5B: 10 F1	BPL $4D4E
4D5D: AC 0C 12	LDY $120C
4D60: C8	INY
4D61: F0 19	BEQ $4D7C
4D63: 88	DEY
4D64: 84 17	STY $17
4D66: 8C 0D 12	STY $120D
4D69: AC 0B 12	LDY $120B
4D6C: 84 16	STY $16
4D6E: A2 FF	LDX #$FF
4D70: 20 D1 7E	JSR $7ED1	; String Stack patch for Error
4D73: A6 82	LDX $82
4D75: 9A	TXS
4D76: 20 FB 59	JSR $59FB
4D79: 4C F6 4A	JMP $4AF6

4D7C: CA	DEX
4D7D: 8A	TXA
4D7E: 20 82 4A	JSR $4A82	; Find Message
4D81: 20 6F 92	JSR $926F	; Call 'clrchn'
4D84: A9 00	LDA #$00
4D86: 85 15	STA $15 	; Current I/O prompt flag
4D88: 24 D7	BIT $D7 	; 40 / 80 columns:  0 = 40, 128 = 80
4D8A: 30 02	BMI $4D8E
4D8C: 85 D8	STA $D8 	; Graphics mode code (BIT765: 000=0, 001=1, 011=2, 101=3, 111=4)

4D8E: 20 98 55	JSR $5598
4D91: 20 0A 56	JSR $560A	; -print '?'-
4D94: A0 00	LDY #$00

4D96: B1 26	LDA ($26),Y
4D98: 48	PHA
4D99: 29 7F	AND #$7F
4D9B: 20 0C 56	JSR $560C
4D9E: C8	INY
4D9F: 68	PLA
4DA0: 10 F4	BPL $4D96
4DA2: 20 38 52	JSR $5238	; Clear Stack & Work Area
4DA5: 20 81 92	JSR $9281	; Print Following Text
4DA8: 20 45 52 52 4F 52 00   	; ' error{0}'

; Break Entry

4DAF: A4 3C	LDY $3C
4DB1: C8	INY
4DB2: F0 03	BEQ $4DB7
4DB4: 20 26 8E	JSR $8E26	; Print 'in...'

4DB7: 20 2A 4D	JSR $4D2A	; Print 'ready'
4DBA: A9 80	LDA #$80
4DBC: 20 90 FF	JSR $FF90	; setmsg        Control OS Messages
4DBF: A9 00	LDA #$00
4DC1: 85 7F	STA $7F

; Ready For Basic

4DC3: 6C 02 03	JMP ($0302)	; BASIC Warm Start Link [4DC6]

; BASIC Warm Start

4DC6: A2 FF	LDX #$FF
4DC8: 86 3C	STX $3C
4DCA: 20 93 4F	JSR $4F93	; Receive Input Line

4DCD: 86 3D	STX $3D 	; Textpointer: BASIC work point (chrget)
4DCF: 84 3E	STY $3E
4DD1: 20 80 03	JSR $0380	; CHRGET
4DD4: AA	TAX

4DD5: F0 EC	BEQ $4DC3	; Ready For Basic
4DD7: 90 09	BCC $4DE2	; Handle New Line
4DD9: 20 0A 43	JSR $430A	; Crunch Tokens
4DDC: 20 86 03	JSR $0386	; CHRGOT entry
4DDF: 4C F3 4A	JMP $4AF3

; Handle New Line

4DE2: 20 A0 50	JSR $50A0	; Get Fixed Pt Number
4DE5: 20 0A 43	JSR $430A	; Crunch Tokens
4DE8: 84 0D	STY $0D
4DEA: 20 64 50	JSR $5064	; Find Basic Line
4DED: 90 7B	BCC $4E6A
4DEF: A0 00	LDY #$00
4DF1: 20 EC 42	JSR $42EC	; Get From ($61) Bank0
4DF4: 38	SEC
4DF5: E5 61	SBC $61
4DF7: 38	SEC
4DF8: E9 04	SBC #$04
4DFA: E5 0D	SBC $0D
4DFC: B0 1C	BCS $4E1A
4DFE: 49 FF	EOR #$FF
4E00: 69 01	ADC #$01
4E02: AC 11 12	LDY $1211
4E05: 6D 10 12	ADC $1210	; End of Basic, Bank 0
4E08: 90 01	BCC $4E0B
4E0A: C8	INY

4E0B: CC 13 12	CPY $1213
4E0E: 90 0A	BCC $4E1A
4E10: D0 05	BNE $4E17
4E12: CD 12 12	CMP $1212	; Basic Program Limit [FF00]
4E15: 90 03	BCC $4E1A

4E17: 4C 3A 4D	JMP $4D3A	; Print 'out of memory'

4E1A: A0 01	LDY #$01
4E1C: 20 EC 42	JSR $42EC	; Get From ($61) Bank0
4E1F: 85 25	STA $25
4E21: AD 10 12	LDA $1210	; End of Basic, Bank 0
4E24: 85 24	STA $24
4E26: A5 62	LDA $62
4E28: 85 27	STA $27
4E2A: 88	DEY
4E2B: 20 EC 42	JSR $42EC	; Get From ($61) Bank0
4E2E: 18	CLC
4E2F: E5 61	SBC $61
4E31: 49 FF	EOR #$FF
4E33: 18	CLC
4E34: 6D 10 12	ADC $1210	; End of Basic, Bank 0
4E37: 8D 10 12	STA $1210	; End of Basic, Bank 0
4E3A: 85 26	STA $26
4E3C: AD 11 12	LDA $1211
4E3F: 69 FF	ADC #$FF
4E41: 8D 11 12	STA $1211
4E44: E5 62	SBC $62
4E46: AA	TAX
4E47: 38	SEC
4E48: A5 61	LDA $61
4E4A: ED 10 12	SBC $1210	; End of Basic, Bank 0
4E4D: A8	TAY
4E4E: B0 03	BCS $4E53
4E50: E8	INX
4E51: C6 27	DEC $27

4E53: 18	CLC
4E54: 65 24	ADC $24
4E56: 90 03	BCC $4E5B
4E58: C6 25	DEC $25
4E5A: 18	CLC

4E5B: 20 05 43	JSR $4305	; Get From ($24) Bank0
4E5E: 91 26	STA ($26),Y
4E60: C8	INY
4E61: D0 F8	BNE $4E5B
4E63: E6 25	INC $25
4E65: E6 27	INC $27
4E67: CA	DEX
4E68: D0 F1	BNE $4E5B

4E6A: 20 38 52	JSR $5238	; Clear Stack & Work Area
4E6D: 20 4F 4F	JSR $4F4F	; Rechain Lines
4E70: A0 00	LDY #$00
4E72: B1 3D	LDA ($3D),Y	; Textpointer: BASIC work point (chrget)
4E74: D0 03	BNE $4E79
4E76: 4C D5 4D	JMP $4DD5

4E79: 18	CLC
4E7A: AD 10 12	LDA $1210	; End of Basic, Bank 0
4E7D: AC 11 12	LDY $1211
4E80: 85 5C	STA $5C
4E82: 84 5D	STY $5D
4E84: 65 0D	ADC $0D
4E86: 90 01	BCC $4E89
4E88: C8	INY

4E89: 18	CLC
4E8A: 69 04	ADC #$04
4E8C: 90 01	BCC $4E8F
4E8E: C8	INY

4E8F: 85 5A	STA $5A
4E91: 84 5B	STY $5B
4E93: CC 13 12	CPY $1213
4E96: 90 0A	BCC $4EA2
4E98: D0 05	BNE $4E9F
4E9A: CD 12 12	CMP $1212	; Basic Program Limit [FF00]
4E9D: 90 03	BCC $4EA2

4E9F: 4C 3A 4D	JMP $4D3A	; Print 'out of memory'

4EA2: 8D 10 12	STA $1210	; End of Basic, Bank 0
4EA5: 8C 11 12	STY $1211
4EA8: 38	SEC
4EA9: A5 5C	LDA $5C
4EAB: E5 61	SBC $61
4EAD: 85 24	STA $24
4EAF: A8	TAY
4EB0: A5 5D	LDA $5D
4EB2: E5 62	SBC $62
4EB4: AA	TAX
4EB5: E8	INX
4EB6: 98	TYA
4EB7: F0 25	BEQ $4EDE
4EB9: A5 5C	LDA $5C
4EBB: 38	SEC
4EBC: E5 24	SBC $24
4EBE: 85 5C	STA $5C
4EC0: B0 03	BCS $4EC5
4EC2: C6 5D	DEC $5D
4EC4: 38	SEC

4EC5: A5 5A	LDA $5A
4EC7: E5 24	SBC $24
4EC9: 85 5A	STA $5A
4ECB: B0 09	BCS $4ED6
4ECD: C6 5B	DEC $5B
4ECF: 90 05	BCC $4ED6

4ED1: 20 DD 42	JSR $42DD	; Get From ($5c) Bank0
4ED4: 91 5A	STA ($5A),Y

4ED6: 88	DEY
4ED7: D0 F8	BNE $4ED1
4ED9: 20 DD 42	JSR $42DD	; Get From ($5c) Bank0
4EDC: 91 5A	STA ($5A),Y

4EDE: C6 5D	DEC $5D
4EE0: C6 5B	DEC $5B
4EE2: CA	DEX
4EE3: D0 F1	BNE $4ED6
4EE5: A0 00	LDY #$00
4EE7: A9 01	LDA #$01
4EE9: 91 61	STA ($61),Y
4EEB: C8	INY
4EEC: 91 61	STA ($61),Y
4EEE: C8	INY
4EEF: A5 16	LDA $16
4EF1: 91 61	STA ($61),Y
4EF3: A5 17	LDA $17
4EF5: C8	INY
4EF6: 91 61	STA ($61),Y
4EF8: 18	CLC
4EF9: A5 61	LDA $61
4EFB: 69 04	ADC #$04
4EFD: 85 61	STA $61
4EFF: 90 02	BCC $4F03
4F01: E6 62	INC $62

4F03: A4 0D	LDY $0D
4F05: 88	DEY

4F06: B1 3D	LDA ($3D),Y	; Textpointer: BASIC work point (chrget)
4F08: 91 61	STA ($61),Y
4F0A: 88	DEY
4F0B: C0 FF	CPY #$FF
4F0D: D0 F7	BNE $4F06
4F0F: 20 4F 4F	JSR $4F4F	; Rechain Lines
4F12: 20 54 52	JSR $5254	; Textptr to BASIC start minus 1
4F15: A5 74	LDA $74 	; Auto line number increment
4F17: 05 75	ORA $75
4F19: F0 31	BEQ $4F4C
4F1B: A5 16	LDA $16
4F1D: 18	CLC
4F1E: 65 74	ADC $74 	; Auto line number increment
4F20: 85 65	STA $65
4F22: A5 17	LDA $17
4F24: 65 75	ADC $75
4F26: B0 24	BCS $4F4C
4F28: C9 FA	CMP #$FA
4F2A: B0 20	BCS $4F4C
4F2C: 85 64	STA $64
4F2E: A2 90	LDX #$90
4F30: 38	SEC
4F31: 20 75 8C	JSR $8C75	; Fixed-Float
4F34: 20 42 8E	JSR $8E42	; Float to Ascii
4F37: A2 00	LDX #$00

4F39: BD 01 01	LDA $0101,X
4F3C: F0 06	BEQ $4F44
4F3E: 9D 4A 03	STA $034A,X	; IRQ Keyboard Buffer (10 Bytes)
4F41: E8	INX
4F42: D0 F5	BNE $4F39

4F44: A9 1D	LDA #$1D
4F46: 9D 4A 03	STA $034A,X	; IRQ Keyboard Buffer (10 Bytes)
4F49: E8	INX
4F4A: 86 D0	STX $D0 	; Number of characters in keyboard buffer

4F4C: 4C C3 4D	JMP $4DC3	; Ready For Basic

; Rechain Lines

4F4F: A5 2D	LDA $2D 	; Pointer: Start-of-BASIC (bank 0)
4F51: A4 2E	LDY $2E
4F53: 85 24	STA $24
4F55: 84 25	STY $25
4F57: 18	CLC

4F58: A0 00	LDY #$00
4F5A: 20 05 43	JSR $4305	; Get From ($24) Bank0
4F5D: D0 06	BNE $4F65
4F5F: C8	INY
4F60: 20 05 43	JSR $4305	; Get From ($24) Bank0
4F63: F0 2D	BEQ $4F92

4F65: A0 04	LDY #$04

4F67: C8	INY
4F68: 20 05 43	JSR $4305	; Get From ($24) Bank0
4F6B: D0 FA	BNE $4F67
4F6D: C8	INY
4F6E: 98	TYA
4F6F: 65 24	ADC $24
4F71: AA	TAX
4F72: A0 00	LDY #$00
4F74: 91 24	STA ($24),Y
4F76: 98	TYA
4F77: 65 25	ADC $25
4F79: C8	INY
4F7A: 91 24	STA ($24),Y
4F7C: 86 24	STX $24
4F7E: 85 25	STA $25
4F80: 90 D6	BCC $4F58

; Reset End-of-Basic

4F82: 18	CLC
4F83: A5 24	LDA $24
4F85: A4 25	LDY $25
4F87: 69 02	ADC #$02
4F89: 90 01	BCC $4F8C
4F8B: C8	INY

4F8C: 8D 10 12	STA $1210	; End of Basic, Bank 0
4F8F: 8C 11 12	STY $1211

4F92: 60	RTS

; Receive Input Line

4F93: A2 00	LDX #$00

4F95: 20 E5 90	JSR $90E5	; Basic 'input'
4F98: C9 0D	CMP #$0D
4F9A: D0 03	BNE $4F9F
4F9C: 4C 8B 55	JMP $558B

4F9F: 9D 00 02	STA $0200,X
4FA2: E8	INX
4FA3: E0 A1	CPX #$A1
4FA5: 90 EE	BCC $4F95
4FA7: 4C ED A5	JMP $A5ED	; Print 'string too long'

; Search B-Stack For Match

4FAA: 85 02	STA $02 	; Bank Number, Jump to SYS Address
4FAC: 20 47 50	JSR $5047	; Copy B-Stack Pointer

4FAF: A5 3F	LDA $3F
4FB1: C9 FF	CMP #$FF
4FB3: D0 06	BNE $4FBB
4FB5: A5 40	LDA $40
4FB7: C9 09	CMP #$09
4FB9: F0 40	BEQ $4FFB

4FBB: 8D 03 FF	STA $FF03
4FBE: A0 00	LDY #$00
4FC0: A5 02	LDA $02 	; Bank Number, Jump to SYS Address
4FC2: C9 81	CMP #$81
4FC4: D0 1B	BNE $4FE1
4FC6: D1 3F	CMP ($3F),Y
4FC8: D0 33	BNE $4FFD
4FCA: A0 02	LDY #$02
4FCC: A5 4C	LDA $4C
4FCE: C9 FF	CMP #$FF
4FD0: F0 2B	BEQ $4FFD
4FD2: D1 3F	CMP ($3F),Y
4FD4: D0 07	BNE $4FDD
4FD6: 88	DEY
4FD7: A5 4B	LDA $4B
4FD9: D1 3F	CMP ($3F),Y
4FDB: F0 20	BEQ $4FFD

4FDD: A2 12	LDX #$12
4FDF: D0 0E	BNE $4FEF

4FE1: B1 3F	LDA ($3F),Y
4FE3: C5 02	CMP $02 	; Bank Number, Jump to SYS Address
4FE5: F0 16	BEQ $4FFD
4FE7: A2 12	LDX #$12
4FE9: C9 81	CMP #$81
4FEB: F0 02	BEQ $4FEF
4FED: A2 05	LDX #$05

4FEF: 8A	TXA
4FF0: 18	CLC
4FF1: 65 3F	ADC $3F
4FF3: 85 3F	STA $3F
4FF5: 90 B8	BCC $4FAF
4FF7: E6 40	INC $40
4FF9: D0 B4	BNE $4FAF

4FFB: A0 01	LDY #$01

4FFD: 60	RTS

; Move B-Stack Down

4FFE: 49 FF	EOR #$FF
5000: 38	SEC
5001: 65 7D	ADC $7D
5003: 85 7D	STA $7D
5005: A4 7E	LDY $7E
5007: B0 01	BCS $500A
5009: 88	DEY

500A: 84 7E	STY $7E
500C: C0 08	CPY #$08
500E: 90 34	BCC $5044
5010: D0 04	BNE $5016
5012: C5 7D	CMP $7D
5014: 90 2E	BCC $5044

5016: 60	RTS

; Check Memory Space

5017: C4 36	CPY $36
5019: 90 28	BCC $5043
501B: D0 04	BNE $5021
501D: C5 35	CMP $35
501F: 90 22	BCC $5043

5021: 48	PHA
5022: A2 09	LDX #$09
5024: 98	TYA

5025: 48	PHA
5026: B5 59	LDA $59,X
5028: CA	DEX
5029: 10 FA	BPL $5025
502B: 20 EA 92	JSR $92EA	; Garbage Collection
502E: A2 F7	LDX #$F7

5030: 68	PLA
5031: 95 63	STA $63,X
5033: E8	INX
5034: 30 FA	BMI $5030
5036: 68	PLA
5037: A8	TAY
5038: 68	PLA
5039: C4 36	CPY $36
503B: 90 06	BCC $5043
503D: D0 05	BNE $5044
503F: C5 35	CMP $35
5041: B0 01	BCS $5044

5043: 60	RTS

5044: 4C 3A 4D	JMP $4D3A	; Print 'out of memory'

; Copy B-Stack Pointer

5047: A5 7D	LDA $7D
5049: 85 3F	STA $3F
504B: A5 7E	LDA $7E
504D: 85 40	STA $40
504F: 60	RTS

; Set B-Stack Pointer

5050: A5 3F	LDA $3F
5052: 85 7D	STA $7D
5054: A5 40	LDA $40
5056: 85 7E	STA $7E
5058: 60	RTS

; Move B-Stack Up

5059: 98	TYA
505A: 18	CLC
505B: 65 7D	ADC $7D
505D: 85 7D	STA $7D
505F: 90 02	BCC $5063
5061: E6 7E	INC $7E

5063: 60	RTS

; Find Basic Line

5064: A5 2D	LDA $2D 	; Pointer: Start-of-BASIC (bank 0)
5066: A6 2E	LDX $2E

5068: A0 01	LDY #$01
506A: 85 61	STA $61
506C: 86 62	STX $62
506E: 20 EC 42	JSR $42EC	; Get From ($61) Bank0
5071: F0 2B	BEQ $509E
5073: C8	INY
5074: C8	INY
5075: 20 EC 42	JSR $42EC	; Get From ($61) Bank0
5078: 85 79	STA $79
507A: A5 17	LDA $17
507C: C5 79	CMP $79
507E: 90 1F	BCC $509F
5080: F0 03	BEQ $5085
5082: 88	DEY
5083: D0 0E	BNE $5093

5085: 88	DEY
5086: 20 EC 42	JSR $42EC	; Get From ($61) Bank0
5089: 85 79	STA $79
508B: A5 16	LDA $16
508D: C5 79	CMP $79
508F: 90 0E	BCC $509F
5091: F0 0C	BEQ $509F

5093: 88	DEY
5094: 20 EC 42	JSR $42EC	; Get From ($61) Bank0
5097: AA	TAX
5098: 88	DEY
5099: 20 EC 42	JSR $42EC	; Get From ($61) Bank0
509C: B0 CA	BCS $5068

509E: 18	CLC

509F: 60	RTS

; Get Fixed Pt Number

50A0: A2 00	LDX #$00
50A2: 86 0A	STX $0A
50A4: 86 16	STX $16
50A6: 86 17	STX $17

50A8: B0 37	BCS $50E1
50AA: E6 0A	INC $0A
50AC: E9 2F	SBC #$2F
50AE: 85 09	STA $09 	; SYS and MLM register save (SP)
50B0: A5 17	LDA $17
50B2: 85 24	STA $24
50B4: C9 19	CMP #$19
50B6: 90 03	BCC $50BB
50B8: 4C 6C 79	JMP $796C	; Syntax Error

50BB: A5 16	LDA $16
50BD: 0A	ASL A
50BE: 26 24	ROL $24
50C0: 0A	ASL A
50C1: 26 24	ROL $24
50C3: 65 16	ADC $16
50C5: 85 16	STA $16
50C7: A5 24	LDA $24
50C9: 65 17	ADC $17
50CB: 85 17	STA $17
50CD: 06 16	ASL $16
50CF: 26 17	ROL $17
50D1: A5 16	LDA $16
50D3: 65 09	ADC $09 	; SYS and MLM register save (SP)
50D5: 85 16	STA $16
50D7: 90 02	BCC $50DB
50D9: E6 17	INC $17

50DB: 20 80 03	JSR $0380	; CHRGET
50DE: 4C A8 50	JMP $50A8

50E1: 60	RTS

; Perform [list]

50E2: 20 FB 5E	JSR $5EFB	; Get Line Number Range

50E5: A0 01	LDY #$01
50E7: 20 EC 42	JSR $42EC	; Get From ($61) Bank0
50EA: D0 06	BNE $50F2
50EC: 88	DEY
50ED: 20 EC 42	JSR $42EC	; Get From ($61) Bank0
50F0: F0 2E	BEQ $5120

50F2: 20 B5 4B	JSR $4BB5	; ?
50F5: 20 98 55	JSR $5598
50F8: A0 02	LDY #$02
50FA: 20 EC 42	JSR $42EC	; Get From ($61) Bank0
50FD: AA	TAX
50FE: C8	INY
50FF: 20 EC 42	JSR $42EC	; Get From ($61) Bank0
5102: C5 17	CMP $17
5104: D0 04	BNE $510A
5106: E4 16	CPX $16
5108: F0 02	BEQ $510C

510A: B0 14	BCS $5120

510C: 20 23 51	JSR $5123	; List Subroutine
510F: A0 00	LDY #$00
5111: 20 EC 42	JSR $42EC	; Get From ($61) Bank0
5114: AA	TAX
5115: C8	INY
5116: 20 EC 42	JSR $42EC	; Get From ($61) Bank0
5119: 86 61	STX $61
511B: 85 62	STA $62
511D: 4C E5 50	JMP $50E5

5120: 4C 98 55	JMP $5598

; List Subroutine

5123: A0 03	LDY #$03
5125: 84 4B	STY $4B
5127: 84 11	STY $11
5129: 20 32 8E	JSR $8E32	; Print Integer
512C: A9 20	LDA #$20

512E: A4 4B	LDY $4B
5130: 29 7F	AND #$7F

5132: 20 0C 56	JSR $560C
5135: C9 22	CMP #$22
5137: D0 06	BNE $513F
5139: A5 11	LDA $11
513B: 49 FF	EOR #$FF
513D: 85 11	STA $11

513F: C8	INY
5140: F0 DE	BEQ $5120
5142: 24 55	BIT $55
5144: 10 03	BPL $5149
5146: 20 AC 59	JSR $59AC	; Insert Help Marker

5149: 20 EC 42	JSR $42EC	; Get From ($61) Bank0
514C: F0 3D	BEQ $518B
514E: 6C 06 03	JMP ($0306)	; Print Tokens Link [5151]

; Print Tokens

5151: 10 DF	BPL $5132
5153: C9 FF	CMP #$FF
5155: F0 DB	BEQ $5132
5157: 24 11	BIT $11
5159: 30 D7	BMI $5132
515B: C9 FE	CMP #$FE
515D: F0 2D	BEQ $518C
515F: C9 CE	CMP #$CE
5161: F0 43	BEQ $51A6
5163: AA	TAX
5164: 84 4B	STY $4B
5166: A9 44	LDA #$44
5168: A0 17	LDY #$17

516A: 85 25	STA $25
516C: 84 24	STY $24
516E: A0 00	LDY #$00

5170: CA	DEX
5171: 10 0F	BPL $5182

5173: B1 24	LDA ($24),Y
5175: 48	PHA
5176: E6 24	INC $24
5178: D0 02	BNE $517C
517A: E6 25	INC $25

517C: 68	PLA
517D: 10 F4	BPL $5173
517F: 30 EF	BMI $5170

5181: C8	INY

5182: B1 24	LDA ($24),Y
5184: 30 A8	BMI $512E
5186: 20 0C 56	JSR $560C
5189: D0 F6	BNE $5181

518B: 60	RTS

518C: AA	TAX
518D: C8	INY
518E: 20 EC 42	JSR $42EC	; Get From ($61) Bank0
5191: F0 9F	BEQ $5132
5193: 84 4B	STY $4B
5195: C9 02	CMP #$02
5197: 90 27	BCC $51C0
5199: C9 27	CMP #$27
519B: B0 23	BCS $51C0
519D: 69 7E	ADC #$7E
519F: AA	TAX
51A0: A0 09	LDY #$09
51A2: A9 46	LDA #$46
51A4: D0 C4	BNE $516A

51A6: AA	TAX
51A7: C8	INY
51A8: 20 EC 42	JSR $42EC	; Get From ($61) Bank0
51AB: F0 85	BEQ $5132
51AD: 84 4B	STY $4B
51AF: C9 02	CMP #$02
51B1: 90 0D	BCC $51C0
51B3: C9 0B	CMP #$0B
51B5: B0 09	BCS $51C0
51B7: 69 7E	ADC #$7E
51B9: AA	TAX
51BA: A0 C9	LDY #$C9
51BC: A9 46	LDA #$46
51BE: D0 AA	BNE $516A

51C0: E0 FE	CPX #$FE
51C2: D0 03	BNE $51C7
51C4: A2 00	LDX #$00
51C6: 2C	.BYTE $2C

51C7: A2 FF	LDX #$FF
51C9: 38	SEC
51CA: 6C 0E 03	JMP ($030E)	; List FE Hook [51CD]

; List FE

51CD: B0 04	BCS $51D3
51CF: A0 00	LDY #$00
51D1: F0 AF	BEQ $5182

51D3: 4C 32 51	JMP $5132

; Perform [new]

51D6: F0 01	BEQ $51D9
51D8: 60	RTS

51D9: A9 00	LDA #$00
51DB: A8	TAY
51DC: 91 2D	STA ($2D),Y	; Pointer: Start-of-BASIC (bank 0)
51DE: C8	INY
51DF: 91 2D	STA ($2D),Y	; Pointer: Start-of-BASIC (bank 0)
51E1: 8D 6F 11	STA $116F	; Trace Mode: FF = on
51E4: A5 2D	LDA $2D 	; Pointer: Start-of-BASIC (bank 0)
51E6: 18	CLC
51E7: 69 02	ADC #$02
51E9: 8D 10 12	STA $1210	; End of Basic, Bank 0
51EC: A5 2E	LDA $2E
51EE: 69 00	ADC #$00
51F0: 8D 11 12	STA $1211

; Set Up Run

51F3: 20 54 52	JSR $5254	; Textptr to BASIC start minus 1
51F6: A9 00	LDA #$00

; Perform [clr]

51F8: D0 55	BNE $524F

51FA: 20 7B 92	JSR $927B	; Call 'clall'
51FD: A0 00	LDY #$00
51FF: 84 7A	STY $7A
5201: 88	DEY
5202: 8C 0C 12	STY $120C
5205: 8C 09 12	STY $1209
5208: 8C 0A 12	STY $120A
520B: 8C 08 12	STY $1208
520E: A5 39	LDA $39 	; Pointer: Limit-of-memory (bank 1)
5210: A4 3A	LDY $3A
5212: 85 35	STA $35
5214: 84 36	STY $36
5216: A9 FF	LDA #$FF
5218: A0 09	LDY #$09
521A: 85 7D	STA $7D
521C: 84 7E	STY $7E
521E: A5 2F	LDA $2F 	; Pointer: Start-of-variables (bank 1)
5220: A4 30	LDY $30
5222: 85 31	STA $31
5224: 84 32	STY $32
5226: 85 33	STA $33
5228: 84 34	STY $34
522A: A2 03	LDX #$03

522C: BD 50 52	LDA $5250,X	; Pudef Characters
522F: 9D 04 12	STA $1204,X
5232: CA	DEX
5233: 10 F7	BPL $522C

5235: 20 E1 5A	JSR $5AE1

; Clear Stack & Work Area

5238: A2 1B	LDX #$1B
523A: 86 18	STX $18
523C: 68	PLA
523D: A8	TAY
523E: 68	PLA
523F: A2 FA	LDX #$FA
5241: 9A	TXS
5242: 48	PHA
5243: 98	TYA
5244: 48	PHA
5245: A9 00	LDA #$00
5247: 8D 03 12	STA $1203
524A: 85 12	STA $12
524C: 8D DF 03	STA $03DF	; FAC#1 Overflow

524F: 60	RTS

; Pudef Characters

5250: 20 2C 2E 24            	; ' ,.$'

; Textptr to BASIC start minus 1

5254: 18	CLC
5255: A5 2D	LDA $2D 	; Pointer: Start-of-BASIC (bank 0)
5257: 69 FF	ADC #$FF
5259: 85 3D	STA $3D 	; Textpointer: BASIC work point (chrget)
525B: A5 2E	LDA $2E
525D: 69 FF	ADC #$FF
525F: 85 3E	STA $3E
5261: 60	RTS

; Perform [return]

5262: 68	PLA
5263: 68	PLA
5264: A9 8D	LDA #$8D
5266: 20 AA 4F	JSR $4FAA	; Search B-Stack For Match
5269: F0 05	BEQ $5270
526B: A2 0C	LDX #$0C
526D: 4C 3C 4D	JMP $4D3C	; Error

5270: 20 50 50	JSR $5050	; Set B-Stack Pointer
5273: A0 05	LDY #$05
5275: 20 59 50	JSR $5059	; Move B-Stack Up
5278: 88	DEY
5279: B1 3F	LDA ($3F),Y
527B: 85 3E	STA $3E
527D: 88	DEY
527E: B1 3F	LDA ($3F),Y
5280: 85 3D	STA $3D 	; Textpointer: BASIC work point (chrget)
5282: 88	DEY
5283: B1 3F	LDA ($3F),Y
5285: 20 3B A8	JSR $A83B	; ?
5288: B1 3F	LDA ($3F),Y
528A: 85 3B	STA $3B
528C: 4C 8F 52	JMP $528F	; Perform [data/bend]

; Perform [data/bend]

528F: 20 A2 52	JSR $52A2	; Scan To Next Statement

5292: 98	TYA
5293: 18	CLC
5294: 65 3D	ADC $3D 	; Textpointer: BASIC work point (chrget)
5296: 85 3D	STA $3D 	; Textpointer: BASIC work point (chrget)
5298: 90 02	BCC $529C
529A: E6 3E	INC $3E

529C: 60	RTS

; Perform [rem]

529D: 20 A5 52	JSR $52A5	; Scan To Next Line
52A0: F0 F0	BEQ $5292

; Scan To Next Statement

52A2: A2 3A	LDX #$3A
52A4: 2C	.BYTE $2C

; Scan To Next Line

52A5: A2 00	LDX #$00
52A7: 86 09	STX $09 	; SYS and MLM register save (SP)
52A9: A0 00	LDY #$00
52AB: 84 0A	STY $0A

52AD: A5 0A	LDA $0A
52AF: A6 09	LDX $09 	; SYS and MLM register save (SP)
52B1: 85 09	STA $09 	; SYS and MLM register save (SP)
52B3: 86 0A	STX $0A

52B5: 20 C9 03	JSR $03C9	; Txtptr Fetch From RAM Bank 0
52B8: F0 E2	BEQ $529C
52BA: C5 0A	CMP $0A
52BC: F0 DE	BEQ $529C
52BE: C8	INY
52BF: C9 22	CMP #$22
52C1: D0 F2	BNE $52B5
52C3: F0 E8	BEQ $52AD

; Perform [if]

52C5: 20 EF 77	JSR $77EF	; Evaluate Expression
52C8: 20 86 03	JSR $0386	; CHRGOT entry
52CB: C9 89	CMP #$89
52CD: F0 05	BEQ $52D4
52CF: A9 A7	LDA #$A7
52D1: 20 5E 79	JSR $795E

52D4: A5 63	LDA $63
52D6: D0 26	BNE $52FE
52D8: 20 86 03	JSR $0386	; CHRGOT entry
52DB: C9 FE	CMP #$FE
52DD: D0 0B	BNE $52EA
52DF: C8	INY
52E0: 20 C9 03	JSR $03C9	; Txtptr Fetch From RAM Bank 0
52E3: C9 18	CMP #$18
52E5: D0 03	BNE $52EA
52E7: 20 20 53	JSR $5320	; Search/Skip Begin/Bend

52EA: 20 8F 52	JSR $528F	; Perform [data/bend]
52ED: A0 00	LDY #$00
52EF: 20 C9 03	JSR $03C9	; Txtptr Fetch From RAM Bank 0
52F2: F0 A9	BEQ $529D	; Perform [rem]
52F4: 20 80 03	JSR $0380	; CHRGET
52F7: C9 D5	CMP #$D5
52F9: D0 EF	BNE $52EA
52FB: 20 80 03	JSR $0380	; CHRGET

52FE: 20 86 03	JSR $0386	; CHRGOT entry
5301: F0 17	BEQ $531A
5303: B0 03	BCS $5308
5305: 4C DB 59	JMP $59DB	; Perform [goto]

5308: C9 FE	CMP #$FE
530A: D0 0E	BNE $531A
530C: C8	INY
530D: 20 C9 03	JSR $03C9	; Txtptr Fetch From RAM Bank 0
5310: C9 18	CMP #$18
5312: D0 06	BNE $531A
5314: 20 80 03	JSR $0380	; CHRGET
5317: 20 80 03	JSR $0380	; CHRGET

531A: 20 86 03	JSR $0386	; CHRGOT entry
531D: 4C 3F 4B	JMP $4B3F	; Execute/Trace Statement

; Search/Skip Begin/Bend

5320: 20 80 03	JSR $0380	; CHRGET
5323: D0 27	BNE $534C

5325: C9 3A	CMP #$3A
5327: F0 F7	BEQ $5320	; Search/Skip Begin/Bend

5329: 24 7F	BIT $7F
532B: 10 4A	BPL $5377
532D: A0 02	LDY #$02
532F: 20 C9 03	JSR $03C9	; Txtptr Fetch From RAM Bank 0
5332: F0 43	BEQ $5377
5334: C8	INY
5335: 20 C9 03	JSR $03C9	; Txtptr Fetch From RAM Bank 0
5338: 85 3B	STA $3B
533A: C8	INY
533B: 20 C9 03	JSR $03C9	; Txtptr Fetch From RAM Bank 0
533E: 85 3C	STA $3C
5340: 98	TYA
5341: 18	CLC
5342: 65 3D	ADC $3D 	; Textpointer: BASIC work point (chrget)
5344: 85 3D	STA $3D 	; Textpointer: BASIC work point (chrget)
5346: 90 D8	BCC $5320	; Search/Skip Begin/Bend
5348: E6 3E	INC $3E
534A: D0 D4	BNE $5320	; Search/Skip Begin/Bend

534C: C9 22	CMP #$22
534E: D0 07	BNE $5357
5350: 20 7C 53	JSR $537C	; Skip String Constant
5353: F0 D0	BEQ $5325
5355: D0 C9	BNE $5320	; Search/Skip Begin/Bend

5357: C9 8F	CMP #$8F
5359: D0 06	BNE $5361
535B: 20 9D 52	JSR $529D	; Perform [rem]
535E: 4C 29 53	JMP $5329

5361: C9 FE	CMP #$FE
5363: D0 BB	BNE $5320	; Search/Skip Begin/Bend
5365: 20 80 03	JSR $0380	; CHRGET
5368: C9 19	CMP #$19
536A: F0 0A	BEQ $5376
536C: C9 18	CMP #$18
536E: D0 B0	BNE $5320	; Search/Skip Begin/Bend
5370: 20 20 53	JSR $5320	; Search/Skip Begin/Bend
5373: 4C 20 53	JMP $5320	; Search/Skip Begin/Bend

5376: 60	RTS

5377: A2 25	LDX #$25
5379: 4C 3C 4D	JMP $4D3C	; Error

; Skip String Constant

537C: A0 00	LDY #$00

537E: E6 3D	INC $3D 	; Textpointer: BASIC work point (chrget)
5380: D0 02	BNE $5384
5382: E6 3E	INC $3E

5384: 20 C9 03	JSR $03C9	; Txtptr Fetch From RAM Bank 0
5387: F0 07	BEQ $5390
5389: C9 22	CMP #$22
538B: D0 F1	BNE $537E
538D: 4C 80 03	JMP $0380	; CHRGET

5390: 60	RTS

; Perform [else]

5391: C9 FE	CMP #$FE
5393: D0 0B	BNE $53A0
5395: C8	INY
5396: 20 C9 03	JSR $03C9	; Txtptr Fetch From RAM Bank 0
5399: C9 18	CMP #$18
539B: D0 03	BNE $53A0
539D: 20 20 53	JSR $5320	; Search/Skip Begin/Bend

53A0: 4C 9D 52	JMP $529D	; Perform [rem]

; Perform [on]

53A3: 20 F4 87	JSR $87F4	; -Eval Byte Parameter
53A6: 48	PHA
53A7: C9 8D	CMP #$8D
53A9: F0 07	BEQ $53B2
53AB: C9 89	CMP #$89
53AD: F0 03	BEQ $53B2
53AF: 4C 6C 79	JMP $796C	; Syntax Error

53B2: C6 67	DEC $67
53B4: D0 04	BNE $53BA
53B6: 68	PLA
53B7: 4C 59 4B	JMP $4B59

53BA: 20 80 03	JSR $0380	; CHRGET
53BD: 20 A0 50	JSR $50A0	; Get Fixed Pt Number
53C0: C9 2C	CMP #$2C
53C2: F0 EE	BEQ $53B2
53C4: 68	PLA
53C5: 60	RTS

; Perform [let]

53C6: 20 AF 7A	JSR $7AAF	; Locate Variable
53C9: 85 4B	STA $4B
53CB: 84 4C	STY $4C
53CD: A9 B2	LDA #$B2
53CF: 20 5E 79	JSR $795E
53D2: A5 10	LDA $10
53D4: 48	PHA
53D5: A5 0F	LDA $0F
53D7: 48	PHA
53D8: 20 EF 77	JSR $77EF	; Evaluate Expression
53DB: 68	PLA
53DC: 2A	ROL A
53DD: 20 DE 77	JSR $77DE
53E0: D0 22	BNE $5404
53E2: 68	PLA

53E3: 10 15	BPL $53FA
53E5: 20 47 8C	JSR $8C47	; Round FAC#1
53E8: 20 B4 84	JSR $84B4
53EB: A0 00	LDY #$00
53ED: A5 66	LDA $66
53EF: 8D 04 FF	STA $FF04
53F2: 91 4B	STA ($4B),Y
53F4: C8	INY
53F5: A5 67	LDA $67
53F7: 91 4B	STA ($4B),Y
53F9: 60	RTS

53FA: A6 4B	LDX $4B
53FC: A4 4C	LDY $4C
53FE: 8D 04 FF	STA $FF04
5401: 4C 00 8C	JMP $8C00	; Pack FAC#1 to RAM1

5404: 68	PLA

5405: A4 4C	LDY $4C		; variable string descriptor address high byte
5407: C0 03	CPY #$03	; system descriptor?
5409: D0 72	BNE $547D	; assign to variable
540B: 20 81 87	JSR $8781	; get string, remove it from heap
540E: C9 06	CMP #$06	; length not 6 (time string)
5410: D0 3E	BNE $5450	; error "?ILLEGAL QUANTITITY"
5412: A0 00	LDY #$00
5414: 84 63	STY $63
5416: 84 68	STY $68

5418: 84 72	STY $72
541A: 20 48 54	JSR $5448	; get digit
541D: 20 17 8B	JSR $8B17	; Multiply By 10
5420: E6 72	INC $72
5422: A4 72	LDY $72
5424: 20 48 54	JSR $5448	; get digit
5427: 20 38 8C	JSR $8C38	; FAC#1 to FAC#2
542A: AA	TAX
542B: F0 05	BEQ $5432
542D: E8	INX
542E: 8A	TXA
542F: 20 22 8B	JSR $8B22

5432: A4 72	LDY $72
5434: C8	INY
5435: C0 06	CPY #$06
5437: D0 DF	BNE $5418
5439: 20 17 8B	JSR $8B17	; Multiply By 10
543C: 20 C7 8C	JSR $8CC7	; Float-Fixed
543F: A6 66	LDX $66
5441: A4 65	LDY $65
5443: A5 67	LDA $67
5445: 4C DB FF	JMP $FFDB	; settim        Set Real-Time Clock

5448: 20 B7 03	JSR $03B7	; Index1 Indirect Fetch From RAM Bank 1 ($24),Y
544B: 20 90 03	JSR $0390
544E: 90 03	BCC $5453

5450: 4C 28 7D	JMP $7D28	; Print 'illegal quantity'

5453: E9 2F	SBC #$2F
5455: 4C B0 8D	JMP $8DB0	; Get Ascii Digit

5458: 68	PLA
5459: C8	INY

545A: C5 36	CMP $36
545C: 90 18	BCC $5476
545E: D0 08	BNE $5468
5460: 88	DEY
5461: 20 E7 42	JSR $42E7	; Get From ($66) Bank1
5464: C5 35	CMP $35
5466: 90 0E	BCC $5476

5468: A4 67	LDY $67
546A: C4 30	CPY $30
546C: 90 08	BCC $5476
546E: D0 24	BNE $5494
5470: A5 66	LDA $66
5472: C5 2F	CMP $2F 	; Pointer: Start-of-variables (bank 1)
5474: B0 1E	BCS $5494

5476: A5 66	LDA $66
5478: A4 67	LDY $67
547A: 4C B2 54	JMP $54B2

547D: A0 02	LDY #$02
547F: 20 E7 42	JSR $42E7	; Get From ($66) Bank1
5482: C5 7C	CMP $7C
5484: D0 D4	BNE $545A
5486: 48	PHA
5487: 88	DEY
5488: 20 E7 42	JSR $42E7	; Get From ($66) Bank1
548B: C5 7B	CMP $7B
548D: D0 C9	BNE $5458
548F: A5 7A	LDA $7A
5491: F0 C5	BEQ $5458
5493: 68	PLA

5494: A0 00	LDY #$00
5496: 20 E7 42	JSR $42E7	; Get From ($66) Bank1
5499: 20 88 86	JSR $8688	; Calc String Vector
549C: A5 52	LDA $52
549E: A4 53	LDY $53
54A0: 85 70	STA $70
54A2: 84 71	STY $71
54A4: 20 4E 87	JSR $874E	; Build String to Memory
54A7: A5 70	LDA $70
54A9: A4 71	LDY $71
54AB: 20 E0 87	JSR $87E0	; Clean Descriptor Stack
54AE: A9 63	LDA #$63
54B0: A0 00	LDY #$00

54B2: 85 52	STA $52
54B4: 84 53	STY $53
54B6: 85 24	STA $24
54B8: 84 25	STY $25
54BA: 20 E0 87	JSR $87E0	; Clean Descriptor Stack
54BD: 20 F6 54	JSR $54F6	; Check String Location
54C0: 90 0E	BCC $54D0
54C2: A0 00	LDY #$00
54C4: A5 4B	LDA $4B
54C6: 8D 04 FF	STA $FF04
54C9: 91 24	STA ($24),Y
54CB: C8	INY
54CC: A5 4C	LDA $4C
54CE: 91 24	STA ($24),Y

54D0: A5 4B	LDA $4B
54D2: 85 24	STA $24
54D4: A5 4C	LDA $4C
54D6: 85 25	STA $25
54D8: 20 F6 54	JSR $54F6	; Check String Location
54DB: 90 0C	BCC $54E9
54DD: 88	DEY
54DE: A9 FF	LDA #$FF
54E0: 8D 04 FF	STA $FF04
54E3: 91 24	STA ($24),Y
54E5: 88	DEY
54E6: 8A	TXA
54E7: 91 24	STA ($24),Y

54E9: A0 02	LDY #$02

54EB: A9 52	LDA #$52
54ED: 20 AB 03	JSR $03AB	; Fetch From RAM Bank 1
54F0: 91 4B	STA ($4B),Y
54F2: 88	DEY
54F3: 10 F6	BPL $54EB
54F5: 60	RTS

; Check String Location

54F6: A0 00	LDY #$00
54F8: 20 B7 03	JSR $03B7	; Index1 Indirect Fetch From RAM Bank 1 ($24),Y
54FB: 48	PHA
54FC: F0 39	BEQ $5537
54FE: C8	INY
54FF: 20 B7 03	JSR $03B7	; Index1 Indirect Fetch From RAM Bank 1 ($24),Y
5502: AA	TAX
5503: C8	INY
5504: 20 B7 03	JSR $03B7	; Index1 Indirect Fetch From RAM Bank 1 ($24),Y
5507: C5 3A	CMP $3A
5509: 90 06	BCC $5511
550B: D0 2A	BNE $5537
550D: E4 39	CPX $39 	; Pointer: Limit-of-memory (bank 1)
550F: B0 26	BCS $5537

5511: 20 B7 03	JSR $03B7	; Index1 Indirect Fetch From RAM Bank 1 ($24),Y
5514: C5 36	CMP $36
5516: 90 1F	BCC $5537
5518: D0 04	BNE $551E
551A: E4 35	CPX $35
551C: 90 19	BCC $5537

551E: C5 7C	CMP $7C
5520: D0 04	BNE $5526
5522: E4 7B	CPX $7B
5524: F0 11	BEQ $5537

5526: 86 24	STX $24
5528: 85 25	STA $25
552A: 68	PLA
552B: AA	TAX
552C: 18	CLC
552D: 65 24	ADC $24
552F: 85 24	STA $24
5531: 90 02	BCC $5535
5533: E6 25	INC $25

5535: 38	SEC
5536: 60	RTS

5537: 68	PLA
5538: 18	CLC
5539: 60	RTS

; Perform [print#]

553A: 20 40 55	JSR $5540	; Perform [cmd]
553D: 4C 58 56	JMP $5658

; Perform [cmd]

5540: 20 F4 87	JSR $87F4	; -Eval Byte Parameter
5543: F0 05	BEQ $554A
5545: A9 2C	LDA #$2C
5547: 20 5E 79	JSR $795E

554A: 08	PHP
554B: 86 15	STX $15 	; Current I/O prompt flag
554D: 20 EB 90	JSR $90EB	; Redirect Output
5550: 28	PLP
5551: 4C 5A 55	JMP $555A	; Perform [print]

5554: 20 E5 55	JSR $55E5

5557: 20 86 03	JSR $0386	; CHRGOT entry

; Perform [print]

555A: F0 3C	BEQ $5598
555C: C9 FB	CMP #$FB
555E: D0 03	BNE $5563
5560: 4C 20 95	JMP $9520	; Print Using

5563: F0 43	BEQ $55A8
5565: C9 A3	CMP #$A3
5567: F0 50	BEQ $55B9
5569: C9 A6	CMP #$A6
556B: 18	CLC
556C: F0 4B	BEQ $55B9
556E: C9 2C	CMP #$2C
5570: F0 37	BEQ $55A9
5572: C9 3B	CMP #$3B
5574: F0 5E	BEQ $55D4
5576: 20 EF 77	JSR $77EF	; Evaluate Expression
5579: 24 0F	BIT $0F
557B: 30 D7	BMI $5554
557D: 20 42 8E	JSR $8E42	; Float to Ascii
5580: 20 9A 86	JSR $869A	; Set Up String
5583: 20 E5 55	JSR $55E5
5586: 20 00 56	JSR $5600	; Print Format Char
5589: D0 CC	BNE $5557

558B: A9 00	LDA #$00
558D: 9D 00 02	STA $0200,X
5590: A2 FF	LDX #$FF
5592: A0 01	LDY #$01
5594: A5 15	LDA $15 	; Current I/O prompt flag
5596: D0 10	BNE $55A8

5598: A9 0D	LDA #$0D
559A: 20 0C 56	JSR $560C
559D: 24 15	BIT $15 	; Current I/O prompt flag
559F: 10 05	BPL $55A6
55A1: A9 0A	LDA #$0A
55A3: 20 0C 56	JSR $560C

55A6: 49 FF	EOR #$FF

55A8: 60	RTS

55A9: 38	SEC
55AA: 20 8D 92	JSR $928D	; Call 'plot'
55AD: 98	TYA
55AE: 38	SEC

55AF: E9 0A	SBC #$0A
55B1: B0 FC	BCS $55AF
55B3: 49 FF	EOR #$FF
55B5: 69 01	ADC #$01
55B7: D0 16	BNE $55CF

55B9: 08	PHP
55BA: 38	SEC
55BB: 20 8D 92	JSR $928D	; Call 'plot'
55BE: 84 0B	STY $0B
55C0: 20 F1 87	JSR $87F1	; Input Byte Parameter
55C3: C9 29	CMP #$29
55C5: D0 13	BNE $55DA
55C7: 28	PLP
55C8: 90 06	BCC $55D0
55CA: 8A	TXA
55CB: E5 0B	SBC $0B
55CD: 90 05	BCC $55D4

55CF: AA	TAX

55D0: E8	INX

55D1: CA	DEX
55D2: D0 09	BNE $55DD

55D4: 20 80 03	JSR $0380	; CHRGET
55D7: 4C 63 55	JMP $5563

55DA: 4C 6C 79	JMP $796C	; Syntax Error

55DD: 20 00 56	JSR $5600	; Print Format Char
55E0: D0 EF	BNE $55D1

55E2: 20 9A 86	JSR $869A	; Set Up String

55E5: 20 81 87	JSR $8781
55E8: AA	TAX
55E9: A0 00	LDY #$00
55EB: E8	INX

55EC: CA	DEX
55ED: F0 B9	BEQ $55A8
55EF: 20 B7 03	JSR $03B7	; Index1 Indirect Fetch From RAM Bank 1 ($24),Y
55F2: 20 0C 56	JSR $560C
55F5: C8	INY
55F6: C9 0D	CMP #$0D
55F8: D0 F2	BNE $55EC
55FA: 20 A6 55	JSR $55A6
55FD: 4C EC 55	JMP $55EC

; Print Format Char

5600: A5 15	LDA $15 	; Current I/O prompt flag
5602: F0 03	BEQ $5607	; -print '<cursor right>'-

; -print space-

5604: A9 20	LDA #$20
5606: 2C	.BYTE $2C

; -print '<cursor right>'-

5607: A9 1D	LDA #$1D
5609: 2C	.BYTE $2C

; -print '?'-

560A: A9 3F	LDA #$3F

560C: 20 DF 90	JSR $90DF	; Basic 'chrout'
560F: 29 FF	AND #$FF
5611: 60	RTS

; Perform [get]

5612: 20 D9 84	JSR $84D9	; Check Direct
5615: 85 77	STA $77
5617: C9 23	CMP #$23
5619: F0 0A	BEQ $5625
561B: C9 F9	CMP #$F9
561D: D0 16	BNE $5635	; Getkey
561F: 20 80 03	JSR $0380	; CHRGET
5622: 4C 35 56	JMP $5635	; Getkey

5625: 20 80 03	JSR $0380	; CHRGET
5628: 20 F4 87	JSR $87F4	; -Eval Byte Parameter
562B: A9 2C	LDA #$2C
562D: 20 5E 79	JSR $795E
5630: 86 15	STX $15 	; Current I/O prompt flag
5632: 20 FD 90	JSR $90FD	; Redirect Input

; Getkey

5635: A2 01	LDX #$01
5637: A0 02	LDY #$02
5639: A9 00	LDA #$00
563B: 8D 01 02	STA $0201
563E: A9 40	LDA #$40
5640: 20 B2 56	JSR $56B2
5643: A6 15	LDX $15 	; Current I/O prompt flag
5645: D0 13	BNE $565A
5647: 60	RTS

; Perform [input#]

5648: 20 F4 87	JSR $87F4	; -Eval Byte Parameter
564B: A9 2C	LDA #$2C
564D: 20 5E 79	JSR $795E
5650: 86 15	STX $15 	; Current I/O prompt flag
5652: 20 FD 90	JSR $90FD	; Redirect Input
5655: 20 71 56	JSR $5671

5658: A5 15	LDA $15 	; Current I/O prompt flag

565A: 20 6F 92	JSR $926F	; Call 'clrchn'
565D: A2 00	LDX #$00
565F: 86 15	STX $15 	; Current I/O prompt flag
5661: 60	RTS

; Perform [input]

5662: C9 22	CMP #$22
5664: D0 0B	BNE $5671
5666: 20 13 79	JSR $7913
5669: A9 3B	LDA #$3B
566B: 20 5E 79	JSR $795E
566E: 20 E5 55	JSR $55E5

5671: 20 D9 84	JSR $84D9	; Check Direct
5674: A9 2C	LDA #$2C
5676: 8D FF 01	STA $01FF

5679: 20 9C 56	JSR $569C	; Prompt & Input
567C: A5 15	LDA $15 	; Current I/O prompt flag
567E: F0 0D	BEQ $568D
5680: 20 51 92	JSR $9251	; Call 'status'
5683: 29 02	AND #$02
5685: F0 06	BEQ $568D
5687: 20 58 56	JSR $5658
568A: 4C 8F 52	JMP $528F	; Perform [data/bend]

568D: AD 00 02	LDA $0200
5690: D0 1E	BNE $56B0
5692: A5 15	LDA $15 	; Current I/O prompt flag
5694: D0 E3	BNE $5679
5696: 20 A2 52	JSR $52A2	; Scan To Next Statement
5699: 4C 92 52	JMP $5292

; Prompt & Input

569C: A5 15	LDA $15 	; Current I/O prompt flag
569E: D0 06	BNE $56A6
56A0: 20 0A 56	JSR $560A	; -print '?'-
56A3: 20 04 56	JSR $5604	; -print space-

56A6: 4C 93 4F	JMP $4F93	; Receive Input Line

; Perform [read]

56A9: A6 43	LDX $43
56AB: A4 44	LDY $44
56AD: A9 98	LDA #$98
56AF: 2C	.BYTE $2C

56B0: A9 00	LDA #$00

56B2: 85 13	STA $13
56B4: 86 45	STX $45
56B6: 84 46	STY $46

56B8: 20 AF 7A	JSR $7AAF	; Locate Variable
56BB: 85 4B	STA $4B
56BD: 84 4C	STY $4C
56BF: A2 01	LDX #$01

56C1: B5 3D	LDA $3D,X	; Textpointer: BASIC work point (chrget)
56C3: 95 4D	STA $4D,X
56C5: B5 45	LDA $45,X
56C7: 95 3D	STA $3D,X	; Textpointer: BASIC work point (chrget)
56C9: CA	DEX
56CA: 10 F5	BPL $56C1
56CC: 20 86 03	JSR $0386	; CHRGOT entry
56CF: D0 31	BNE $5702
56D1: 24 13	BIT $13
56D3: 50 1A	BVC $56EF
56D5: A5 77	LDA $77
56D7: C9 F9	CMP #$F9
56D9: D0 08	BNE $56E3

56DB: 20 09 91	JSR $9109
56DE: AA	TAX
56DF: F0 FA	BEQ $56DB
56E1: D0 03	BNE $56E6

56E3: 20 09 91	JSR $9109

56E6: 8D 00 02	STA $0200
56E9: A2 FF	LDX #$FF
56EB: A0 01	LDY #$01
56ED: D0 0F	BNE $56FE

56EF: 10 03	BPL $56F4
56F1: 4C CA 57	JMP $57CA

56F4: A5 15	LDA $15 	; Current I/O prompt flag
56F6: D0 03	BNE $56FB
56F8: 20 0A 56	JSR $560A	; -print '?'-

56FB: 20 9C 56	JSR $569C	; Prompt & Input

56FE: 86 3D	STX $3D 	; Textpointer: BASIC work point (chrget)
5700: 84 3E	STY $3E

5702: 20 80 03	JSR $0380	; CHRGET
5705: 24 0F	BIT $0F
5707: 10 31	BPL $573A
5709: 24 13	BIT $13
570B: 50 09	BVC $5716
570D: E8	INX
570E: 86 3D	STX $3D 	; Textpointer: BASIC work point (chrget)
5710: A9 00	LDA #$00
5712: 85 09	STA $09 	; SYS and MLM register save (SP)
5714: F0 0C	BEQ $5722

5716: 85 09	STA $09 	; SYS and MLM register save (SP)
5718: C9 22	CMP #$22
571A: F0 07	BEQ $5723
571C: A9 3A	LDA #$3A
571E: 85 09	STA $09 	; SYS and MLM register save (SP)
5720: A9 2C	LDA #$2C

5722: 18	CLC

5723: 85 0A	STA $0A
5725: A5 3D	LDA $3D 	; Textpointer: BASIC work point (chrget)
5727: A4 3E	LDY $3E
5729: 69 00	ADC #$00
572B: 90 01	BCC $572E
572D: C8	INY

572E: 20 A0 86	JSR $86A0
5731: 20 1F 79	JSR $791F
5734: 20 05 54	JSR $5405
5737: 4C 44 57	JMP $5744

573A: A2 00	LDX #$00
573C: 20 22 8D	JSR $8D22	; String to FAC#1
573F: A5 10	LDA $10
5741: 20 E3 53	JSR $53E3

5744: 20 86 03	JSR $0386	; CHRGOT entry
5747: F0 3B	BEQ $5784
5749: C9 2C	CMP #$2C
574B: F0 37	BEQ $5784
574D: A5 13	LDA $13
574F: F0 0A	BEQ $575B
5751: 30 04	BMI $5757
5753: A6 15	LDX $15 	; Current I/O prompt flag
5755: D0 08	BNE $575F

5757: A2 16	LDX #$16
5759: D0 06	BNE $5761

575B: A5 15	LDA $15 	; Current I/O prompt flag
575D: F0 05	BEQ $5764

575F: A2 18	LDX #$18

5761: 4C 3C 4D	JMP $4D3C	; Error

5764: 20 81 92	JSR $9281	; Print Following Text
5767: 3F 52 45 44 4F 20 46 52	; '?redo fr'
576F: 4F 4D 20 53 54 41 52 54	; 'om start'
5777: 0D 00                  	; '{CR}{0}'
5779: AD 02 12	LDA $1202
577C: AC 03 12	LDY $1203
577F: 85 3D	STA $3D 	; Textpointer: BASIC work point (chrget)
5781: 84 3E	STY $3E
5783: 60	RTS

5784: A2 01	LDX #$01

5786: B5 3D	LDA $3D,X	; Textpointer: BASIC work point (chrget)
5788: 95 45	STA $45,X
578A: B5 4D	LDA $4D,X
578C: 95 3D	STA $3D,X	; Textpointer: BASIC work point (chrget)
578E: CA	DEX
578F: 10 F5	BPL $5786
5791: 20 86 03	JSR $0386	; CHRGOT entry
5794: F0 06	BEQ $579C
5796: 20 5C 79	JSR $795C	; -Check Comma
5799: 4C B8 56	JMP $56B8

579C: A5 45	LDA $45
579E: A4 46	LDY $46
57A0: A6 13	LDX $13
57A2: 10 05	BPL $57A9
57A4: 85 43	STA $43
57A6: 84 44	STY $44
57A8: 60	RTS

57A9: A0 00	LDY #$00
57AB: A9 45	LDA #$45
57AD: 20 9F 03	JSR $039F	; Fetch From RAM Bank 0
57B0: F0 17	BEQ $57C9
57B2: A5 15	LDA $15 	; Current I/O prompt flag
57B4: D0 13	BNE $57C9
57B6: 20 81 92	JSR $9281	; Print Following Text
57B9: 3F 45 58 54 52 41 20 49	; '?extra i'
57C1: 47 4E 4F 52 45 44 0D 00	; 'gnored{CR}{0}'

57C9: 60	RTS

57CA: 20 A2 52	JSR $52A2	; Scan To Next Statement
57CD: C8	INY
57CE: AA	TAX
57CF: D0 15	BNE $57E6
57D1: A2 0D	LDX #$0D
57D3: C8	INY
57D4: 20 C9 03	JSR $03C9	; Txtptr Fetch From RAM Bank 0
57D7: F0 40	BEQ $5819
57D9: C8	INY
57DA: 20 C9 03	JSR $03C9	; Txtptr Fetch From RAM Bank 0
57DD: 85 41	STA $41
57DF: C8	INY
57E0: 20 C9 03	JSR $03C9	; Txtptr Fetch From RAM Bank 0
57E3: C8	INY
57E4: 85 42	STA $42

57E6: 20 92 52	JSR $5292
57E9: 20 86 03	JSR $0386	; CHRGOT entry
57EC: AA	TAX
57ED: E0 83	CPX #$83
57EF: D0 D9	BNE $57CA
57F1: 4C 02 57	JMP $5702

; Perform [next]

57F4: D0 13	BNE $5809
57F6: A0 FF	LDY #$FF
57F8: D0 14	BNE $580E

57FA: A0 12	LDY #$12
57FC: 20 59 50	JSR $5059	; Move B-Stack Up
57FF: 20 86 03	JSR $0386	; CHRGOT entry
5802: C9 2C	CMP #$2C
5804: D0 71	BNE $5877
5806: 20 80 03	JSR $0380	; CHRGET

5809: 20 AF 7A	JSR $7AAF	; Locate Variable
580C: 85 4B	STA $4B

580E: 84 4C	STY $4C
5810: A9 81	LDA #$81
5812: 20 AA 4F	JSR $4FAA	; Search B-Stack For Match
5815: F0 05	BEQ $581C
5817: A2 0A	LDX #$0A

5819: 4C 3C 4D	JMP $4D3C	; Error

581C: 20 50 50	JSR $5050	; Set B-Stack Pointer
581F: A5 3F	LDA $3F
5821: 18	CLC
5822: 69 03	ADC #$03
5824: A4 40	LDY $40
5826: 90 01	BCC $5829
5828: C8	INY

5829: 20 D4 8B	JSR $8BD4	; Unpack ROM to FAC#1
582C: A0 08	LDY #$08
582E: B1 3F	LDA ($3F),Y
5830: 85 68	STA $68
5832: A0 01	LDY #$01
5834: B1 3F	LDA ($3F),Y
5836: 48	PHA
5837: AA	TAX
5838: C8	INY
5839: B1 3F	LDA ($3F),Y
583B: 48	PHA
583C: A8	TAY
583D: 8A	TXA
583E: 20 45 88	JSR $8845	; Add Memory
5841: 68	PLA
5842: A8	TAY
5843: 68	PLA
5844: AA	TAX
5845: 8D 04 FF	STA $FF04
5848: 20 00 8C	JSR $8C00	; Pack FAC#1 to RAM1
584B: A5 3F	LDA $3F
584D: 18	CLC
584E: 69 09	ADC #$09
5850: A4 40	LDY $40
5852: 90 01	BCC $5855
5854: C8	INY

5855: 8D 03 FF	STA $FF03
5858: 20 87 8C	JSR $8C87	; Compare FAC#1 to Memory
585B: A0 08	LDY #$08
585D: 38	SEC
585E: F1 3F	SBC ($3F),Y
5860: F0 98	BEQ $57FA
5862: A0 11	LDY #$11
5864: B1 3F	LDA ($3F),Y
5866: 85 3D	STA $3D 	; Textpointer: BASIC work point (chrget)
5868: 88	DEY
5869: B1 3F	LDA ($3F),Y
586B: 85 3E	STA $3E
586D: 88	DEY
586E: B1 3F	LDA ($3F),Y
5870: 85 3C	STA $3C
5872: 88	DEY
5873: B1 3F	LDA ($3F),Y
5875: 85 3B	STA $3B

5877: 60	RTS

5878: 20 5C 79	JSR $795C	; -Check Comma

; Perform [dim]

587B: AA	TAX
587C: 20 B4 7A	JSR $7AB4
587F: 20 86 03	JSR $0386	; CHRGOT entry
5882: D0 F4	BNE $5878
5884: 60	RTS

; Perform [sys]

5885: 20 12 88	JSR $8812	; -Input Float/Fixed Value
5888: A5 16	LDA $16
588A: 85 04	STA $04 	; SYS address high, MLM register PC
588C: A5 17	LDA $17
588E: 85 03	STA $03 	; SYS address low, MLM register PC
5890: AD D5 03	LDA $03D5	; Current Bank For SYS, POKE, PEEK
5893: 85 02	STA $02 	; Bank Number, Jump to SYS Address
5895: 20 1E 9E	JSR $9E1E
5898: 90 02	BCC $589C
589A: 86 06	STX $06 	; SYS and MLM register save (A)

589C: 20 1E 9E	JSR $9E1E
589F: 90 02	BCC $58A3
58A1: 86 07	STX $07 	; SYS and MLM register save (X)

58A3: 20 1E 9E	JSR $9E1E
58A6: 90 02	BCC $58AA
58A8: 86 08	STX $08 	; SYS and MLM register save (Y)

58AA: 20 1E 9E	JSR $9E1E
58AD: 90 02	BCC $58B1
58AF: 86 05	STX $05 	; SYS and MLM register save (SR)

58B1: 4C 6E FF	JMP $FF6E	; jsrfar

; Perform [tron]

58B4: A9 FF	LDA #$FF
58B6: 2C	.BYTE $2C

; Perform [troff]

58B7: A9 00	LDA #$00
58B9: 8D 6F 11	STA $116F	; Trace Mode: FF = on
58BC: 60	RTS

; Perform [rreg]

58BD: A9 00	LDA #$00
58BF: 85 0D	STA $0D

58C1: 20 86 03	JSR $0386	; CHRGOT entry
58C4: F0 37	BEQ $58FD
58C6: C9 2C	CMP #$2C
58C8: F0 21	BEQ $58EB
58CA: 20 AF 7A	JSR $7AAF	; Locate Variable
58CD: 85 4B	STA $4B
58CF: 84 4C	STY $4C
58D1: A5 0F	LDA $0F
58D3: D0 29	BNE $58FE
58D5: A4 0D	LDY $0D
58D7: B9 06 00	LDA $06,Y	; SYS and MLM register save (A)
58DA: C0 03	CPY #$03
58DC: D0 02	BNE $58E0
58DE: A5 05	LDA $05 	; SYS and MLM register save (SR)

58E0: A8	TAY
58E1: A9 00	LDA #$00
58E3: 20 3C 79	JSR $793C	; Fixed-Float
58E6: A5 10	LDA $10
58E8: 20 E3 53	JSR $53E3

58EB: E6 0D	INC $0D
58ED: A5 0D	LDA $0D
58EF: C9 04	CMP #$04
58F1: B0 0A	BCS $58FD
58F3: 20 86 03	JSR $0386	; CHRGOT entry
58F6: F0 05	BEQ $58FD
58F8: 20 80 03	JSR $0380	; CHRGET
58FB: D0 C4	BNE $58C1

58FD: 60	RTS

58FE: 4C E7 77	JMP $77E7	; Print 'type mismatch'

; Assign <mid$>

5901: 20 59 79	JSR $7959	; -Check Left Parenthesis
5904: 20 AF 7A	JSR $7AAF	; Locate Variable
5907: 85 4B	STA $4B
5909: 84 4C	STY $4C
590B: 20 DD 77	JSR $77DD	; Confirm String
590E: 20 09 88	JSR $8809
5911: CA	DEX
5912: 86 78	STX $78
5914: C9 29	CMP #$29
5916: F0 04	BEQ $591C
5918: 20 09 88	JSR $8809
591B: 2C	.BYTE $2C

591C: A2 FF	LDX #$FF
591E: 86 77	STX $77
5920: 20 56 79	JSR $7956	; -Check Right Parenthesis
5923: A9 B2	LDA #$B2
5925: 20 5E 79	JSR $795E
5928: 20 EF 77	JSR $77EF	; Evaluate Expression
592B: 20 DD 77	JSR $77DD	; Confirm String
592E: A0 02	LDY #$02

5930: A9 4B	LDA #$4B
5932: 20 AB 03	JSR $03AB	; Fetch From RAM Bank 1
5935: 99 5D 00	STA $5D,Y
5938: 20 E7 42	JSR $42E7	; Get From ($66) Bank1
593B: 99 60 00	STA $60,Y
593E: 88	DEY
593F: 10 EF	BPL $5930
5941: 38	SEC
5942: A5 61	LDA $61
5944: E5 78	SBC $78
5946: 85 61	STA $61
5948: B0 02	BCS $594C
594A: C6 62	DEC $62

594C: A5 77	LDA $77
594E: C5 60	CMP $60
5950: 90 02	BCC $5954
5952: A5 60	LDA $60

5954: AA	TAX
5955: F0 18	BEQ $596F
5957: 18	CLC
5958: 65 78	ADC $78
595A: B0 16	BCS $5972
595C: C5 5D	CMP $5D
595E: 90 02	BCC $5962
5960: D0 10	BNE $5972

5962: A4 78	LDY $78

5964: A9 61	LDA #$61
5966: 20 AB 03	JSR $03AB	; Fetch From RAM Bank 1
5969: 91 5E	STA ($5E),Y
596B: C8	INY
596C: CA	DEX
596D: D0 F5	BNE $5964

596F: 4C 81 87	JMP $8781

5972: 4C 28 7D	JMP $7D28	; Print 'illegal quantity'

; Perform [auto]

5975: 20 F0 84	JSR $84F0	; Check Direct
5978: 20 A0 50	JSR $50A0	; Get Fixed Pt Number
597B: A5 16	LDA $16
597D: 85 74	STA $74 	; Auto line number increment
597F: A5 17	LDA $17
5981: 85 75	STA $75
5983: 4C 37 4D	JMP $4D37	; Error or Ready

; Perform [help]

5986: AE 08 12	LDX $1208
5989: E8	INX
598A: F0 1D	BEQ $59A9
598C: AD 09 12	LDA $1209
598F: AC 0A 12	LDY $120A
5992: 85 16	STA $16
5994: 84 17	STY $17
5996: 20 64 50	JSR $5064	; Find Basic Line
5999: 90 0E	BCC $59A9
599B: 66 55	ROR $55
599D: 20 98 55	JSR $5598
59A0: A6 16	LDX $16
59A2: A5 17	LDA $17
59A4: 20 23 51	JSR $5123	; List Subroutine
59A7: 46 55	LSR $55

59A9: 4C 98 55	JMP $5598

; Insert Help Marker

59AC: A6 62	LDX $62
59AE: 98	TYA
59AF: 18	CLC
59B0: 65 61	ADC $61
59B2: 90 01	BCC $59B5
59B4: E8	INX

59B5: EC 0F 12	CPX $120F
59B8: D0 14	BNE $59CE
59BA: CD 0E 12	CMP $120E
59BD: 90 0F	BCC $59CE
59BF: F0 0D	BEQ $59CE
59C1: 46 55	LSR $55
59C3: A9 12	LDA #$12
59C5: 24 D7	BIT $D7 	; 40 / 80 columns:  0 = 40, 128 = 80
59C7: 10 02	BPL $59CB
59C9: A9 02	LDA #$02

59CB: 4C 0C 56	JMP $560C

59CE: 60	RTS

; Perform [gosub]

59CF: 20 1D 5A	JSR $5A1D	; Put Sub To B-Stack
59D2: 20 86 03	JSR $0386	; CHRGOT entry
59D5: 20 DB 59	JSR $59DB	; Perform [goto]
59D8: 4C F6 4A	JMP $4AF6

; Perform [goto]

59DB: 20 A0 50	JSR $50A0	; Get Fixed Pt Number
59DE: A5 0A	LDA $0A
59E0: F0 38	BEQ $5A1A

59E2: 20 A5 52	JSR $52A5	; Scan To Next Line
59E5: 38	SEC
59E6: A5 3B	LDA $3B
59E8: E5 16	SBC $16
59EA: A5 3C	LDA $3C
59EC: E5 17	SBC $17
59EE: B0 0B	BCS $59FB
59F0: 98	TYA
59F1: 38	SEC
59F2: 65 3D	ADC $3D 	; Textpointer: BASIC work point (chrget)
59F4: A6 3E	LDX $3E
59F6: 90 07	BCC $59FF
59F8: E8	INX
59F9: B0 04	BCS $59FF

59FB: A5 2D	LDA $2D 	; Pointer: Start-of-BASIC (bank 0)
59FD: A6 2E	LDX $2E

59FF: 20 68 50	JSR $5068
5A02: 90 11	BCC $5A15	; Undef'd Statement
5A04: A5 61	LDA $61
5A06: E9 01	SBC #$01
5A08: 85 3D	STA $3D 	; Textpointer: BASIC work point (chrget)
5A0A: A5 62	LDA $62
5A0C: E9 00	SBC #$00
5A0E: 85 3E	STA $3E
5A10: 24 7F	BIT $7F
5A12: 10 6D	BPL $5A81
5A14: 60	RTS

; Undef'd Statement

5A15: A2 11	LDX #$11
5A17: 4C 3C 4D	JMP $4D3C	; Error

5A1A: 4C 6C 79	JMP $796C	; Syntax Error

; Put Sub To B-Stack

5A1D: A9 05	LDA #$05
5A1F: 20 FE 4F	JSR $4FFE	; Move B-Stack Down
5A22: A0 04	LDY #$04
5A24: A5 3E	LDA $3E
5A26: 91 7D	STA ($7D),Y
5A28: 88	DEY
5A29: A5 3D	LDA $3D 	; Textpointer: BASIC work point (chrget)
5A2B: 91 7D	STA ($7D),Y
5A2D: 88	DEY
5A2E: A5 3C	LDA $3C
5A30: 91 7D	STA ($7D),Y
5A32: 88	DEY
5A33: A5 3B	LDA $3B
5A35: 91 7D	STA ($7D),Y
5A37: 88	DEY
5A38: A9 8D	LDA #$8D
5A3A: 91 7D	STA ($7D),Y
5A3C: 60	RTS

; Perform [go]

5A3D: 20 80 03	JSR $0380	; CHRGET
5A40: C9 A4	CMP #$A4
5A42: D0 06	BNE $5A4A
5A44: 20 80 03	JSR $0380	; CHRGET
5A47: 4C DB 59	JMP $59DB	; Perform [goto]

5A4A: 20 F4 87	JSR $87F4	; -Eval Byte Parameter
5A4D: E0 40	CPX #$40
5A4F: F0 03	BEQ $5A54
5A51: 4C 6C 79	JMP $796C	; Syntax Error

5A54: 20 E1 A7	JSR $A7E1	; Print 'are you sure'
5A57: D0 06	BNE $5A5F
5A59: 20 45 A8	JSR $A845	; Set Bank 15
5A5C: 4C 4D FF	JMP $FF4D	; 64mode

5A5F: 60	RTS

; Perform [cont]

5A60: D0 38	BNE $5A9A
5A62: 24 7F	BIT $7F
5A64: 30 34	BMI $5A9A
5A66: A2 1A	LDX #$1A
5A68: AC 03 12	LDY $1203
5A6B: D0 03	BNE $5A70
5A6D: 4C 3C 4D	JMP $4D3C	; Error

5A70: AD 02 12	LDA $1202
5A73: 85 3D	STA $3D 	; Textpointer: BASIC work point (chrget)
5A75: 84 3E	STY $3E
5A77: AD 00 12	LDA $1200
5A7A: AC 01 12	LDY $1201
5A7D: 85 3B	STA $3B
5A7F: 84 3C	STY $3C

5A81: A9 80	LDA #$80
5A83: 85 7F	STA $7F
5A85: 0A	ASL A
5A86: 85 74	STA $74 	; Auto line number increment
5A88: 85 75	STA $75
5A8A: 8D 7F 12	STA $127F	; Collision Mask
5A8D: 85 F6	STA $F6 	; Auto-Insert Mode Flag
5A8F: A2 02	LDX #$02

5A91: 9D 76 12	STA $1276,X	; Collision IRQ Task Table
5A94: CA	DEX
5A95: 10 FA	BPL $5A91
5A97: 4C 90 FF	JMP $FF90	; setmsg        Control OS Messages

5A9A: 60	RTS

; Perform [run]

5A9B: F0 18	BEQ $5AB5
5A9D: 90 1C	BCC $5ABB
5A9F: A9 40	LDA #$40
5AA1: 85 7F	STA $7F
5AA3: 20 A7 A1	JSR $A1A7	; Perform [dload]

5AA6: 20 81 5A	JSR $5A81
5AA9: 20 F3 51	JSR $51F3	; Set Up Run
5AAC: 20 4F 4F	JSR $4F4F	; Rechain Lines
5AAF: 20 98 55	JSR $5598
5AB2: 4C F6 4A	JMP $4AF6

5AB5: 20 81 5A	JSR $5A81
5AB8: 4C F3 51	JMP $51F3	; Set Up Run

5ABB: 20 FA 51	JSR $51FA
5ABE: 20 86 03	JSR $0386	; CHRGOT entry
5AC1: 20 DB 59	JSR $59DB	; Perform [goto]
5AC4: 20 81 5A	JSR $5A81
5AC7: 4C F6 4A	JMP $4AF6

; Perform [restore]

5ACA: F0 15	BEQ $5AE1
5ACC: 20 12 88	JSR $8812	; -Input Float/Fixed Value
5ACF: 84 16	STY $16
5AD1: 85 17	STA $17
5AD3: 20 64 50	JSR $5064	; Find Basic Line
5AD6: B0 03	BCS $5ADB
5AD8: 4C 15 5A	JMP $5A15	; Undef'd Statement

5ADB: A5 61	LDA $61
5ADD: A4 62	LDY $62
5ADF: B0 05	BCS $5AE6

5AE1: 38	SEC
5AE2: A5 2D	LDA $2D 	; Pointer: Start-of-BASIC (bank 0)
5AE4: A4 2E	LDY $2E

5AE6: E9 01	SBC #$01
5AE8: B0 01	BCS $5AEB
5AEA: 88	DEY

5AEB: 85 43	STA $43
5AED: 84 44	STY $44

5AEF: 60	RTS

; Keywords To Renumber

5AF0: 89 8A 8D A7 8C D6 D7 D5	; '..{SHCR}..VWU'
; GOTO, RUN, GOSUB, THEN, RESTORE, RESUME, TRAP, ELSE

; Perform [renumber]

5AF8: 20 F0 84	JSR $84F0	; Check Direct
5AFB: A9 00	LDA #$00
5AFD: A2 0A	LDX #$0A	; default value =10
5AFF: 8E 70 11	STX $1170	; for start
5B02: 8D 71 11	STA $1171
5B05: 8E 72 11	STX $1172	; and step!
5B08: 8D 73 11	STA $1173
5B0B: 85 5C	STA $5C
5B0D: 85 5D	STA $5D
5B0F: 20 86 03	JSR $0386	; CHRGOT entry
5B12: F0 54	BEQ $5B68       ; no parameters
5B14: 20 A0 50	JSR $50A0	; 1st parameter Start: Get Fixed Pt Number -> $16/$17
5B17: A5 0A	LDA $0A
5B19: F0 0A	BEQ $5B25
5B1B: A5 16	LDA $16
5B1D: A6 17	LDX $17
5B1F: 8D 70 11	STA $1170	; save new start value
5B22: 8E 71 11	STX $1171

5B25: 20 06 9E	JSR $9E06	; 2nd parameter Step: Optional Float/Fixed Parameter
5B28: 90 0E	BCC $5B38       ; No value?
5B2A: 8C 72 11	STY $1172
5B2D: 8D 73 11	STA $1173	; is new value =0?
5B30: 0D 72 11	ORA $1172
5B33: D0 03	BNE $5B38

5B35: 4C 28 7D	JMP $7D28	; Error 'illegal quantity'

5B38: 20 06 9E	JSR $9E06	; 3rd parameter Oldstart: Optional Float/Fixed Parameter
5B3B: 90 2B	BCC $5B68       ; No value?
5B3D: 84 5C	STY $5C		; line to start of (old start)
5B3F: 84 16	STY $16
5B41: 85 5D	STA $5D
5B43: 85 17	STA $17
5B45: 20 64 50	JSR $5064	; Find Basic Line ($16/$17)
5B48: A5 61	LDA $61
5B4A: A6 62	LDX $62
5B4C: 85 5A	STA $5A		; Pointer to first line
5B4E: 86 5B	STX $5B
5B50: AD 70 11	LDA $1170	; New start line
5B53: AE 71 11	LDX $1171
5B56: 85 16	STA $16
5B58: 86 17	STX $17
5B5A: 20 64 50	JSR $5064	; Find Basic Line
5B5D: 38	SEC
5B5E: A5 61	LDA $61		; Old start line address (O3) - new start line address (N1)
5B60: E5 5A	SBC $5A		; O1   O2 O3  (old line numbering)
5B62: A5 62	LDA $62		; |----|--|=|=======|
5B64: E5 5B	SBC $5B		;           N1      N2
				; "-" untouched area, "=" changed area
				; A line with the number range N1 N2 must not lay inside
				; the untouched area, otherwise the line number would
				; appear twice!
5B66: 90 CD	BCC $5B35       ; < -> illegal quantity error

; Start of pass 1: check if new linenumbers are in a valid range (does not exceed 63999)

5B68: 20 68 5D	JSR $5D68	; Get Renumber Start
				; ($1170/$1171) -> ($64/$65), textptr to BASIC start ($2D/$2E)-1 -> $3D/$3E
5B6B: 20 9C 5D	JSR $5D9C       ; Scan ahead ($3D/$3E)++, Y=0, link low
5B6E: C8	INY		; Y=1	
5B6F: 20 C9 03	JSR $03C9	; Txtptr Fetch From RAM Bank 0 with offset 1: link high
5B72: F0 3A	BEQ $5BAE	; Start real pass 1

; Advance to old start line loop:
5B74: C8	INY		; Y=2 (Y=1 if coming from $5886)
5B75: 20 C9 03	JSR $03C9	; Txtptr Fetch From RAM Bank 0 with offset 2: number low
5B78: 38	SEC
5B79: E5 5C	SBC $5C
5B7B: C8	INY		; Y=3
5B7C: 20 C9 03	JSR $03C9	; Txtptr Fetch From RAM Bank 0 with offset 3: number high
5B7F: E5 5D	SBC $5D
5B81: B0 07	BCS $5B8A       ; current line >= old start line
5B83: 20 9D 5B	JSR $5B9D       ; advance to next line (textptr at link high)
5B86: D0 EC	BNE $5B74       ; loop
5B88: F0 24	BEQ $5BAE	; Start real pass 1

; Step through new lines loop:
5B8A: 20 9D 5B	JSR $5B9D       ; advance to next line (textptr at link high)
5B8D: F0 1F	BEQ $5BAE	; End of text Start real pass 1
5B8F: 20 89 5D	JSR $5D89	; line number += step ($65/$64) += ($1172/$1173)
5B92: B0 04	BCS $5B98
5B94: C9 F9	CMP #$F9	; Line number passed 63999?
5B96: 90 F2	BCC $5B8A

5B98: A2 26	LDX #$26	; Yes, lLine number too large error
5B9A: 4C 3C 4D	JMP $4D3C	; Error

; Advance to next line traversing the link pointer

5B9D: A0 00	LDY #$00	
5B9F: 20 C9 03	JSR $03C9	; Txtptr Fetch From RAM Bank 0: Link low
5BA2: AA	TAX
5BA3: C8	INY
5BA4: 20 C9 03	JSR $03C9	; Txtptr Fetch From RAM Bank 0: Link high
5BA7: F0 04	BEQ $5BAD
5BA9: 86 3D	STX $3D 	; Textpointer: BASIC work point (chrget)
5BAB: 85 3E	STA $3E

5BAD: 60	RTS

; Real pass 1

5BAE: A9 01	LDA #$01
5BB0: 85 77	STA $77		; Pass down counter = 1
5BB2: AD 10 12	LDA $1210	; End of Basic, Bank 0
5BB5: AE 11 12	LDX $1211
5BB8: 85 3F	STA $3F		; Block move end pointer
5BBA: 86 40	STX $40
5BBC: 20 FB 5B	JSR $5BFB	; Renumber Scan, first pass
5BBF: C6 77	DEC $77
5BC1: 20 FB 5B	JSR $5BFB	; Renumber Scan, second pass

; Change all line numbers:
5BC4: 20 99 5D	JSR $5D99	; Scan Ahead, link high
5BC7: F0 2F	BEQ $5BF8       ; Exit with "Rechain lines" if end of text
5BC9: 20 9C 5D	JSR $5D9C       ; Scan ahead ($3D/$3E)++, Y=0, line number low
5BCC: 85 16	STA $16
5BCE: C8	INY		; Y=1
5BCF: 20 C9 03	JSR $03C9	; Txtptr Fetch From RAM Bank 0 Offset 1, line number high
5BD2: 38	SEC
5BD3: E5 5D	SBC $5D		; compare high byte with old start line
5BD5: 90 19	BCC $5BF0
5BD7: D0 06	BNE $5BDF
5BD9: A5 16	LDA $16		; compare low byte with old start line
5BDB: E5 5C	SBC $5C
5BDD: 90 11	BCC $5BF0       ; Start found

5BDF: A5 64	LDA $64		; Set new line number high
5BE1: 91 3D	STA ($3D),Y	; Textpointer: BASIC work point (chrget)
5BE3: 88	DEY
5BE4: A5 65	LDA $65		; Set new line number low
5BE6: 91 3D	STA ($3D),Y	; Textpointer: BASIC work point (chrget)
5BE8: 20 9C 5D	JSR $5D9C       ; Scan ahead ($3D/$3E)++, Y=0, link low
5BEB: 20 80 5D	JSR $5D80       ; Add step to new line number ($65/$64), advance to end of line
5BEE: F0 D4	BEQ $5BC4       ; Branch always, looping line number change

5BF0: 20 9C 5D	JSR $5D9C       ; Scan ahead ($3D/$3E)++, Y=0, link low
5BF3: 20 83 5D	JSR $5D83       ; Read to end of line
5BF6: F0 CC	BEQ $5BC4       ; Branch always, Looping line number change

5BF8: 4C E5 5E	JMP $5EE5       ; Rechain lines

; Renumber Scan

5BFB: 20 54 52	JSR $5254	; Textptr to BASIC start minus 1

5BFE: 20 99 5D	JSR $5D99	; Skip 2 bytes
5C01: D0 03	BNE $5C06       ; Continue with scan
5C03: 4C 68 5D	JMP $5D68	; End of text -> Get Renumber Start

5C06: 20 9C 5D	JSR $5D9C       ; Scan ahead ($3D/$3E)++, Y=0, line number low
5C09: 85 4B	STA $4B
5C0B: 20 9C 5D	JSR $5D9C       ; Scan ahead ($3D/$3E)++, Y=0, line number high
5C0E: 85 4C	STA $4C

5C10: 20 9C 5D	JSR $5D9C       ; Scan ahead ($3D/$3E)++, Y=0, line text

5C13: C9 22	CMP #$22	; Quote, in string?
5C15: D0 0B	BNE $5C22

5C17: 20 9C 5D	JSR $5D9C       ; Scan ahead ($3D/$3E)++, Y=0, string byte
5C1A: F0 E2	BEQ $5BFE       ; End of text?
5C1C: C9 22	CMP #$22	; End of string?
5C1E: D0 F7	BNE $5C17       ; Continue in string
5C20: F0 EE	BEQ $5C10       ; End of string

5C22: AA	TAX		; BASIC text byte (not in string)
5C23: F0 D9	BEQ $5BFE       ; End of line, continue with next line
5C25: 10 E9	BPL $5C10       ; Not a token, continue scan
5C27: A2 08	LDX #$08	; Check for 8 tokens ...

5C29: DD EF 5A	CMP $5AEF,X     ; Check for line number command token
5C2C: F0 28	BEQ $5C56
5C2E: CA	DEX
5C2F: D0 F8	BNE $5C29       ; Check for next token in list
5C31: C9 CB	CMP #$CB	; GO token
5C33: D0 0B	BNE $5C40

5C35: 20 80 03	JSR $0380	; CHRGET
5C38: F0 C4	BEQ $5BFE       ; End of line, continue with next line
5C3A: C9 A4	CMP #$A4	; TO token
5C3C: F0 18	BEQ $5C56       ; Handle line number
5C3E: D0 D0	BNE $5C10       ; Loop through text

5C40: C9 FE	CMP #$FE	; Token extension prefix
5C42: D0 CC	BNE $5C10
5C44: 20 80 03	JSR $0380	; CHRGET
5C47: F0 EC	BEQ $5C35
5C49: C9 17	CMP #$17	; COLLISION command?
5C4B: D0 C3	BNE $5C10

5C4D: 20 80 03	JSR $0380	; CHRGET
5C50: F0 E3	BEQ $5C35       ; End of line
5C52: C9 2C	CMP #$2C	; search for ","
5C54: D0 F7	BNE $5C4D       ; No COLLISION with line number argument

; Renumber scan: handle line number

5C56: A5 3D	LDA $3D 	; Textpointer: BASIC work point (chrget)
5C58: 8D 00 12	STA $1200	; save current textptr to $1200/$1201
5C5B: A5 3E	LDA $3E
5C5D: 8D 01 12	STA $1201
5C60: 20 80 03	JSR $0380	; CHRGET, get line number digit
5C63: B0 AE	BCS $5C13       ; no digit, contine scan line text
5C65: 20 A0 50	JSR $50A0	; Get Fixed Pt Number: line number old
5C68: 20 19 5D	JSR $5D19	; Convert Line Number: to line number new
5C6B: AD 00 12	LDA $1200	; restore textptr (start of line number)
5C6E: 85 3D	STA $3D 	; Textpointer: BASIC work point (chrget)
5C70: AD 01 12	LDA $1201
5C73: 85 3E	STA $3E
5C75: 20 80 03	JSR $0380	; CHRGET
5C78: A5 3D	LDA $3D 	; Decrement Textpointer
5C7A: D0 02	BNE $5C7E
5C7C: C6 3E	DEC $3E

5C7E: C6 3D	DEC $3D 	; Textpointer: BASIC work point (chrget)
5C80: A2 FF	LDX #$FF
5C82: A5 77	LDA $77
5C84: F0 41	BEQ $5CC7       ; 2nd pass handler

; Scan during first pass:
5C86: 20 8E 7E	JSR $7E8E	; Patch for Renumber Scan: $5C8F+CHRGOT

5C89: C9 2C	CMP #$2C	; ","?
5C8B: F0 C9	BEQ $5C56       ; Handle next line number
5C8D: D0 84	BNE $5C13       ; Contine scan line text

5C8F: E8	INX
5C90: BD 01 01	LDA $0101,X	; New line number
5C93: F0 1F	BEQ $5CB4       ; End of new line number? new line number is shorter!
5C95: 20 80 03	JSR $0380	; CHRGET      ; Old line number digit
5C98: 90 F5	BCC $5C8F       ; Loop as long old and new number has a digit

; longer line number

5C9A: E6 3F	INC $3F		; Increment end of text pointer
5C9C: D0 02	BNE $5CA0
5C9E: E6 40	INC $40

5CA0: 38	SEC
5CA1: A5 3F	LDA $3F		; End of text greater or equal than
5CA3: ED 12 12	SBC $1212	; Basic Program Limit [FF00]?
5CA6: A5 40	LDA $40
5CA8: ED 13 12	SBC $1213
5CAB: B0 17	BCS $5CC4       ; Yes -> out of memory error!
5CAD: E8	INX		; Next byte in new line number
5CAE: BD 01 01	LDA $0101,X	; New line number digit
5CB1: D0 E7	BNE $5C9A       ; still longer, loop
5CB3: 60	RTS

; Shorter line number:
5CB4: 20 80 03	JSR $0380	; CHRGET      ; Get digit?
5CB7: B0 0A	BCS $5CC3       ; Exit loop if not a digit
5CB9: A5 3F	LDA $3F		; Decrement end of text pointer
5CBB: D0 02	BNE $5CBF
5CBD: C6 40	DEC $40

5CBF: C6 3F	DEC $3F
5CC1: 90 F1	BCC $5CB4        ; Branch always, next digit loop

5CC3: 60	RTS

5CC4: 4C 3A 4D	JMP $4D3A	; Print 'out of memory'

; Renumber scan: 2nd pass handler: fill in new line number including to adjust room for it

5CC7: E8	INX

5CC8: BD 01 01	LDA $0101,X	; New line number digit
5CCB: F0 2C	BEQ $5CF9       ; Shorter: move block down
5CCD: 48	PHA		; Save new number's digit
5CCE: 20 9C 5D	JSR $5D9C       ; Scan ahead ($3D/$3E)++, Y=0, line number digit
5CD1: C9 3A	CMP #$3A	; ":" -> block move
5CD3: B0 0C	BCS $5CE1
5CD5: C9 20	CMP #$20	; " " -> block move
5CD7: F0 08	BEQ $5CE1
5CD9: 38	SEC		; Check for digit ...
5CDA: E9 30	SBC #$30
5CDC: 38	SEC
5CDD: E9 D0	SBC #$D0
5CDF: 90 10	BCC $5CF1       ; Digit -> write new number into text

5CE1: 20 A7 5D	JSR $5DA7	; Set Up Block Move
5CE4: E6 6D	INC $6D		; Move up
5CE6: 20 DF 5D	JSR $5DDF	; Block Move Up
5CE9: EE 10 12	INC $1210	; Increment End of Basic, Bank 0, low byte
5CEC: D0 03	BNE $5CF1
5CEE: EE 11 12	INC $1211	; High byte

5CF1: 68	PLA		; New line number digit
5CF2: A0 00	LDY #$00
5CF4: 91 3D	STA ($3D),Y	; Write it to the BASIC text, overwrites old number
5CF6: E8	INX
5CF7: D0 CF	BNE $5CC8       ; Next digit of new line number

5CF9: 20 80 03	JSR $0380	; CHRGET, old line number digit
5CFC: B0 8B	BCS $5C89       ; No digit!

5CFE: 20 A7 5D	JSR $5DA7	; Set Up Block Move
5D01: C6 6D	DEC $6D		; Move down (new number is shorter)
5D03: 20 C6 5D	JSR $5DC6	; Block Move Down
5D06: AD 10 12	LDA $1210	; Decrement End of Basic, Bank 0
5D09: D0 03	BNE $5D0E
5D0B: CE 11 12	DEC $1211

5D0E: CE 10 12	DEC $1210	; End of Basic, Bank 0, low byte
5D11: 20 86 03	JSR $0386	; CHRGOT entry
5D14: 90 E8	BCC $5CFE       ; Still a digit, move block down
5D16: 4C 89 5C	JMP $5C89       ; Continue to scan text

; Convert Line Number (find jump destination line $16/$17)

5D19: 20 68 5D	JSR $5D68	; Get Renumber Start -> $65/$64

5D1C: 20 99 5D	JSR $5D99	; loop start: scan Ahead +2
5D1F: D0 0D	BNE $5D2E	; process line ...
5D21: A2 27	LDX #$27	; program end, line not found, error number into X
5D23: A5 4B	LDA $4B		; restore Basic text pointer
5D25: 85 3B	STA $3B
5D27: A5 4C	LDA $4C
5D29: 85 3C	STA $3C
5D2B: 4C 3C 4D	JMP $4D3C	; unresolved reference Error

5D2E: 20 9C 5D	JSR $5D9C	; program line number low
5D31: 85 5A	STA $5A
5D33: C5 16	CMP $16		; equal line searched for?
5D35: D0 27	BNE $5D5E	; fetch line number high and to next line
5D37: 20 9C 5D	JSR $5D9C	; scan ahead
5D3A: 85 5B	STA $5B		; program line number high
5D3C: C5 17	CMP $17		; equal line searched for?
5D3E: D0 23	BNE $5D63	; to next line

; Line number found, check if in new line number range:
5D40: 38	SEC		; destination line 
5D41: E5 5D	SBC $5D		; below old startline?
5D43: 90 08	BCC $5D4D	; below, no conversion needed
5D45: D0 0E	BNE $5D55	; greater, do conversion
5D47: A5 16	LDA $16
5D49: E5 5C	SBC $5C		; check low byte if high is same
5D4B: B0 08	BCS $5D55	; greater, do conversion

5D4D: A5 16	LDA $16		; in old line area, keep line number
5D4F: 85 65	STA $65		; (new line number overwritten with old one)
5D51: A5 17	LDA $17
5D53: 85 64	STA $64

; Convert line number $65/$64 to text into $0100

5D55: A2 90	LDX #$90	; float exponent ($90-$80= $10 = 2^16)
5D57: 38	SEC
5D58: 20 75 8C	JSR $8C75	; Fixed-Float (from $65/64)
5D5B: 4C 42 8E	JMP $8E42	; Float to ASCII (to $0100) and return

5D5E: 20 9C 5D	JSR $5D9C	; scan ahead
5D61: 85 5B	STA $5B		; basic text line number high

5D63: 20 75 5D	JSR $5D75	; Count Off Lines
5D66: F0 B4	BEQ $5D1C	; Branch always, next line

; Get Renumber Start

5D68: AD 70 11	LDA $1170	; Renumber start line low byte
5D6B: 85 65	STA $65
5D6D: AD 71 11	LDA $1171	; Renumber start line high byte
5D70: 85 64	STA $64
5D72: 4C 54 52	JMP $5254	; Textptr to BASIC start minus 1

; Count Off Lines

5D75: A5 5A	LDA $5A		; current line comparing
5D77: 38	SEC
5D78: E5 5C	SBC $5C		; to old startline ...
5D7A: A5 5B	LDA $5B
5D7C: E5 5D	SBC $5D
5D7E: 90 03	BCC $5D83       ; ... below (skip counting)

5D80: 20 89 5D	JSR $5D89	; add renumber increment to $65/$64

5D83: 20 9C 5D	JSR $5D9C	; read basic text byte
5D86: D0 FB	BNE $5D83	; until end of line
5D88: 60	RTS

; Add Renumber Increment

5D89: A5 65	LDA $65		; new line numbers counted up so far
5D8B: 18	CLC
5D8C: 6D 72 11	ADC $1172	; add step parameter
5D8F: 85 65	STA $65
5D91: A5 64	LDA $64
5D93: 6D 73 11	ADC $1173
5D96: 85 64	STA $64
5D98: 60	RTS

; Scan Ahead 2 Bytes

5D99: 20 9C 5D	JSR $5D9C	; scan ahead 2 bytes in basic text

 ; Scan Ahead 1 Byte

5D9C: A0 00	LDY #$00	; scan ahead one byte in basic text
5D9E: E6 3D	INC $3D 	; Textpointer: BASIC work point (chrget)
5DA0: D0 02	BNE $5DA4
5DA2: E6 3E	INC $3E		; pre-increment

5DA4: 4C C9 03	JMP $03C9	; Txtptr Fetch From RAM Bank 0

; Set Up Block Move

5DA7: A5 3D	LDA $3D 	; Textpointer: BASIC work point (chrget)
5DA9: 85 24	STA $24
5DAB: A5 3E	LDA $3E
5DAD: 85 25	STA $25
5DAF: AD 10 12	LDA $1210	; End of Basic, Bank 0
5DB2: 85 26	STA $26
5DB4: AD 11 12	LDA $1211
5DB7: 85 27	STA $27
5DB9: A0 00	LDY #$00
5DBB: 84 0D	STY $0D
5DBD: 84 6D	STY $6D
5DBF: 60	RTS

5DC0: E6 24	INC $24
5DC2: D0 02	BNE $5DC6	; Block Move Down
5DC4: E6 25	INC $25

; Block Move Down

5DC6: A4 0D	LDY $0D
5DC8: C8	INY
5DC9: 20 05 43	JSR $4305	; Get From ($24) Bank0
5DCC: A4 6D	LDY $6D
5DCE: C8	INY
5DCF: 91 24	STA ($24),Y
5DD1: 20 EE 5D	JSR $5DEE	; Check Block Limit
5DD4: D0 EA	BNE $5DC0
5DD6: 60	RTS

5DD7: A5 26	LDA $26
5DD9: D0 02	BNE $5DDD
5DDB: C6 27	DEC $27

5DDD: C6 26	DEC $26

; Block Move Up

5DDF: A4 0D	LDY $0D
5DE1: 20 C0 03	JSR $03C0	; Index2 Indirect Fetch From RAM Bank 0
5DE4: A4 6D	LDY $6D
5DE6: 91 26	STA ($26),Y
5DE8: 20 EE 5D	JSR $5DEE	; Check Block Limit
5DEB: D0 EA	BNE $5DD7
5DED: 60	RTS

; Check Block Limit

5DEE: A5 24	LDA $24
5DF0: C5 26	CMP $26
5DF2: D0 04	BNE $5DF8
5DF4: A5 25	LDA $25
5DF6: C5 27	CMP $27

5DF8: 60	RTS

; Perform [for]

5DF9: A9 80	LDA #$80
5DFB: 85 12	STA $12
5DFD: 20 C6 53	JSR $53C6	; Perform [let]
5E00: A9 81	LDA #$81
5E02: 20 AA 4F	JSR $4FAA	; Search B-Stack For Match
5E05: F0 08	BEQ $5E0F
5E07: A9 12	LDA #$12
5E09: 20 FE 4F	JSR $4FFE	; Move B-Stack Down
5E0C: 20 47 50	JSR $5047	; Copy B-Stack Pointer

5E0F: 20 50 50	JSR $5050	; Set B-Stack Pointer
5E12: 20 A2 52	JSR $52A2	; Scan To Next Statement
5E15: 98	TYA
5E16: A0 11	LDY #$11
5E18: 18	CLC
5E19: 65 3D	ADC $3D 	; Textpointer: BASIC work point (chrget)
5E1B: 91 7D	STA ($7D),Y
5E1D: A5 3E	LDA $3E
5E1F: 69 00	ADC #$00
5E21: 88	DEY
5E22: 91 7D	STA ($7D),Y
5E24: A5 3C	LDA $3C
5E26: 88	DEY
5E27: 91 7D	STA ($7D),Y
5E29: A5 3B	LDA $3B
5E2B: 88	DEY
5E2C: 91 7D	STA ($7D),Y
5E2E: A9 A4	LDA #$A4
5E30: 20 5E 79	JSR $795E
5E33: 20 DA 77	JSR $77DA	; Confirm Numeric
5E36: 20 D7 77	JSR $77D7	; Type Match Check
5E39: A5 68	LDA $68
5E3B: 09 7F	ORA #$7F
5E3D: 25 64	AND $64
5E3F: 85 64	STA $64
5E41: A2 04	LDX #$04
5E43: A0 0D	LDY #$0D

5E45: B5 63	LDA $63,X
5E47: 91 7D	STA ($7D),Y
5E49: CA	DEX
5E4A: 88	DEY
5E4B: 10 F8	BPL $5E45
5E4D: A9 9C	LDA #$9C
5E4F: A0 89	LDY #$89

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

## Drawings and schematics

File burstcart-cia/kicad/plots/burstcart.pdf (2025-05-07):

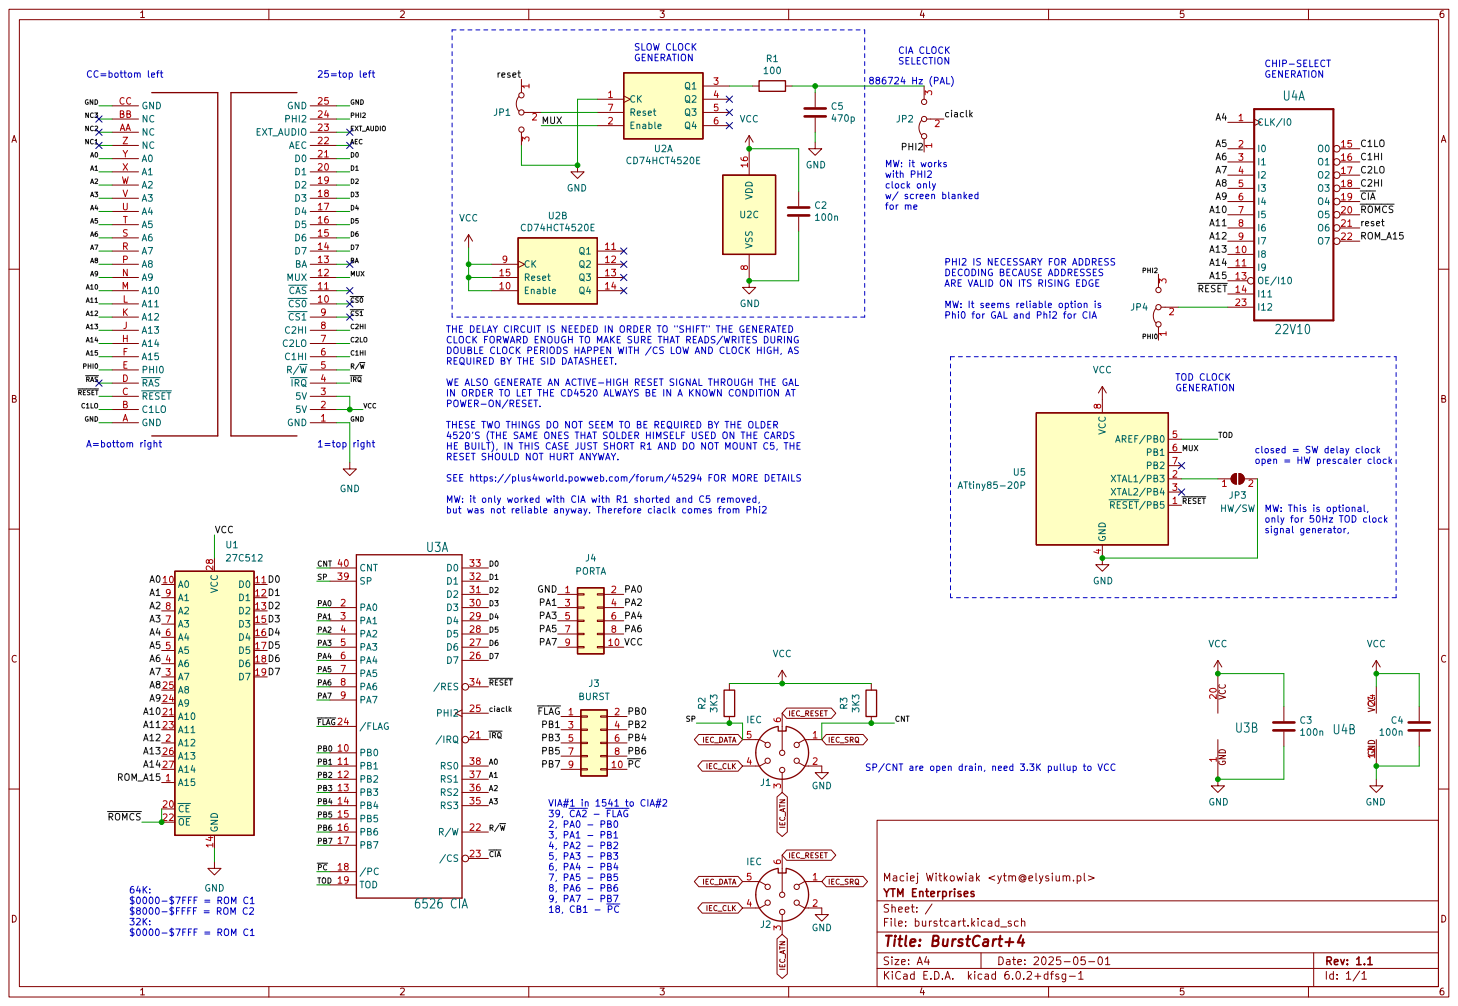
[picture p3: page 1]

ARE VALID ON ITS RISING EDGE MW: It seems reliable option is Phi0 for GAL and Phi2 for CIA CIA CLOCK
SELECTION MW: it works with PHI2

clock only w/ screen blanked

CLOCK FORWARD ENOUGH TO MAKE SURE THAT READS/WRITES DURING
DOUBLE CLOCK PERIODS HAPPEN WITH /CS LOW AND CLOCK HIGH, AS REQUIRED BY THE SID DATASHEET. WE ALSO GENERATE AN ACTIVE-HIGH RESET SIGNAL THROUGH THE GAL

IN ORDER TO LET THE CD4520 ALWAYS BE IN A KNOWN CONDITION AT POWER-ON/RESET. THESE TWO THINGS DO NOT SEEM TO BE REQUIRED BY THE OLDER

4520'S (THE SAME ONES THAT SOLDER HIMSELF USED ON THE CARDS
HE BUILT), IN THIS CASE JUST SHORT R1 AND DO NOT MOUNT C5, THE RESET SHOULD NOT HURT ANYWAY. SEE https://plus4world.powweb.com/forum/45294 FOR MORE DETAILS

closed = SW delay clock
open = HW prescaler clock
JP3 HW/SW GND VCC

MW: it only worked with CIA with R1 shorted and C5 removed,
but was not reliable anyway. Therefore ciaclk comes from Phi2

MW: This is optional,
only for 50Hz TOD clock
signal generator,

SP/CNT are open drain, need 3.3K pullup to VCC

File: burstcart.kicad_sch Sheet: / YTM Enterprises

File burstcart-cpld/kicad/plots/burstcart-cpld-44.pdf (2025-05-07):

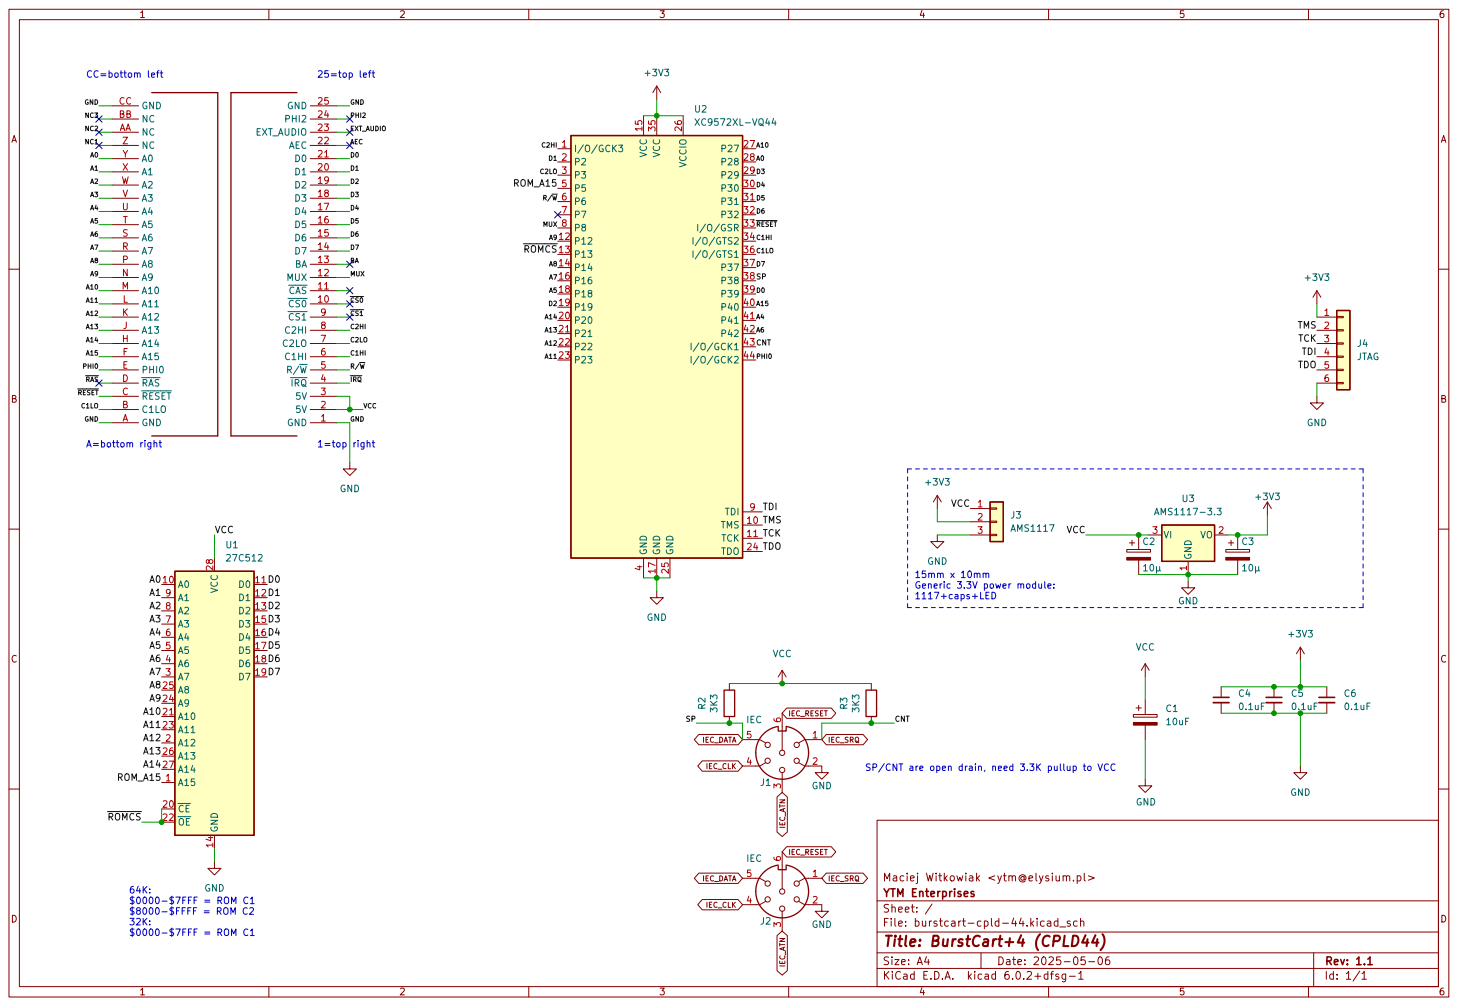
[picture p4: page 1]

CC=bottom left A=bottom right

SP/CNT are open drain, need 3.3K pullup to VCC
IEC_RESET IEC_ATN

File: burstcart-cpld-44.kicad_sch Sheet: / YTM Enterprises

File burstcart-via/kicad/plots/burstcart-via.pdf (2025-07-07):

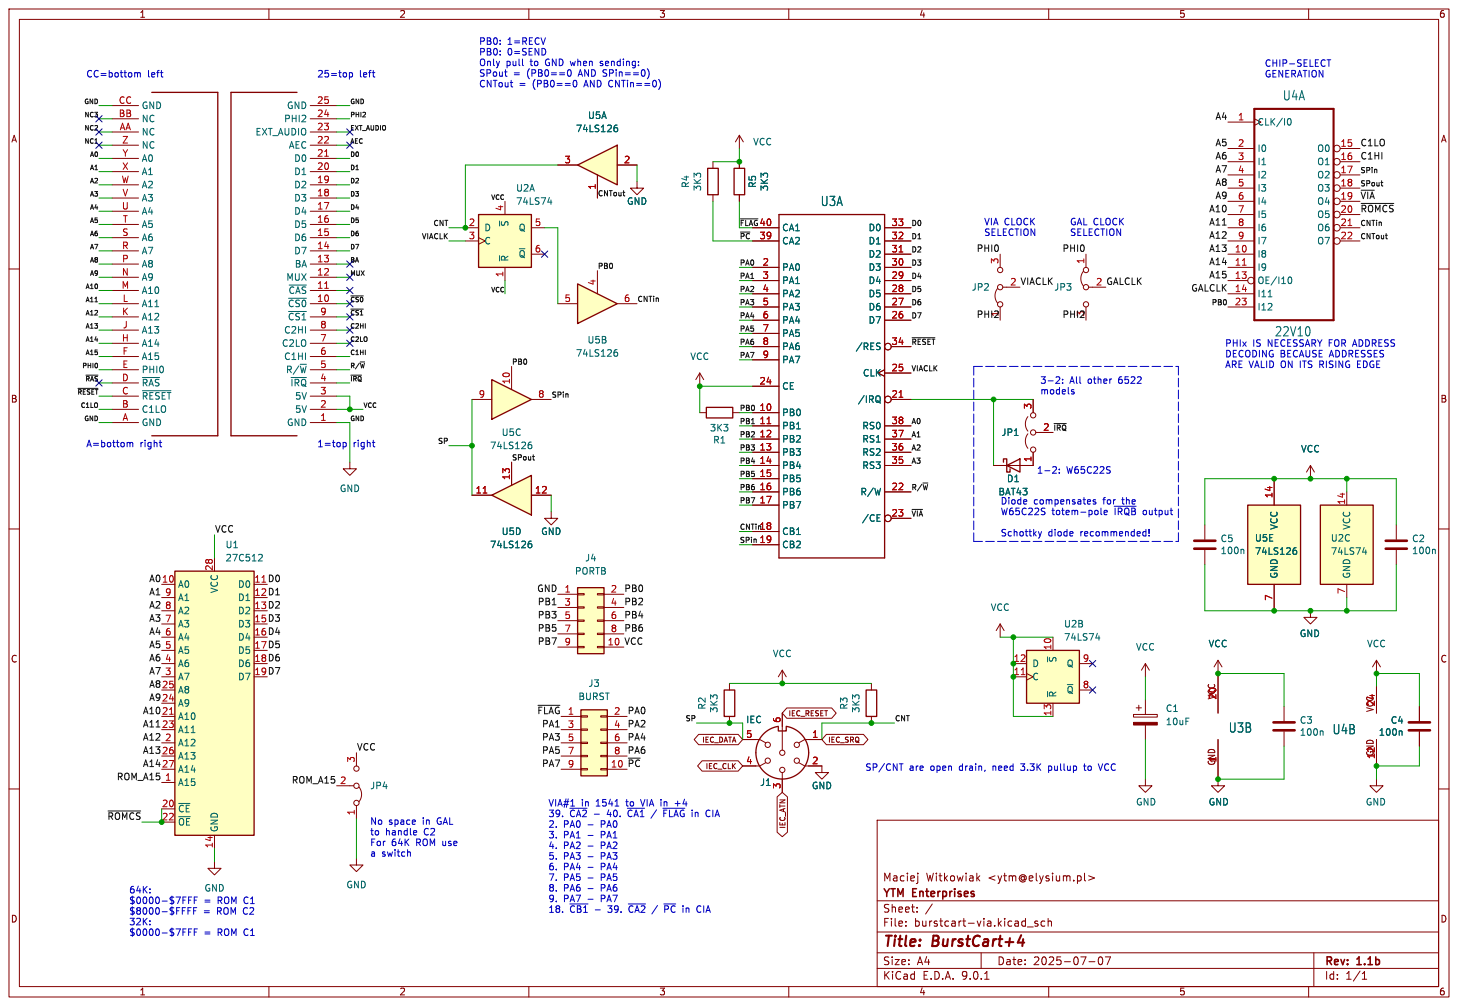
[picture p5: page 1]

PHIx IS NECESSARY FOR ADDRESS DECODING BECAUSE ADDRESSES

ARE VALID ON ITS RISING EDGE

No space in GAL
to handle C2 For 64K ROM use

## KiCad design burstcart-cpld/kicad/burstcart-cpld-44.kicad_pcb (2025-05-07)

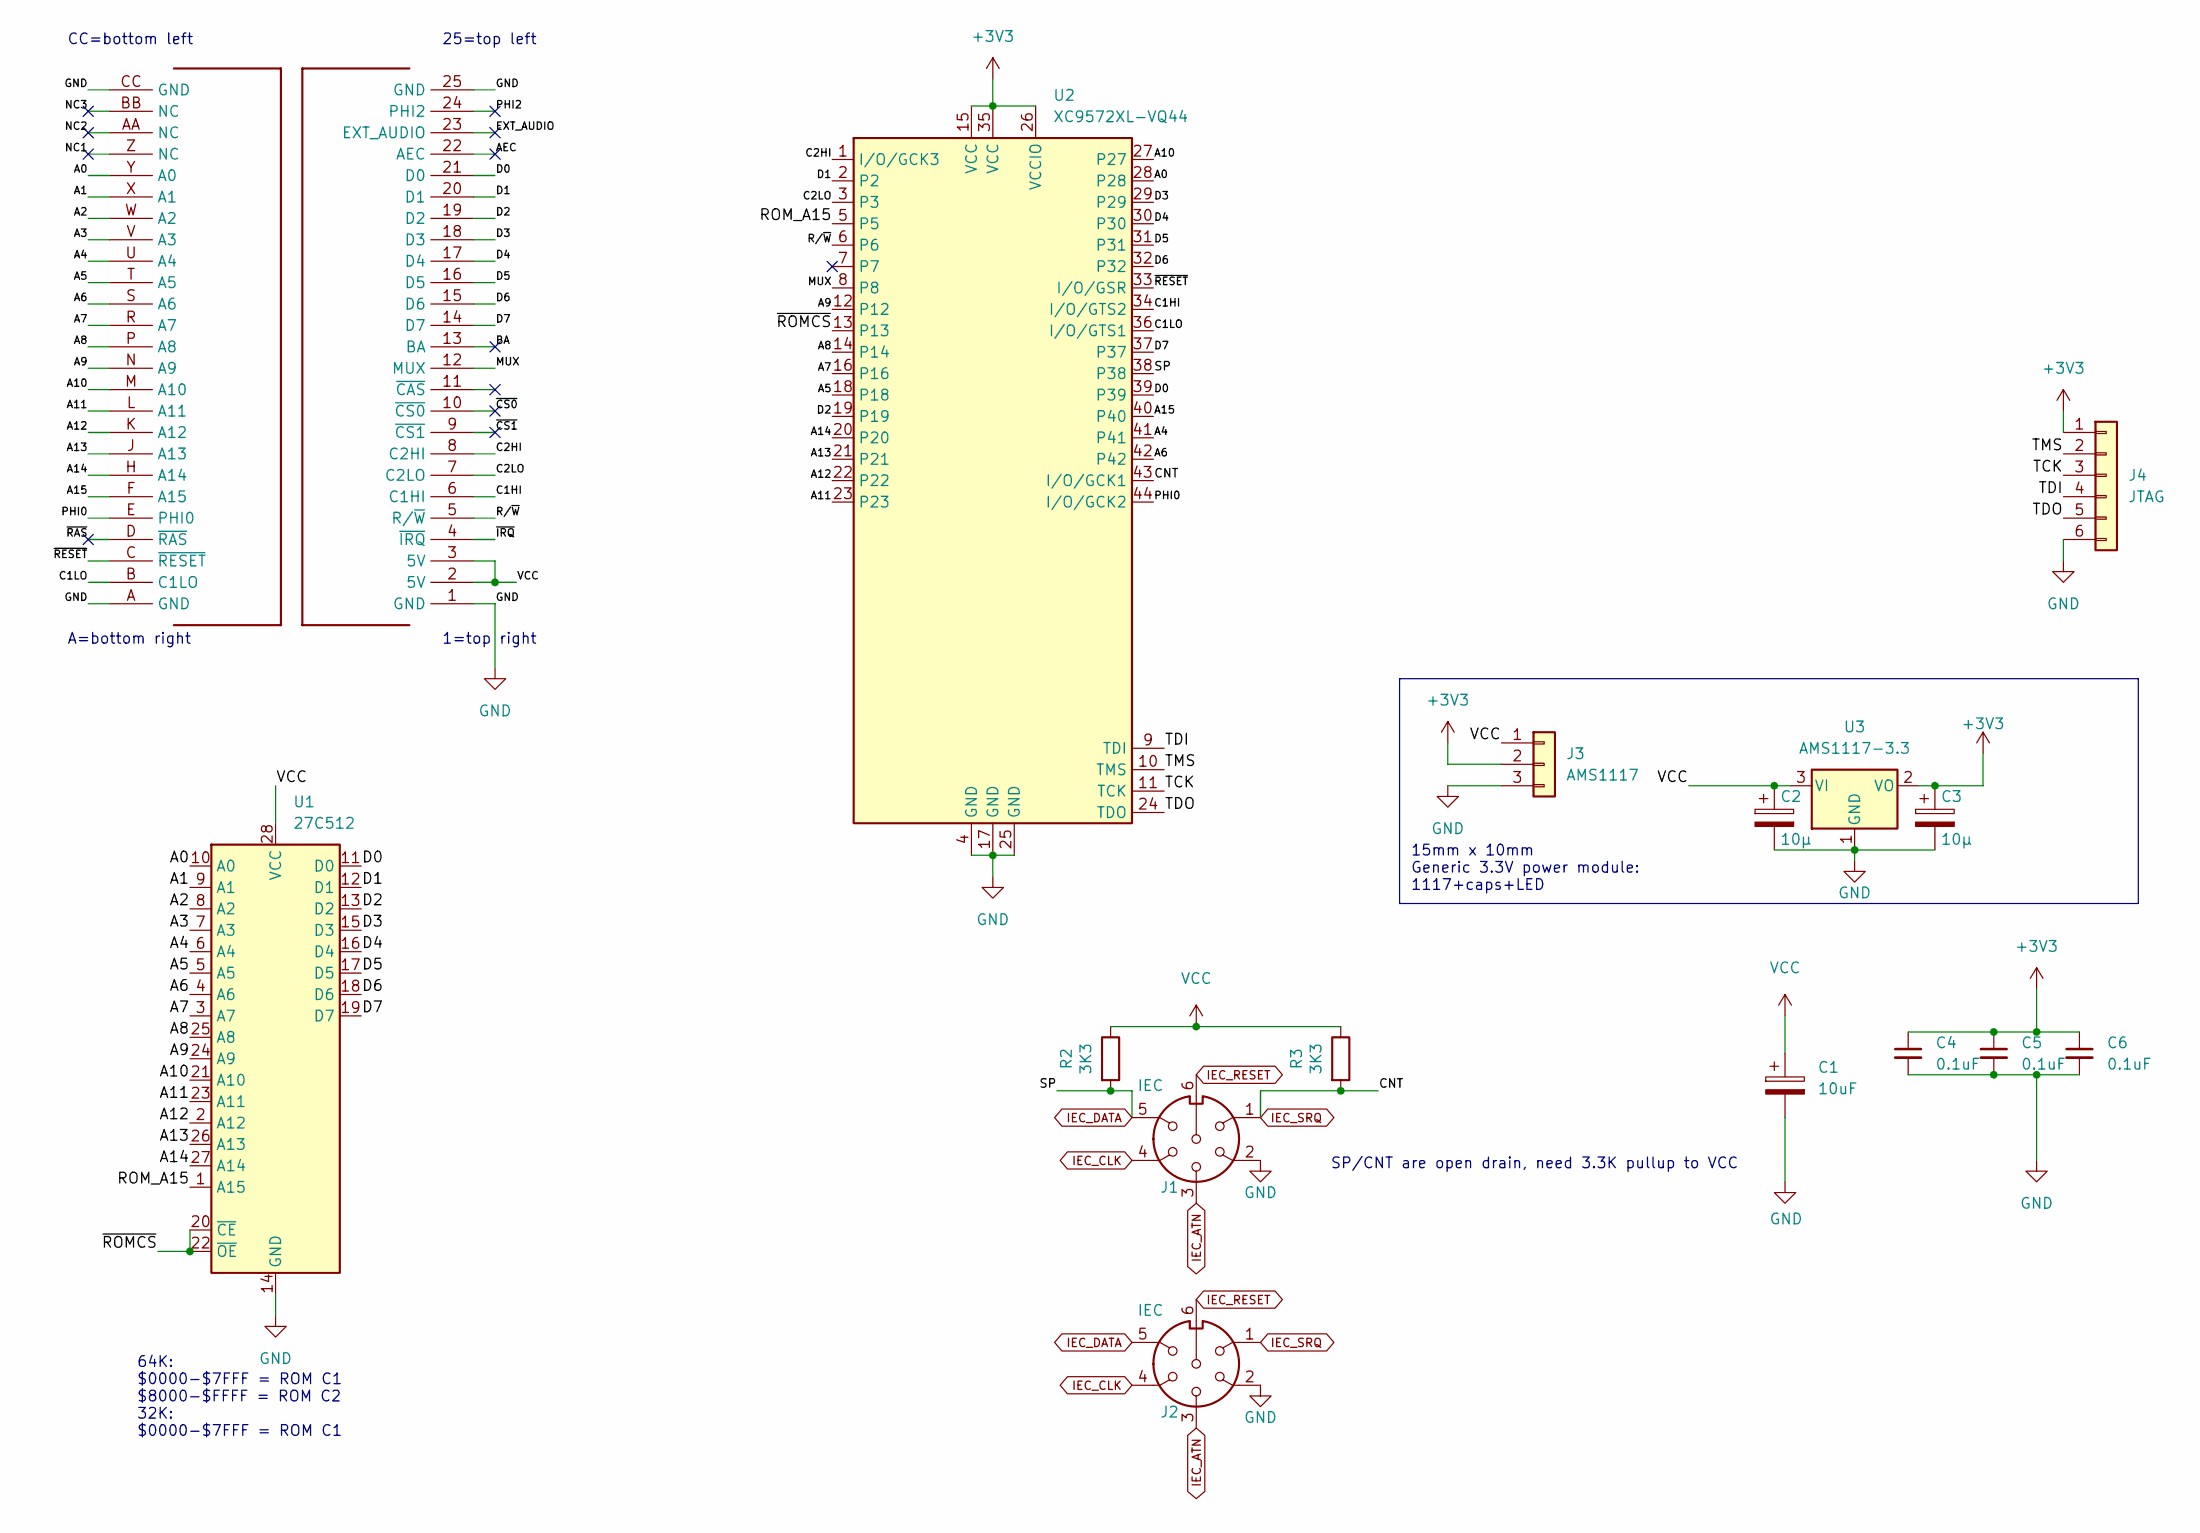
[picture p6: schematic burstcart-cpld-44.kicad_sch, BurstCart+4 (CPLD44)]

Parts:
C1: 10uF; CP_Radial_D5.0mm_P2.00mm
C2, C3: 10µ; CP_EIA-3216-12_Kemet-S_Pad1.58x1.35mm_HandSolder; JLCPCB Part # C1969735
C4, C5, C6: 0.1uF; C_0805_2012Metric_Pad1.18x1.45mm_HandSolder; JLCPCB Part # C49678
J1, J2: IEC; DIN6
J3: AMS1117; PinHeader_1x03_P2.54mm_Vertical
J4: JTAG; PinHeader_1x06_P2.54mm_Vertical
R2, R3: 3K3; R_0805_2012Metric_Pad1.20x1.40mm_HandSolder
U1: 27C512; DIP-28_W15.24mm_Socket
U2: XC9572XL-VQ44; TQFP-44_10x10mm_P0.8mm
U3: AMS1117-3.3; SOT-223-3_TabPin2; JLCPCB Part # C6186
U$1: C16_CARTRIDGE; C16_CART

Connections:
+3V3: C3.1, C4.1, C5.1, C6.1, J3.2, J4.1, U2.15 (VCC), U2.26 (VCCIO), U2.35 (VCC), U3.2 (VO)
/A0: U1.10 (A0), U2.28, U$1.Y (A0)
/A1: U1.9 (A1), U$1.X (A1)
/A2: U1.8 (A2), U$1.W (A2)
/A3: U1.7 (A3), U$1.V (A3)
/A4: U1.6 (A4), U2.41, U$1.U (A4)
/A5: U1.5 (A5), U2.18, U$1.T (A5)
/A6: U1.4 (A6), U2.42, U$1.S (A6)
/A7: U1.3 (A7), U2.16, U$1.R (A7)
/A8: U1.25 (A8), U2.14, U$1.P (A8)
/A9: U1.24 (A9), U2.12, U$1.N (A9)
/A10: U1.21 (A10), U2.27, U$1.M (A10)
/A11: U1.23 (A11), U2.23, U$1.L (A11)
/A12: U1.2 (A12), U2.22, U$1.K (A12)
/A13: U1.26 (A13), U2.21, U$1.J (A13)
/A14: U1.27 (A14), U2.20, U$1.H (A14)
/A15: U2.40, U$1.F (A15)
/AEC: U$1.22 (AEC)
/BA: U$1.13 (BA)
/C1HI: U2.34 (I/O/GTS2), U$1.6 (C1HI)
/C1LO: U2.36 (I/O/GTS1), U$1.B (C1LO)
/C2HI: U2.1 (I/O/GCK3), U$1.8 (C2HI)
/C2LO: U2.3, U$1.7 (C2LO)
/D0: U1.11 (D0), U2.39, U$1.21 (D0)
/D1: U1.12 (D1), U2.2, U$1.20 (D1)
/D2: U1.13 (D2), U2.19, U$1.19 (D2)
/D3: U1.15 (D3), U2.29, U$1.18 (D3)
/D4: U1.16 (D4), U2.30, U$1.17 (D4)
/D5: U1.17 (D5), U2.31, U$1.16 (D5)
/D6: U1.18 (D6), U2.32, U$1.15 (D6)
/D7: U1.19 (D7), U2.37, U$1.14 (D7)
/EXT_AUDIO: U$1.23 (EXT_AUDIO)
/MUX: U2.8, U$1.12 (MUX)
/NC1: U$1.Z (NC)
/NC2: U$1.AA (NC)
/NC3: U$1.BB (NC)
/PHI0: U2.44 (I/O/GCK2), U$1.E (PHI0)
/PHI2: U$1.24 (PHI2)
/ROM_A15: U1.1 (A15), U2.5
/R/~W: U2.6, U$1.5 (R/~W)
/TCK: J4.3, U2.11 (TCK)
/TDI: J4.4, U2.9 (TDI)
/TDO: J4.5, U2.24 (TDO)
/TMS: J4.2, U2.10 (TMS)
/~CS0: U$1.10 (~CS0)
/~CS1: U$1.9 (~CS1)
/~IRQ: U$1.4 (~IRQ)
/~RAS: U$1.D (~RAS)
/~RESET: U2.33 (I/O/GSR), U$1.C (~RESET)
/~ROMCS: U1.20 (~CE), U1.22 (~OE), U2.13
GND: C1.2, C2.2, C3.2, C4.2, C5.2, C6.2, J1.2, J2.2, J3.3, J4.6, U1.14 (GND), U2.4 (GND), U2.17 (GND), U2.25 (GND), U3.1 (GND), U$1.1 (GND), U$1.25 (GND), U$1.A (GND), U$1.CC (GND)
IEC_ATN: J1.3, J2.3
IEC_CLK: J1.4, J2.4
IEC_DATA: J1.5, J2.5, R2.2, U2.38
IEC_RESET: J1.6, J2.6
IEC_SRQ: J1.1, J2.1, R3.2, U2.43 (I/O/GCK1)
VCC: C1.1, C2.1, J3.1, R2.1, R3.1, U1.28 (VCC), U3.3 (VI), U$1.2 (5V), U$1.3 (5V)

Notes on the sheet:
25=top left
A=bottom right
SP/CNT are open drain, need 3.3K pullup to VCC
CC=bottom left
15mm x 10mm Generic 3.3V power module: 1117+caps+LED
1=top right
64K: $0000-$7FFF = ROM C1 $8000-$FFFF = ROM C2 32K: $0000-$7FFF = ROM C1

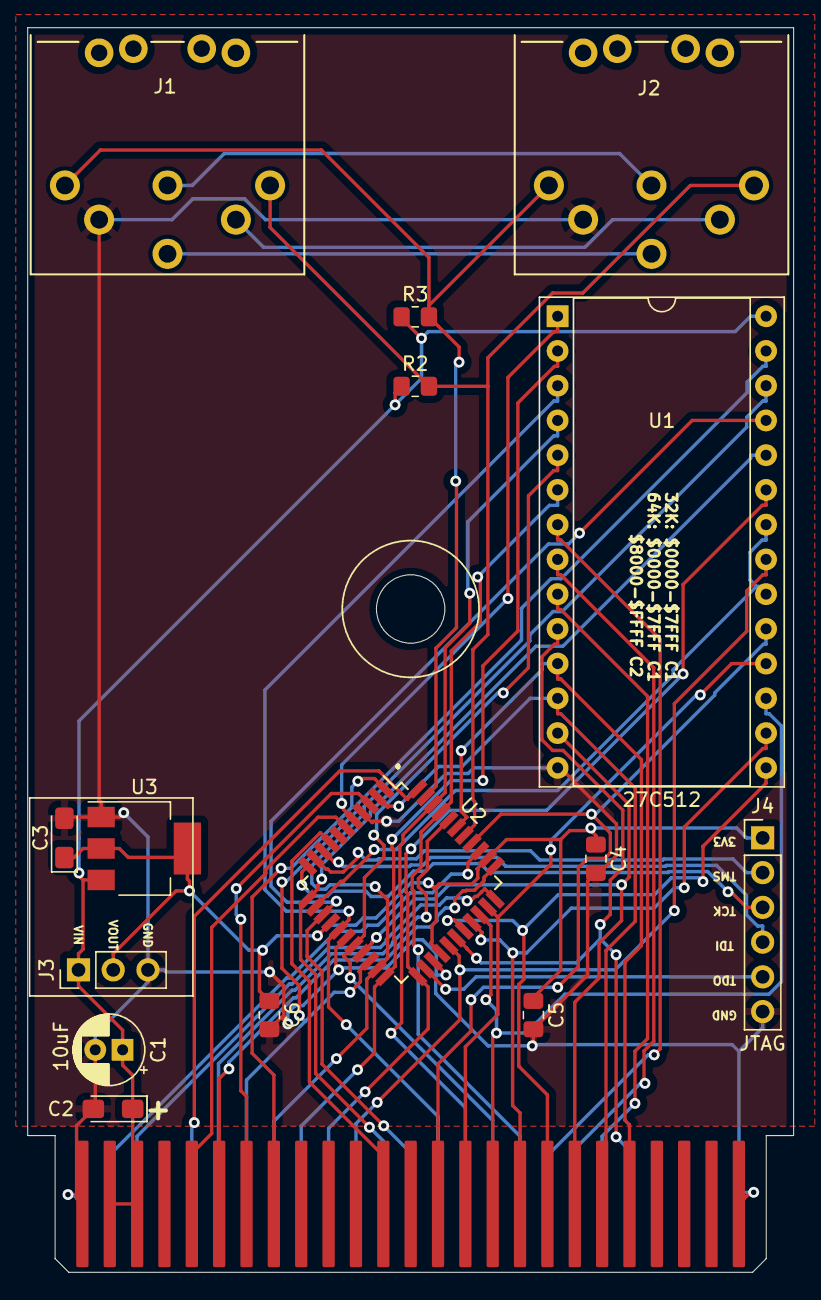
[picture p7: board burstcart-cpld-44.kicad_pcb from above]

Board: 2 copper layers, 56.0 x 91.0 mm, 16 parts (0 on the bottom side), 46 nets.

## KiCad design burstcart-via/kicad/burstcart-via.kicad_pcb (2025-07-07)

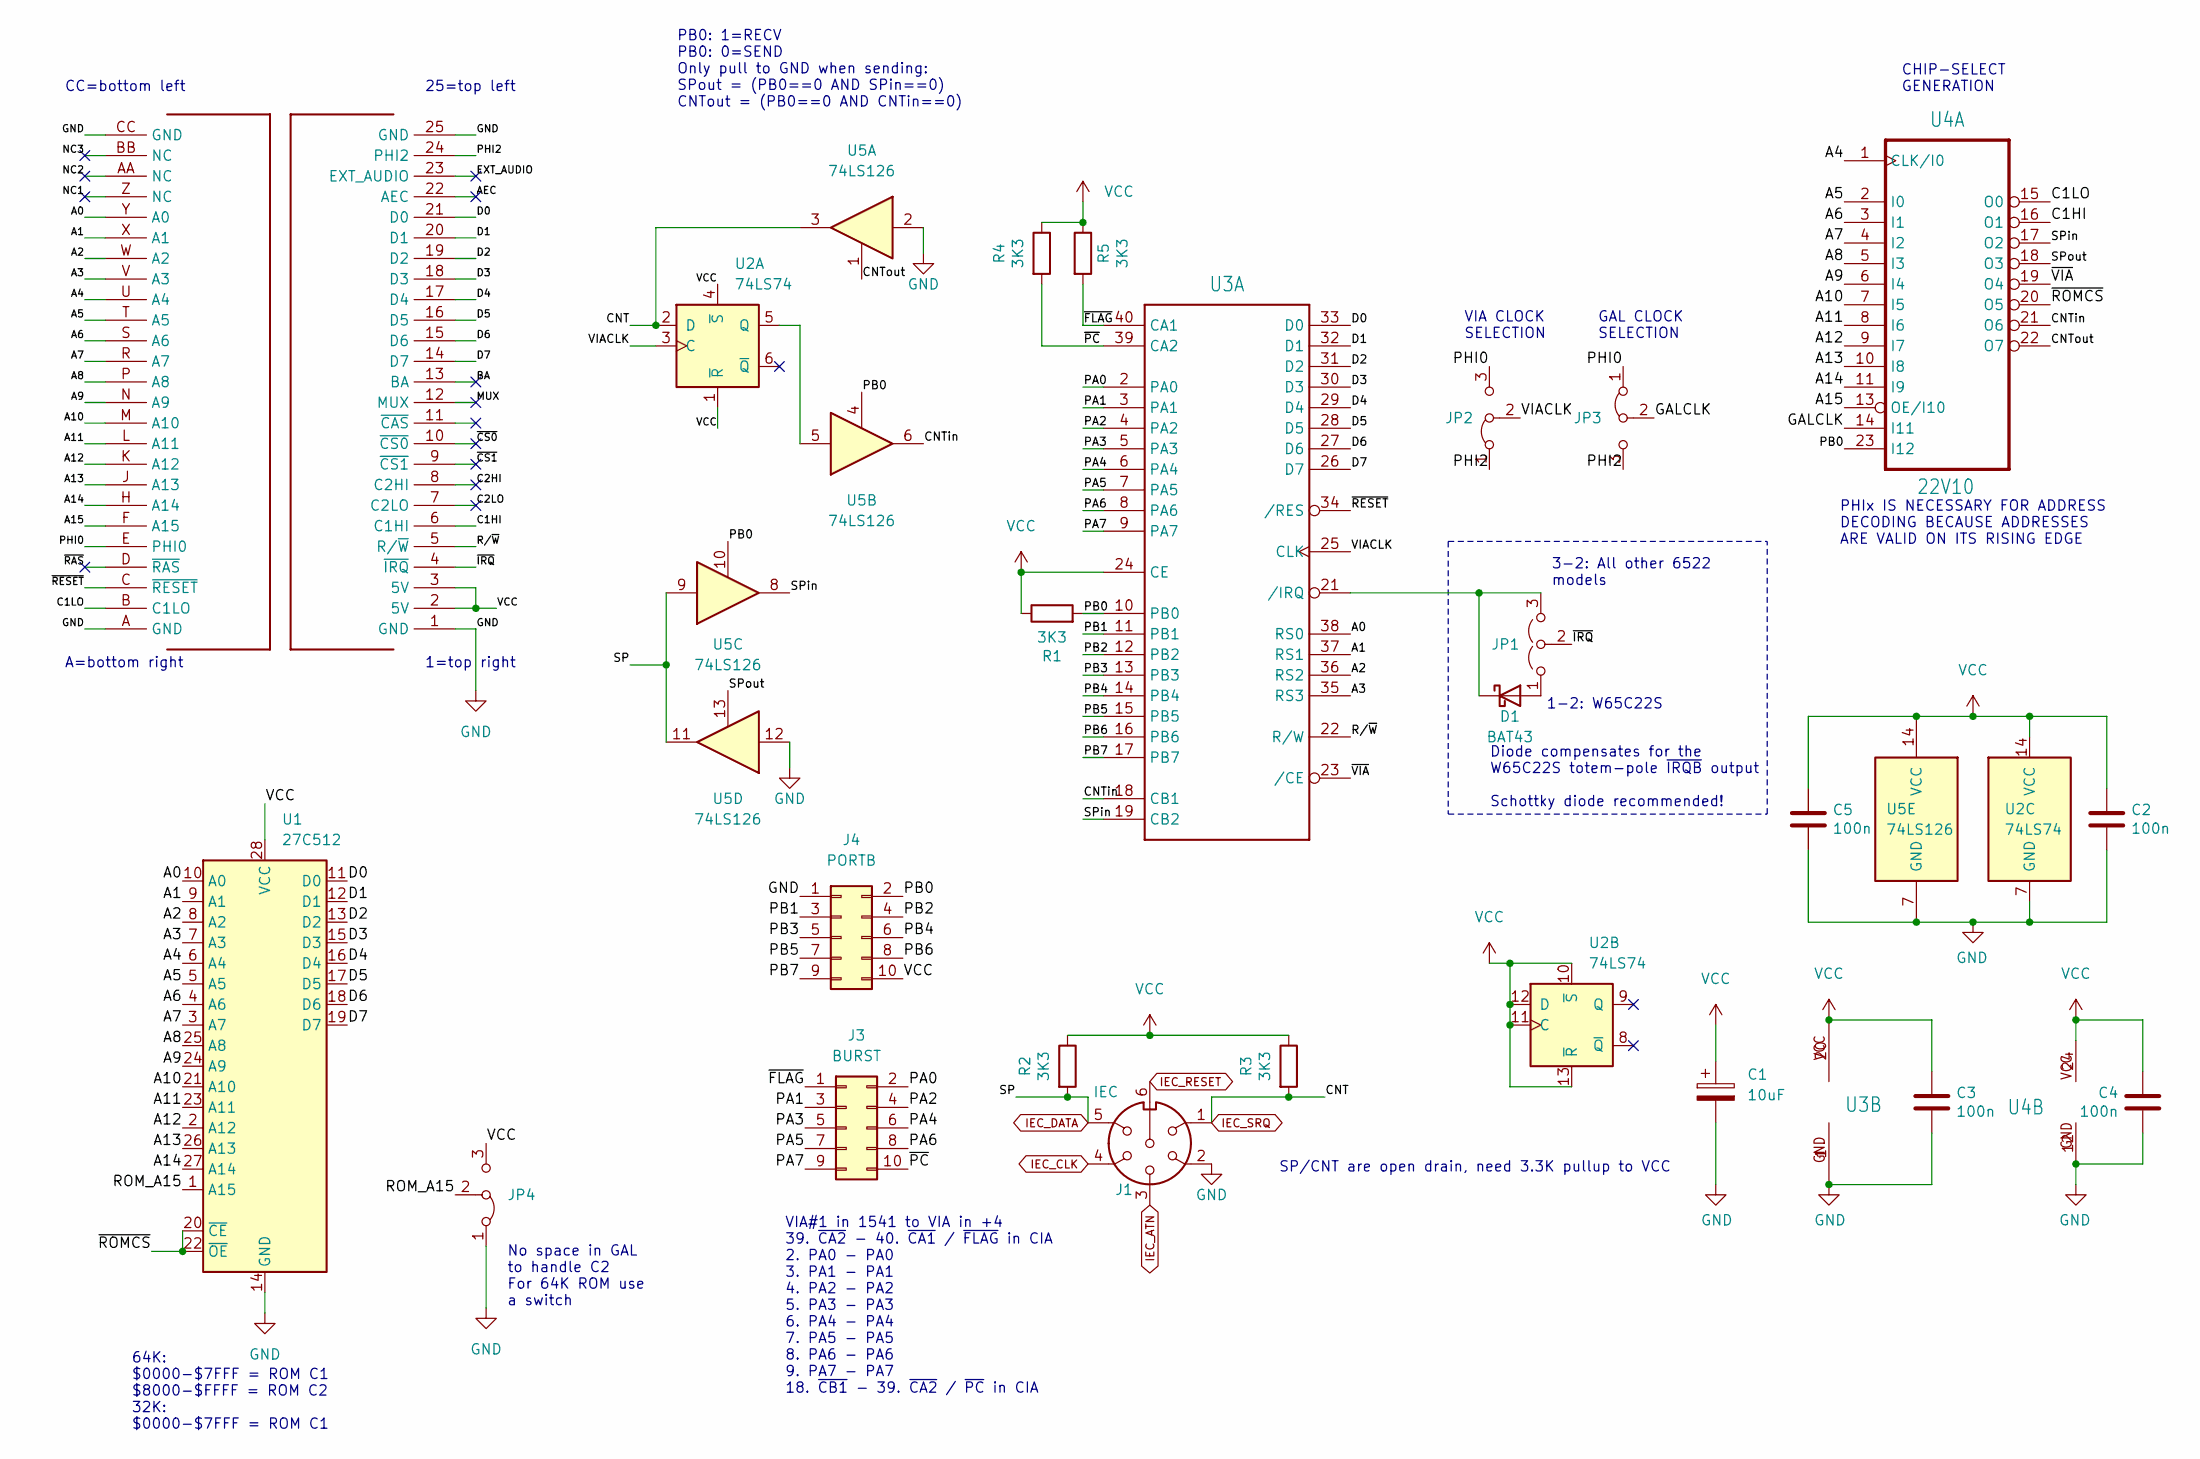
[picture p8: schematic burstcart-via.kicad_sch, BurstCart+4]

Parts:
C1: 10uF; CP_Radial_D5.0mm_P2.00mm
C2, C3, C4, C5: 470p; C_Disc_D7.0mm_W2.5mm_P5.00mm; MouserPN 810-FG28C0G1H471JNT6
D1: BAT43; D_DO-35_SOD27_P7.62mm_Horizontal
J1: IEC; DIN6
J3: BURST; PinHeader_2x05_P2.54mm_Vertical
J4: PORTB; PinHeader_2x05_P2.54mm_Vertical
JP1: Jumper_3_Open; SolderJumper-3_P1.3mm_Open_RoundedPad1.0x1.5mm_NumberLabels
JP2, JP3: Jumper_3_Bridged12; SolderJumper-3_P1.3mm_Bridged12_Pad1.0x1.5mm_NumberLabels
JP4: Jumper_3_Bridged12; PinHeader_1x03_P2.54mm_Vertical
R1, R2, R3, R4, R5: 3K3; R_Axial_DIN0207_L6.3mm_D2.5mm_P10.16mm_Horizontal
U1: 27C512; DIP-28_W15.24mm_Socket
U2: 74LS74; DIP-14_W7.62mm_Socket
U3: 6522; DIP-40_W15.24mm_Socket
U4: 22V10; DIP-24_W7.62mm_Socket
U5: 74LS126; DIP-14_W7.62mm_Socket
U$1: C16_CARTRIDGE; C16_CART

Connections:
/A0: U1.10 (A0), U3.38 (RS0), U$1.Y (A0)
/A1: U1.9 (A1), U3.37 (RS1), U$1.X (A1)
/A2: U1.8 (A2), U3.36 (RS2), U$1.W (A2)
/A3: U1.7 (A3), U3.35 (RS3), U$1.V (A3)
/A4: U1.6 (A4), U4.1 (CLK/I0), U$1.U (A4)
/A5: U1.5 (A5), U4.2 (I0), U$1.T (A5)
/A6: U1.4 (A6), U4.3 (I1), U$1.S (A6)
/A7: U1.3 (A7), U4.4 (I2), U$1.R (A7)
/A8: U1.25 (A8), U4.5 (I3), U$1.P (A8)
/A9: U1.24 (A9), U4.6 (I4), U$1.N (A9)
/A10: U1.21 (A10), U4.7 (I5), U$1.M (A10)
/A11: U1.23 (A11), U4.8 (I6), U$1.L (A11)
/A12: U1.2 (A12), U4.9 (I7), U$1.K (A12)
/A13: U1.26 (A13), U4.10 (I8), U$1.J (A13)
/A14: U1.27 (A14), U4.11 (I9), U$1.H (A14)
/A15: U4.13 (OE/I10), U$1.F (A15)
/AEC: U$1.22 (AEC)
/BA: U$1.13 (BA)
/C1HI: U4.16 (O1), U$1.6 (C1HI)
/C1LO: U4.15 (O0), U$1.B (C1LO)
/C2HI: U$1.8 (C2HI)
/C2LO: U$1.7 (C2LO)
/CNTin: U3.18 (CB1), U4.21 (O6), U5.6
/CNTout: U4.22 (O7), U5.1
/D0: U1.11 (D0), U3.33 (D0), U$1.21 (D0)
/D1: U1.12 (D1), U3.32 (D1), U$1.20 (D1)
/D2: U1.13 (D2), U3.31 (D2), U$1.19 (D2)
/D3: U1.15 (D3), U3.30 (D3), U$1.18 (D3)
/D4: U1.16 (D4), U3.29 (D4), U$1.17 (D4)
/D5: U1.17 (D5), U3.28 (D5), U$1.16 (D5)
/D6: U1.18 (D6), U3.27 (D6), U$1.15 (D6)
/D7: U1.19 (D7), U3.26 (D7), U$1.14 (D7)
/EXT_AUDIO: U$1.23 (EXT_AUDIO)
/GALCLK: JP3.2 (C), U4.14 (I11)
/MUX: U$1.12 (MUX)
/NC1: U$1.Z (NC)
/NC2: U$1.AA (NC)
/NC3: U$1.BB (NC)
/PA0: J3.2, U3.2 (PA0)
/PA1: J3.3, U3.3 (PA1)
/PA2: J3.4, U3.4 (PA2)
/PA3: J3.5, U3.5 (PA3)
/PA4: J3.6, U3.6 (PA4)
/PA5: J3.7, U3.7 (PA5)
/PA6: J3.8, U3.8 (PA6)
/PA7: J3.9, U3.9 (PA7)
/PB0: J4.2, R1.2, U3.10 (PB0), U4.23 (I12), U5.4, U5.10
/PB1: J4.3, U3.11 (PB1)
/PB2: J4.4, U3.12 (PB2)
/PB3: J4.5, U3.13 (PB3)
/PB4: J4.6, U3.14 (PB4)
/PB5: J4.7, U3.15 (PB5)
/PB6: J4.8, U3.16 (PB6)
/PB7: J4.9, U3.17 (PB7)
/PHI0: JP2.3 (B), JP3.1 (A), U$1.E (PHI0)
/PHI2: JP2.1 (A), JP3.3 (B), U$1.24 (PHI2)
/ROM_A15: JP4.2 (C), U1.1 (A15)
/R/~W: U3.22 (R/W), U$1.5 (R/~W)
/SPin: U3.19 (CB2), U4.17 (O2), U5.8
/SPout: U4.18 (O3), U5.13
/VIACLK: JP2.2 (C), U2.3 (C), U3.25 (CLK)
/~CS0: U$1.10 (~CS0)
/~CS1: U$1.9 (~CS1)
/~FLAG: J3.1, R5.2, U3.40 (CA1)
/~IRQ: JP1.2 (C), U$1.4 (~IRQ)
/~PC: J3.10, R4.2, U3.39 (CA2)
/~RAS: U$1.D (~RAS)
/~RESET: U3.34 (/RES), U$1.C (~RESET)
/~ROMCS: U1.20 (~CE), U1.22 (~OE), U4.20 (O5)
/~VIA: U3.23 (/CE), U4.19 (O4)
GND: C1.2, C2.2, C3.2, C4.2, C5.2, J1.2, J4.1, JP4.1 (A), U1.14 (GND), U2.7 (GND), U3.1 (GND), U4.12 (GND), U5.2, U5.7 (GND), U5.12, U$1.1 (GND), U$1.25 (GND), U$1.A (GND), U$1.CC (GND)
IEC_ATN: J1.3
IEC_CLK: J1.4
IEC_DATA: J1.5, R2.2, U5.9, U5.11
IEC_RESET: J1.6
IEC_SRQ: J1.1, R3.2, U2.2 (D), U5.3
unnamed: D1.2 (A), JP1.1 (A)
unnamed: D1.1 (K), JP1.3 (B), U3.21 (/IRQ)
unnamed: U2.5 (Q), U5.5
VCC: C1.1, C2.1, C3.1, C4.1, C5.1, J4.10, JP4.3 (B), R1.1, R2.1, R3.1, R4.1, R5.1, U1.28 (VCC), U2.1 (~R), U2.4 (~S), U2.10 (~S), U2.11 (C), U2.12 (D), U2.13 (~R), U2.14 (VCC), U3.20 (VCC), U3.24 (CE), U4.24 (VCC), U5.14 (VCC), U$1.2 (5V), U$1.3 (5V)

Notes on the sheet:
25=top left
Diode compensates for the W65C22S totem-pole ~{IRQB} output Schottky diode recommended!
VIA CLOCK SELECTION
1-2: W65C22S
A=bottom right
SP/CNT are open drain, need 3.3K pullup to VCC
VIA#1 in 1541 to VIA in +4 39. ~{CA2} - 40. ~{CA1} / ~{FLAG} in CIA 2. PA0 - PA0 3. PA1 - PA1 4. PA2 - PA2 5. PA3 - PA3 6. PA4 - PA4 7. PA5 - PA5 8. PA6 - PA6 9. PA7 - PA7 18. ~{CB1} - 39. ~{CA2} / ~{PC} in CIA
PB0: 1=RECV PB0: 0=SEND Only pull to GND when sending: SPout = (PB0==0 AND SPin==0) CNTout = (PB0==0 AND CNTin==0)
GAL CLOCK SELECTION
CHIP-SELECT GENERATION
CC=bottom left
No space in GAL to handle C2 For 64K ROM use a switch
3-2: All other 6522 models
1=top right
PHIx IS NECESSARY FOR ADDRESS DECODING BECAUSE ADDRESSES ARE VALID ON ITS RISING EDGE
64K: $0000-$7FFF = ROM C1 $8000-$FFFF = ROM C2 32K: $0000-$7FFF = ROM C1

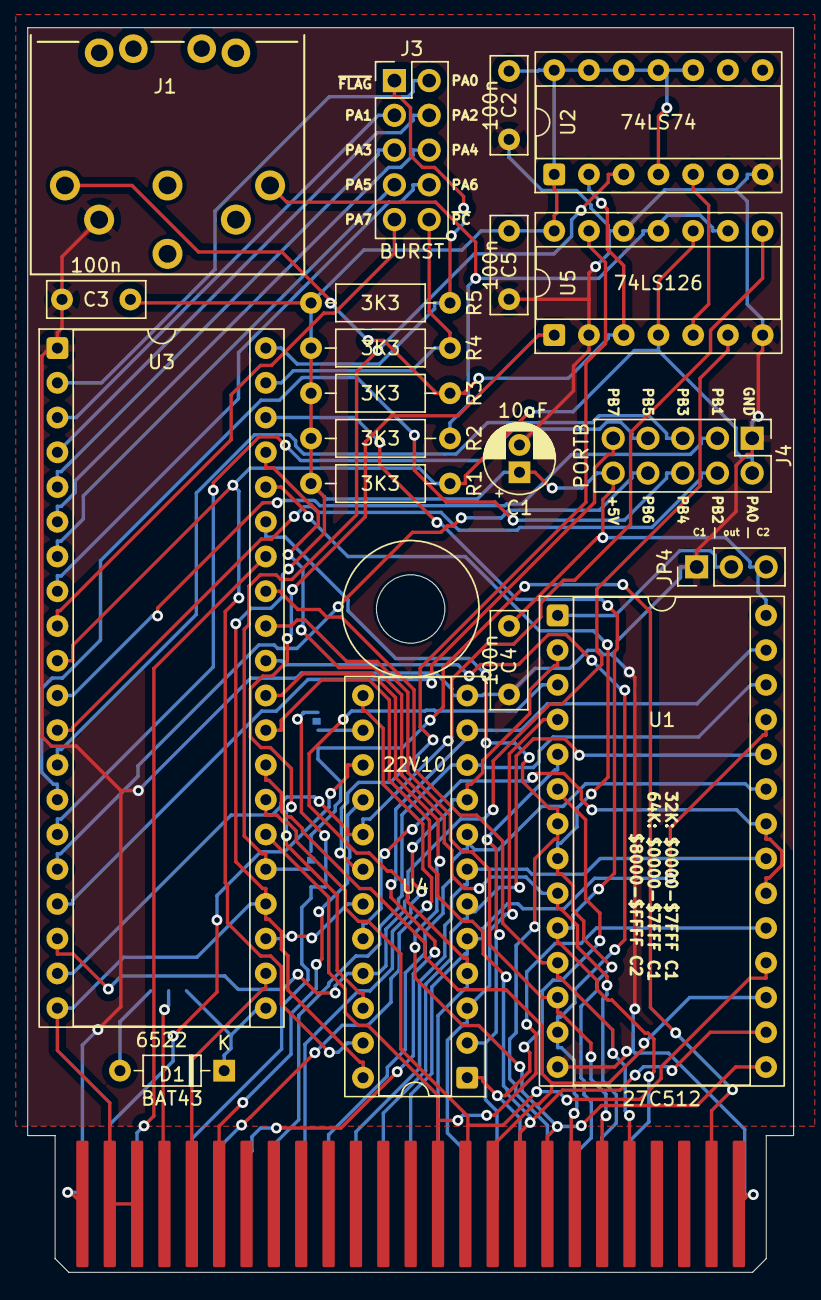
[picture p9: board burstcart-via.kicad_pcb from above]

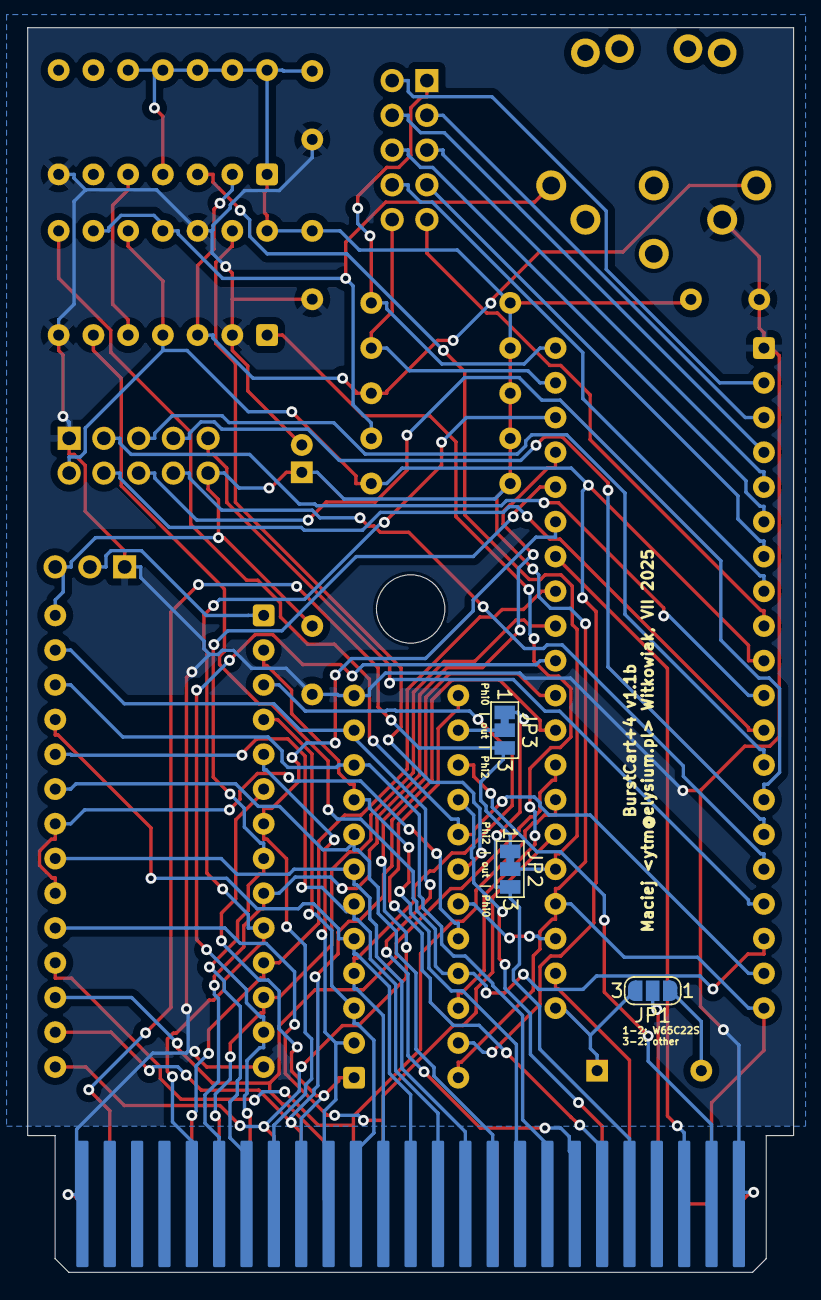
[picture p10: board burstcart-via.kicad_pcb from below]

Board: 2 copper layers, 56.0 x 91.0 mm, 24 parts (3 on the bottom side), 65 nets.

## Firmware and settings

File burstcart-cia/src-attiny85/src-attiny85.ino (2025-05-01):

// IDE: ATtiny25/45/85, internal 1MHz
// 1MHz is the default speed, no need to switch fuses to 8MHz
// compile to HEX (Sketch->Export compiled binary) and burn using TL866-II

// pinout
//                                /RESET 1  U  8 5V
// -- selector (floating or GND)  A3/PB3 2     7 A1/2/PB2
//                                A2/PB4 3     6 PB1 PWM
//                                   GND 4     5 PB0 PWM -- output PWM 50Hz

/* -D CKDIV8
board = attiny85
board_build.f_cpu = 1000000L
board_fuses.lfuse = 0x62
board_fuses.hfuse = 0xdf
board_fuses.efuse = 0xff
*/

const uint8_t PWM_pin = 0; // PB0, pin 5
const uint8_t mode_pin = 3; // PB3, pin 2 - jumper to GND for NTSC mode, keep floating (internal pullup) for PAL
uint8_t half_duty = 10;    // 10ms for PAL, 8ms for NTSC = 20ms/16ms

// use PAL (50Hz) clock, otherwise we would have to maintain two ROM versions

// Define OCR0A values and prescaler based on CKDIV8
#if F_CPU == 1000000L
  // 1MHz clock settings
  #define PRESCALER_BITS ((1 << CS01) | (1 << CS00))  // Prescaler = 64
  #define OCR0A_50HZ     155  // 50Hz: 1MHz / (2*64*(155+1)) ≈ 50.08Hz
  #define OCR0A_60HZ     129  // 60Hz: 1MHz / (2*64*(129+1)) ≈ 60.1Hz
#else
  // 8MHz clock settings
  #define PRESCALER_BITS ((1 << CS02) | (1 << CS00))  // Prescaler = 1024
  #define OCR0A_50HZ     77   // 50Hz: 8MHz / (2*1024*(77+1)) ≈ 50.08Hz
  #define OCR0A_60HZ     64   // 60Hz: 8MHz / (2*1024*(64+1)) ≈ 60.14Hz
#endif

void setup() {
  pinMode(PWM_pin, OUTPUT);
  digitalWrite(PWM_pin, LOW);
  pinMode(mode_pin, INPUT_PULLUP);
  delay(200);
  if (digitalRead(mode_pin) == LOW) { // is it tied to GND? yes - use software clock
    while (true) {
      delay(half_duty); // 10ms - half of 20ms duty cycle
      digitalWrite(PWM_pin, HIGH);
      delay(half_duty); // 10ms - half of 20ms duty cycle
      digitalWrite(PWM_pin, LOW);
    }
  }
  // otherwise use h/w clock
    DDRB |= (1 << PB0);    // PB0 (OC0A) as output

    // Configure Timer0 for CTC mode (toggle OC0A on compare match)
    TCCR0A = (1 << COM0A0) | (1 << WGM01);  // Toggle OC0A, CTC mode
    TCCR0B = PRESCALER_BITS;  // Set prescaler (64 or 1024)
    OCR0A = OCR0A_50HZ;

    while (1) { }
}

void loop() {
  // could be done using PWM and clock prescalers, but that is good enough for me
}

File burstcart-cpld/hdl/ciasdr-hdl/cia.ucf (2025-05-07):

#PINLOCK_BEGIN

#Tue May  6 21:35:47 2025

NET "A<0>"           LOC =  "S:PIN28";
NET "A<10>"          LOC =  "S:PIN27";
NET "A<11>"          LOC =  "S:PIN23";
NET "A<12>"          LOC =  "S:PIN22";
NET "A<13>"          LOC =  "S:PIN21";
NET "A<14>"          LOC =  "S:PIN20";
NET "A<15>"          LOC =  "S:PIN40";
NET "A<4>"           LOC =  "S:PIN41";
NET "A<5>"           LOC =  "S:PIN18";
NET "A<6>"           LOC =  "S:PIN42";
NET "A<7>"           LOC =  "S:PIN16";
NET "A<8>"           LOC =  "S:PIN14";
NET "A<9>"           LOC =  "S:PIN12";
NET "E_CLK"          LOC =  "S:PIN44";
NET "MUX"            LOC =  "S:PIN8";
NET "RESET_n"        LOC =  "S:PIN33";
NET "RW"             LOC =  "S:PIN6";
NET "c1hi"           LOC =  "S:PIN34";
NET "c1lo"           LOC =  "S:PIN36";
NET "c2hi"           LOC =  "S:PIN1";
NET "c2lo"           LOC =  "S:PIN3";
NET "SP"             LOC =  "S:PIN38";
NET "CNT"            LOC =  "S:PIN43";
NET "D<0>"           LOC =  "S:PIN39";
NET "D<1>"           LOC =  "S:PIN2";
NET "D<2>"           LOC =  "S:PIN19";
NET "D<3>"           LOC =  "S:PIN29";
NET "D<4>"           LOC =  "S:PIN30";
NET "D<5>"           LOC =  "S:PIN31";
NET "D<6>"           LOC =  "S:PIN32";
NET "D<7>"           LOC =  "S:PIN37";
NET "rom_a15"        LOC =  "S:PIN5";
NET "rom_cs"         LOC =  "S:PIN13";
#PINLOCK_END

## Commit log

2025-05-01 remarks about changes for v1.1
    [burstcart.kicad_sch]
2025-05-01 - +5V net removed, all is VCC now - /CIA is pin 19, /ROM_A15 pin 22 now - default jumper shorted to reset CD4520 - default jumper shorted to phi2 for CIACLK - GAL is 22V10 - removed MUX connection to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
    [burstcart.kicad_pcb, burstcart.kicad_sch]
2025-05-02 renamed burstcart to burstcart-cia
    [burstcart-B_Cu.gbl, burstcart-B_Mask.gbs, burstcart-B_Paste.gbp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]
2025-05-06 PCB for VIA option
    [burstcart-via.kicad_pcb, burstcart-via.kicad_sch]
2025-05-06 https://github.com/niklasekstrom/cia-verilog/blob/master/cia.v trimmed down to CPLD
    [compxlib.cfg]
2025-05-06 locked pins in UCF file, set smaller device to VQ44
2025-05-06 KiCad project for xc9572xl-vq44 (cpld-44)
    [burstcart-cpld-44.kicad_pcb, burstcart-cpld-44.kicad_sch]
2025-05-07 finalized VIA board
    [burstcart-via-B_Cu.gbl, burstcart-via-B_Mask.gbs, burstcart-via-B_Paste.gbp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]
2025-05-07 finalized CPLD (VQ44) board
    [burstcart-cpld-44-B_Cu.gbl, burstcart-cpld-44-B_Mask.gbs, burstcart-cpld-44-B_Paste.gbp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]
2025-05-07 finalized v1.1 cia board too
    [burstcart-B_Cu.gbl, burstcart-B_Mask.gbs, burstcart-B_Paste.gbp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]
2025-05-07 check for TCBM device and fall back on ROM if detected
2025-05-29 timer reduced to 1 bit
2025-06-08 reorganize project folders into -cia, -via, -cpld44
    [burstcart-B_Cu.gbl, burstcart-B_Mask.gbs, burstcart-B_Paste.gbp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]
2025-06-20 @8 thru @19 to set current device number
2025-06-24 detect 1541 with parallel cable and parallel cable interface (PIO/PPI/VIA/CIA)
2025-06-29 preserve X (next track number)
2025-06-29 assemble and choose CIA/VIA version
2025-07-01 device not present check
2025-07-01 make '$' use current drive
2025-07-01 make '/' load from current drive, to file loadaddress
2025-07-07 corrected JP4 to connect to Phi0 by default, corrected silkscreen texts ; updated to KiCad9
    [burstcart-via-B_Cu.gbl, burstcart-via-B_Mask.gbs, burstcart-via-B_Paste.gbp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]
2026-07-26 directory rename
    [burstcart-cpld-44-B_Cu.gbl, burstcart-cpld-44-B_Mask.gbs, burstcart-cpld-44-B_Paste.gbp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]
